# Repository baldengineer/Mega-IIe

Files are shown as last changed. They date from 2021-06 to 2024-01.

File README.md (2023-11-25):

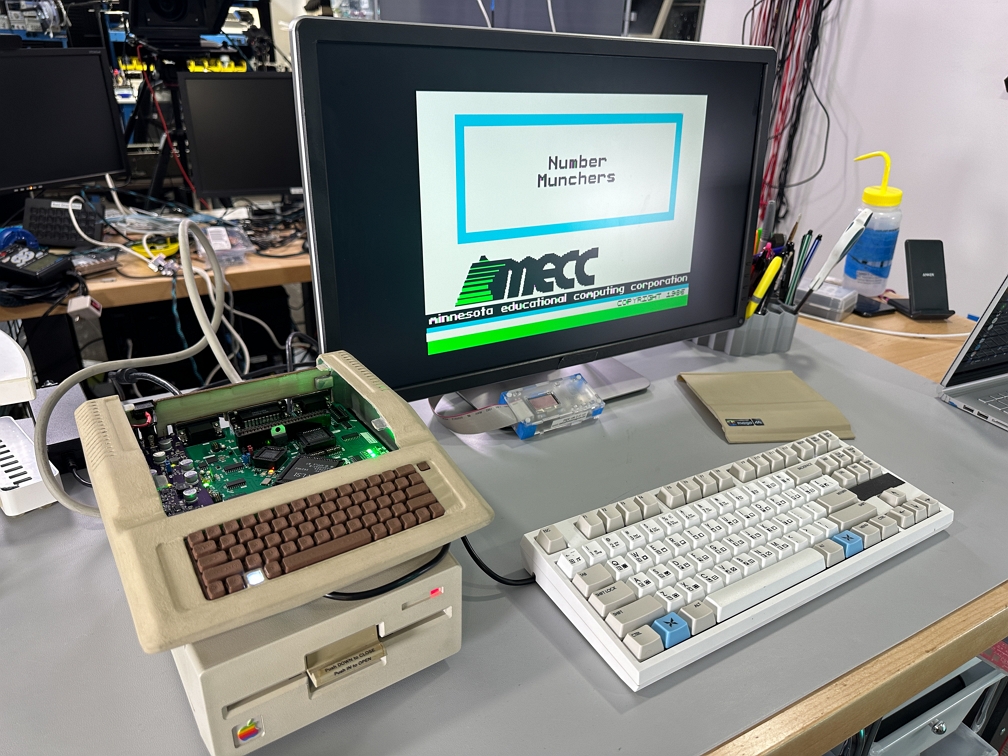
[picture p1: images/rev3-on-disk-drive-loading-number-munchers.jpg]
Mega IIe Rev 3 loading Number Munchers


# Golden Delicious
This project started as a portable Apple ][ by using the Mega-II chip from an IIGS. (This chip is precursor, and slightly different to the Gemini in the Mac LC compatibility card.) However, it evolved into making a miniture Apple IIe compatible computer.

This repo contains the KiCad design files, RP2040 firmware, and notes for the Mega IIe computer. 

## Rev 3 Video
This element14 Presents video documents the effort to get from an Applesoft Prompt to a fully functional computer, in a miniature case.

https://www.youtube.com/watch?v=gFCD4s_hsb4

You can find additional information on the [element14 Community](https://bald.ee/e14-megaiie) or in this [Hackster.io](https://www.hackster.io/news/bald-engineer-s-mega-iie-is-a-modern-miniature-apple-ii-based-on-mega-ii-chip-from-1986-019507d4d10c) article. 

## Bit Preserve
This project is why I started [Bit Preserve](https://github.com/baldengineer/bit-preserve), a project to archive vintage computer schematics.

# Notes
When live streaming the probject, I kept some notes here for future reference.

## (Off-)Stream Notes 2021-10-02
* Attempting to book the GD with a IIc ROM results in a lock-up.
  * graphics get initialized and the memory is dumped to the screen, but no beep and nothing past that.
  * Logic Analyzer suggests `BASICINIT` is doing a monitor version check in the F8 ROM, but failing. It calls a jump called `HANG`. Even though the 6502 should be jumping in a circle, it seems to keep doing other stuff. (Maybe it is just bus fetches that do nothing?)
* SLOTMAKER Bus Headers on the IO board are pinned out different from the SLOTMAKER Bus Header on the MEGA-65c02. For a ribbon cable, each pin-pair needs to be swapped, except for the last two. They are GND.

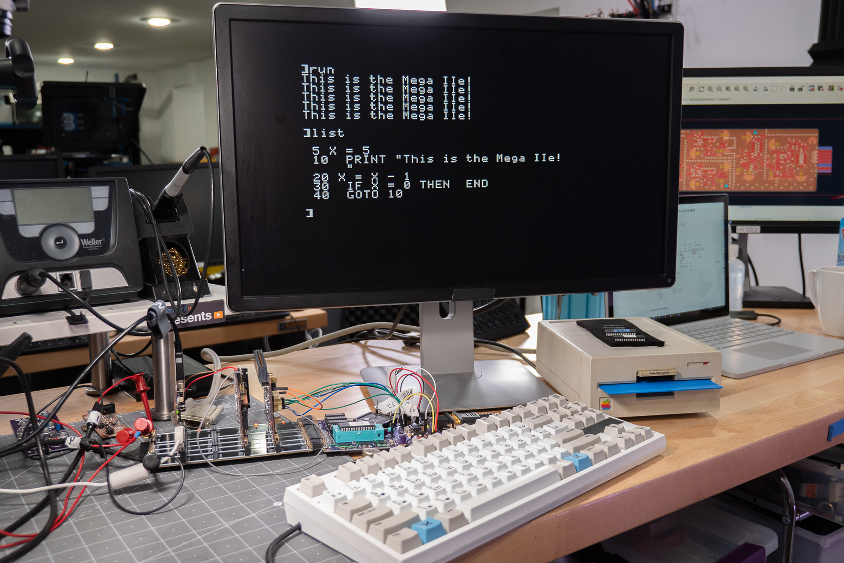
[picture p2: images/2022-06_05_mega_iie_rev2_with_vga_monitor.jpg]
demo of Mega IIe running AppleSoft


## Stream Notes 2021-10-01
Golden Delicious Rev 2 booted! Yay!

* \~DMA is wrong level
  * The two \`245 buffers have their enable pins connnected to \~DMA. I made the mistake of thinking that MEGA drove the \~DMA signal. That is not the case, nor does it make sense after thinking about it. For now, the \`245s have pin 19 lifted and tied to ground to always enable them. 
  * When connecting the IWM or a card to slotmaker, \~DMA situation needs to be resolved.

* [IIe / 6502 decoder](https://discord.com/channels/369243434080272385/843878836471201902/893914917676130314) for Waveforms / Digitial Discovery has been updated. 
* This [forum post](https://discord.com/channels/369243434080272385/843878836471201902/893915436620607488) has Digilent Waveforms beta builds that are downloadable without filling out the annoying registration form. (Or just use `asdf` for all of the fields.)

## Stream Notes 2021-06-02
* Wherefore no IIe ROM in the IIgs? Is it in the MEGA-II?
* [Warphammer: this seciton looks rommy](https://twitter.com/babbageboole/status/1001178057057566720/photo/1)
* rjhelms: that's the big question mark - there could be logic in the Mega II that never actually gets used because the CYA is doing it all in this implementation
* al: keep it all breakouts
* can we decode ROMEN1 and ROMEN2 ourselves?

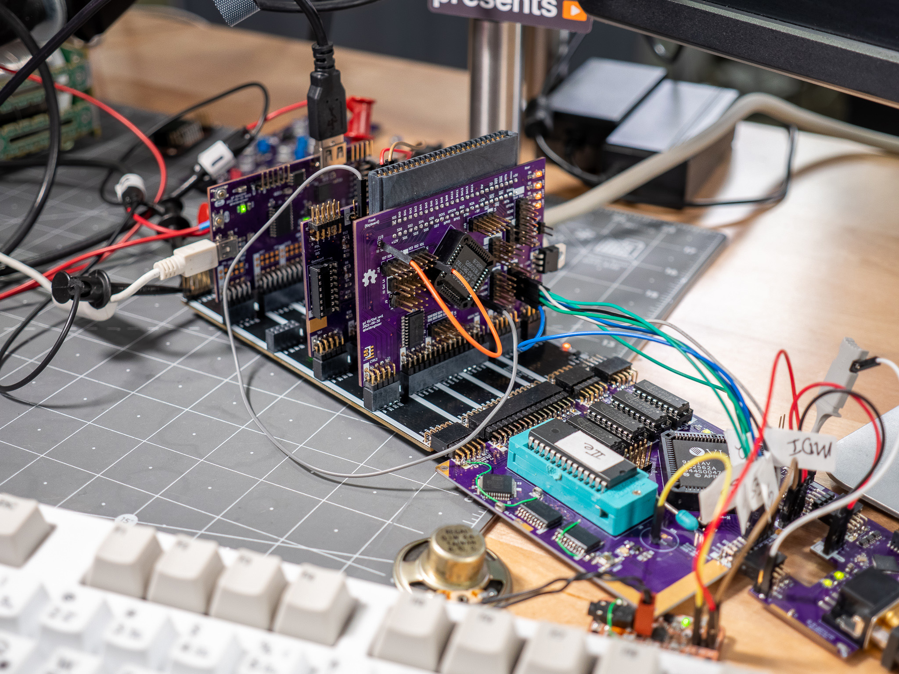
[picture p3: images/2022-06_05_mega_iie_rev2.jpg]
Mega IIe Rev2 Hardware


## Stream Notes 2021-05-19
Things to look at on the scope:
* Composite signal out of the Mega II
* What is Mono-Color from VGC doing to Chroma into MC1377
* Is VGC refreshing apple II DRAM (or is it the Mega)
* why is the 28 MHz oscillator enabled/disabled from the VGC's !SYNC pin?
* [PLCC Pinout Page](https://www.sbprojects.net/knowledge/footprints/plcc/index.php)

### Renesas / IDT OSC: XLH735028.636360I 
* XL H 7 3 5 0 28.636360 I 
  * XL = 1,000,000 af
  * H = LVCMOS En/Dis Pin 1
  * 7 = 7.0 x 5.0 mm
  * 3 = 3.3 VDC
  * 5 = 100ppm for -40C to 105C only on tuesdays when the moon is full and it hasn't rained for a few days. also if you ate green skittles recently *Note1*

### BoM for Protoboards
* [Possible MC1377 Source](https://www.ebay.com/itm/192523168043?hash=item2cd346692b:g:BgIAAOSwWfda4kj6)

## Stream Notes 2021-05-16
* [WDC Application note on using 65C02 in Apple II and other old systems](https://www.westerndesigncenter.com/wdc/AN-002_W65C02S_Replacements.php)
* [65C02 Datasheet](https://www.westerndesigncenter.com/wdc/documentation/w65c02s.pdf)

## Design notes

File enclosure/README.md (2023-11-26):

# Mega IIe STL Files
These are the STLs to re-print the Mega IIe enclosure.

This design is based on this [Apple IIe Model](https://grabcad.com/library/apple-iie-personal-computer-1) by Tommy Mueller on GrabCAD. That model only had faces, so it wasn't as simple as "download and print." And I had to make a few changes to accomodate putting real hardware inside.

## STLs
The final STL versions of each component. The names should be self-explanatory. 

Notes
* Glue (or tape) the Power LED to the back of the keyboard
* Glue the keyboard to the top case.
* Glue RESET key into place.
* Insert the floor panel (with PCB) before putting in the keyboard
* Insert a Speaker (I used one from a IIc) and then glue that piece to the back of the keyboard.

* There is a mix of 2, 3, and 3.5 mm heat inserts. 
* `Stand off for lid` offsets the case from the table for painting.

## Printing Notes
I printed on a Prusa MK3. I did all of the printing before PrusaSlicer supported organic supports.

* Main body needs tons of (traditional) supports. Takes >24 hours to print.
* Lid seemed to do best on its thin side. Otherwise, supports are a pain to clean off.
* Lid may also need to be scaled based on how much paint you add.

## Fusion 360
All of the CAD work was done in Autodesk's [Fusion 360 for personal](https://www.autodesk.com/products/fusion-360/personal).

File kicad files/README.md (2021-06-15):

## Golden Delicious KiCad Files

The Proto PCBs are boards to prototype an IIe from the IIgs ASICs. Eventually, these will be condensed to a single board.

### gd 6502 proto pcb
6502 board is designed for a WDC W65c02 with a QFP footprint. It has a single socket for an EPROM and is wired like the IIc's EEPROM. The `Address` and `Data` headers are meant to connect to the MEGA-II proto board. Other control signals are broken out to other headers.

Runs off of 5V.

### gd MegaII proto pcb
This board is the center piece. It contains the MEGA-II and has all of its signals broken out to multiple headers. 

It connects to both the VGC and 6502 boards. The VGC connects with a 40-pin cable, like an IDE cable. The 6502 connects with a couple of ribbon cables.

Runs off of 5V.

### gd VGC proto pcb
First board to be finished and the one with the least use for the final handheld. The VGC converts the RGB bitstream from the MEGA-II into an analog signal and then into NTSC.

The VGC also generates the 14 MHz clock from a 28 MHz oscilliator. (It is not clear yet which clocks the MEGA-II generates and which the VGC does.)

Runs off of +5V, -5V, and +12V. The 12V and -5V are used by the NTSC generation circuit.

### KiCad_Symbols
Late in the board creation process, I tried to consoliate the symbols into one location. These symbols and these boards are based off of the ROM3 IIgs schematic in [Bit Preserve](https://github.com/baldengineer/bit-preserve).

### MegaII Breakout
Very old breakout board. Created that and realized it wasn't very useful by itself.

## Live Stream
This entire project has been livestreamed on [Bald Engineer Live](https://twitch.tv/baldengineer).

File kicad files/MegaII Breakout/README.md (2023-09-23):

I quickly realized the MEGA-II by itself wasn't going to be a useful breakout. 

So, this board got replaced by the "gd MEGA-II" proto board.

(During KiCad 7 update, multiple symbols were lost. I tried to fix them, but the most recent schematic was not the one used for the pcb!)

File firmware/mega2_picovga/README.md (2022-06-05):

This is the partial project to build the VGA code for the RP2040 in Visual Studio Code.

You need the entire contents of [geekbozu's fork](https://github.com/geekbozu/PicoVGA) of [PicoVGA by Panda381](https://github.com/Panda381/PicoVGA).

The original repo contains many examples and other unnecessary files. However, I don't have time to cull the project and I am uncertain which elements are re-sharable and which are not. 

Sorry if this is confusing. Reach out to me if you need help. I'll do what I can.

## Notes
* Debugger doesn't work because it halts one of the cores. 
* Programming from within VSCode does not upload new code. Have to use J-Flash Lite to upload the `HEX` or `BIN` file.

A minor change is needed to the PicoVGA library to change how SYNC works. As-is, only some VGA monitors work correctly. Well, most. But to use with capture devices, a small patch for V-Sync is needed. [This thread](https://forums.raspberrypi.com/viewtopic.php?t=313634&start=25) discusses the change.

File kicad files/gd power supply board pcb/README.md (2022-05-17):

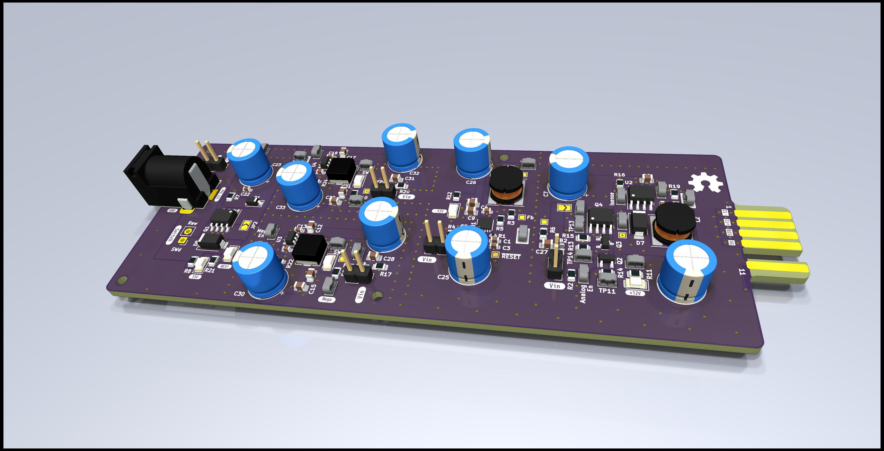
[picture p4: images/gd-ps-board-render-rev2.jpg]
3d render of rev2 power supply board


Four-rail SMPS for the Mega IIe. 

* Always-on 5V supply for the RP2040s and USB
* Switchable 5V for MEGA and other 5V Logic
* Switchable +12/-12V for disk drive and slot

Each 5V supply is designed for >1 Amp. The 12V supply was intended to provide at least 1 Amp. In rev1 testing it *could* provide 1 amp, but only for about 2 minutes. It's steady state max was around 750 mA. 

The -12V supply can only provide a few hundred milliamps. However, in my testing other the analog video circuit used it. At most, it would draw 50 mA but usually sat around 10 mA.

The rev1 design suffered from severe conducted ripple from the 5V switchers. So the rev2 re-design is a 4-layer board with significant ground shielding of input and output rails.

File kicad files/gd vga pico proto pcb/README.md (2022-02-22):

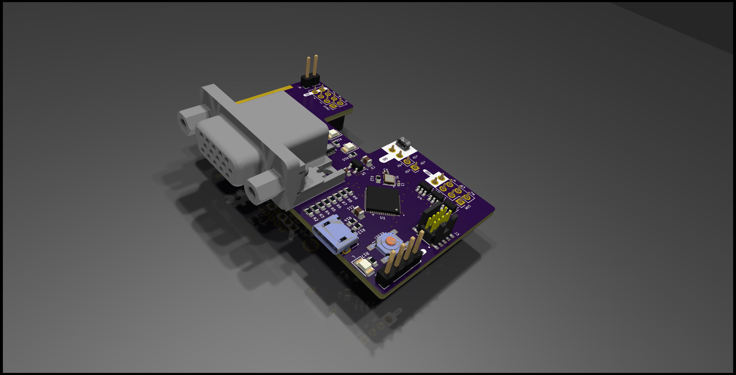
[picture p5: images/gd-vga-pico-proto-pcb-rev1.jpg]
3d render of vga prototype board


## VGA 2040 Proto PCB
The plan for this board is to take the RGBx signals from the Mega-II ASIC and attempt to turn them into a VGA output.

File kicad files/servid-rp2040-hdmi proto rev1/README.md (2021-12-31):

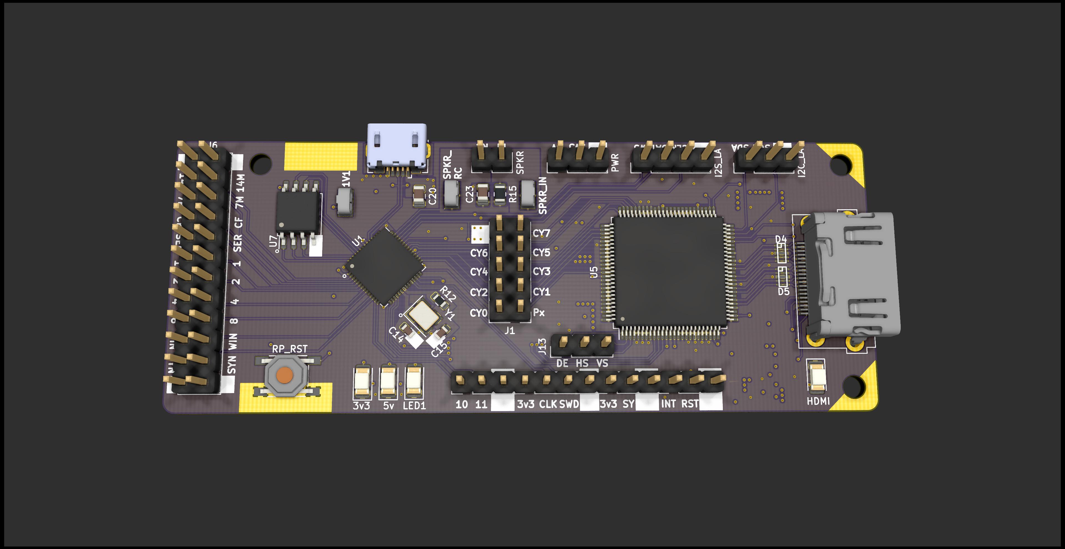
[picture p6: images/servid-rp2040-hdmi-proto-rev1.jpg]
render servid to hdmi adapter


# Apple II SERVID to HDMI Adapter Prototype
Board takes in the video signals from a MEGA-II and (hopefully) outputs HDMI.

Totally untested.

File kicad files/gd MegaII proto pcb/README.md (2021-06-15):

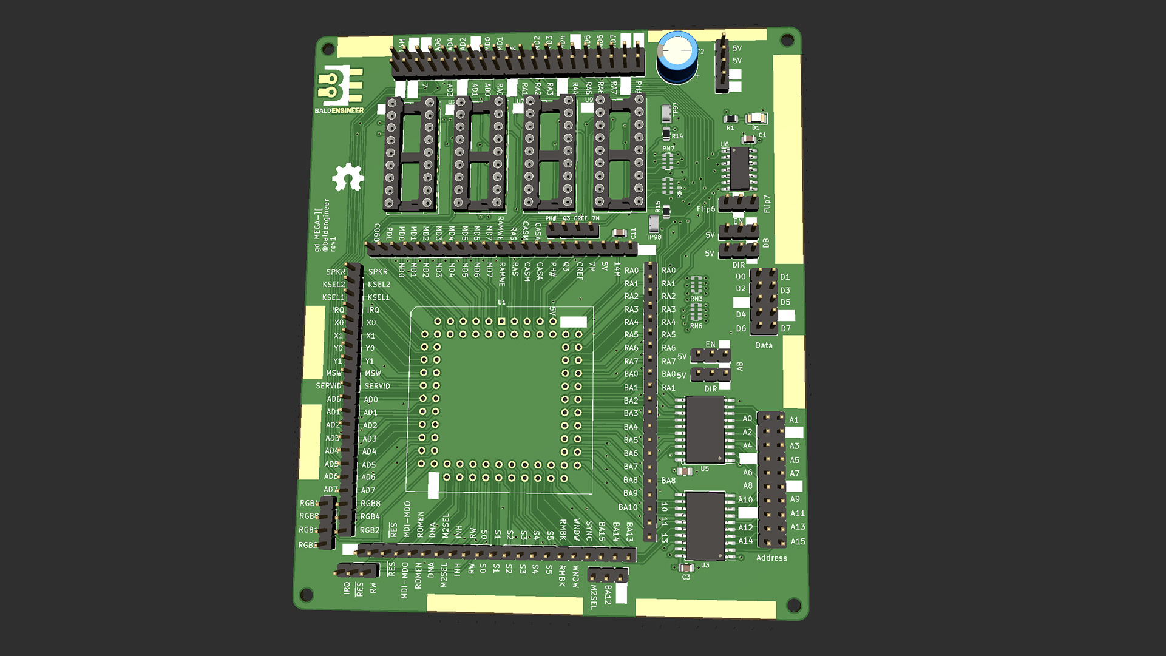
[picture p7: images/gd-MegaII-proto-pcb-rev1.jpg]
MegaII prototype board render


## gd MegaII proto pcb
This board is the center piece. It contains the MEGA-II and has all of its signals broken out to multiple headers. 

It connects to both the VGC and 6502 boards. The VGC connects with a 40-pin cable, like an IDE cable. The 6502 connects with a couple of ribbon cables.

Runs off of 5V.

## Rev1 Notes:
* Nothing... yet :)

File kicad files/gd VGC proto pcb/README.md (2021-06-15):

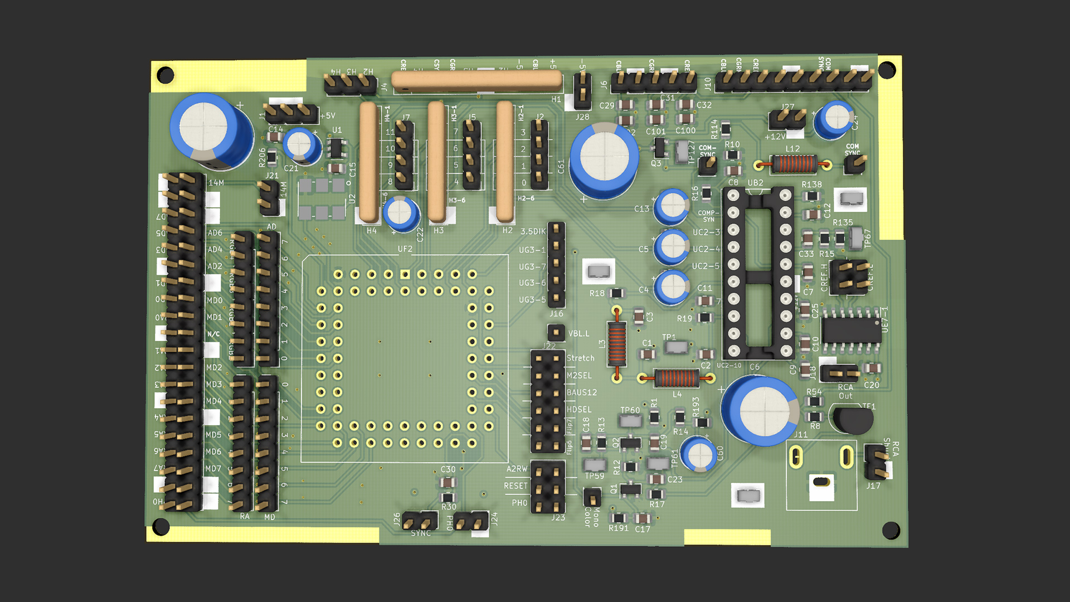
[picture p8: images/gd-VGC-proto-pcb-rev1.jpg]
VGC prototype board render

## gd VGC proto pcb
VGC = Video Graphics Controller

First board to be finished and the one with the least use for the final handheld. The VGC converts the RGB bitstream from the MEGA-II into an analog signal and then into NTSC.

The VGC also generates the 14 MHz clock from a 28 MHz oscilliator. (It is not clear yet which clocks the MEGA-II generates and which the VGC does.)

Runs off of +5V, -5V, and +12V. The 12V and -5V are used by the NTSC generation circuit.

## Rev1 Notes:
* Nothing... yet :)

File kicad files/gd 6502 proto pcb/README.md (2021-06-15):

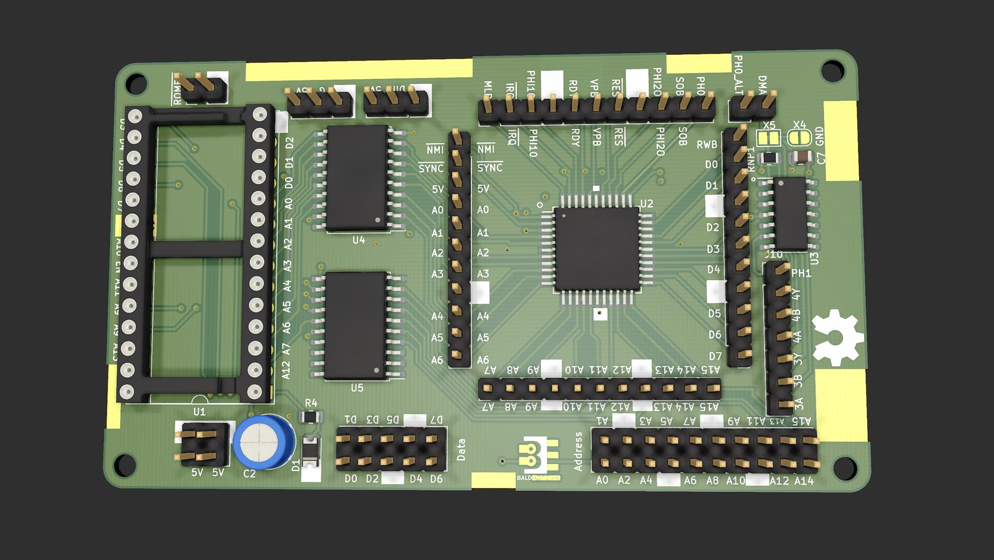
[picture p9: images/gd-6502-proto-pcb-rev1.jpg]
65c02 prototype board render

## gd 6502 proto pcb
6502 board is designed for a WDC W65c02 with a QFP footprint. It has a single socket for an EPROM and is wired like the IIc's EEPROM. The `Address` and `Data` headers are meant to connect to the MEGA-II proto board. Other control signals are broken out to other headers.

Runs off of 5V.

## Rev1 Notes:
* Nothing... yet :)

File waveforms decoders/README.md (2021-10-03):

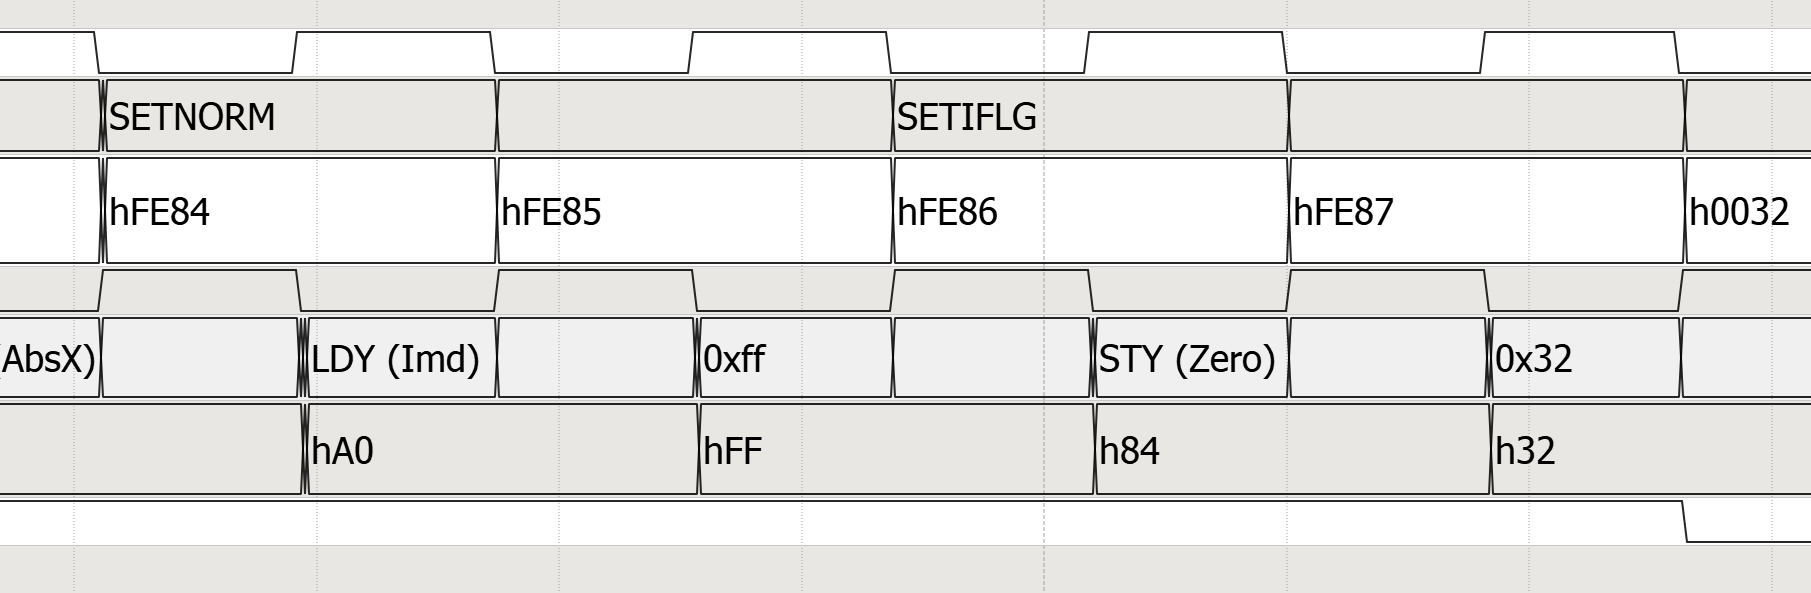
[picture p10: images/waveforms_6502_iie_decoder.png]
Digilent Waveforms decoding 6502 traffic on Apple IIe


# Waveforms Decoders

### Here is the good news: 
These code chunks can decode 6502 op codes and labels from the Apple IIe ROM.

### Here is the bad news: 
It is very poorly written and breaks easy.

## What you need:
* Digilent Digital Discovery 
	* Address and Data needs 24 channels, Analog Discovery 2 only has 15. But if you only wanted one or the other you could look at either Address or Data.
* Waveforms
	* Software that runs the Digital Discovery.
	* This code uses version 3.16.41.
* A way probe address and databus
 * For the [Golden Delicious Project](https://github.com/baldengineer/golden-delicious) we built a custom backplane that the Digital Discovery plugs into.
* For 6502 decode you need ROMEN signal
	* Currently, I use ROMEN because it is available on the MEGA chip. However, the decoder should use and rely on SYNC from the 6502. 
		* FYI, the 6502's SYNC is not related to the video SYNC signal found in the Apple II design
* For IIe ROM Decode, no extra signals are needed
	* Waveforms can use the clock to clean-up states, but I found that to be harder to follow.

## How to use these files:
If you have never written a Waveforms custom decoder, then be ready for some problems. It is finicky to get set up. So here is what I suggest you try.

### Setting up Waveforms Logic Analyzer Notes
First, configure the Logic Analyzer in Waveforms to have the Address and Data bus. I found setting the bus to display in HEX to be easiest to read. To make sure you have your bits setup correctly, trigger on a RESET signal. After 6 or 7 clocks you should see the 6502 attempt to read from 0xFFFC followed by 0xFFFD. The values on the data bus are the low byte and then the high byte of the RESET vector.

In the case of the Apple IIe ROM, the data bytes are 0x62 followed by 0xFA which means the next read should be to 0xFA62. (If you aren't decoding an Apple II ROM, then that vector will be different)

Once your address (and/or) data bus is setup, then add a CUSTOM (bus?). A dialog opens up with with two tabs.

### Setting up the CUSTOM Decoder
It may not be obvious, but the custom decoder essentially ignores all of your labels. The basic example iterates through every sample the logic analyzer took and analyzes the "word" that it sampled. For example, if you are setup to capture 32-bits, your words will be 32-bits. 

If your bits are cleanly going from LSB to MSB and bits 0 to 15 then the decoder is a bit easier to setup. In my case, the bits for both address and data were swizzled. These decoders "de-swizzle" the bits.

### Using the Javascript files
Each of the JavaScript files has two functions in them. One goes into the "Decoder" tab and the other goes into the Value To Text tab. The Value To Text code is a massic switch statement, so make sure you carefully copy the braces at the end.

In both files there is an array called `la_bit`. Give that array the sequential order of Address or Data bits. Depending on how you connect the logic analyzer, you might have to reverse that order to get the decode to work correctly.

In the Value to Text tab/code, there is a return statement commented out. Enabling this statement will cause the CUSTOM decoder to return the value it decoded in HEX. Those HEX values should match what the logic analyzer captured. If not, try reversing the order of your `la_bit` array.

#### Apple IIe ROM Decoder.js
This decoder operates on the 16 bit address bus for the 6502. The Value to Text tab/code has the ROM's symbol table. The decoder has no idea if any part of ROM gets bank switched out so you must use judgement on whether the decode is valid.

#### 6502 decoder.js
Currently this decoder uses the Apple IIe/IIc's/MEGA "ROMEN" signal to determine if a data value is during a code read. The correct method would be to use the 6502's SYNC signal. 

This decoder does have a variable for the ROMEN signal that you must set. Just give it the input number of the logic analyzer. 

## RESET Decode Example
Notice the 6052 RESET sequence: 
* 0xFFFC fetches 0x62 from ROM
* 0xFFFD fetches 0xFA from ROM
* Then a few cycles later, the 6502 jumps to 0xFA62

(Remember *this* specific ROM jumps to 0xFA62. Match the values the LA sees!)
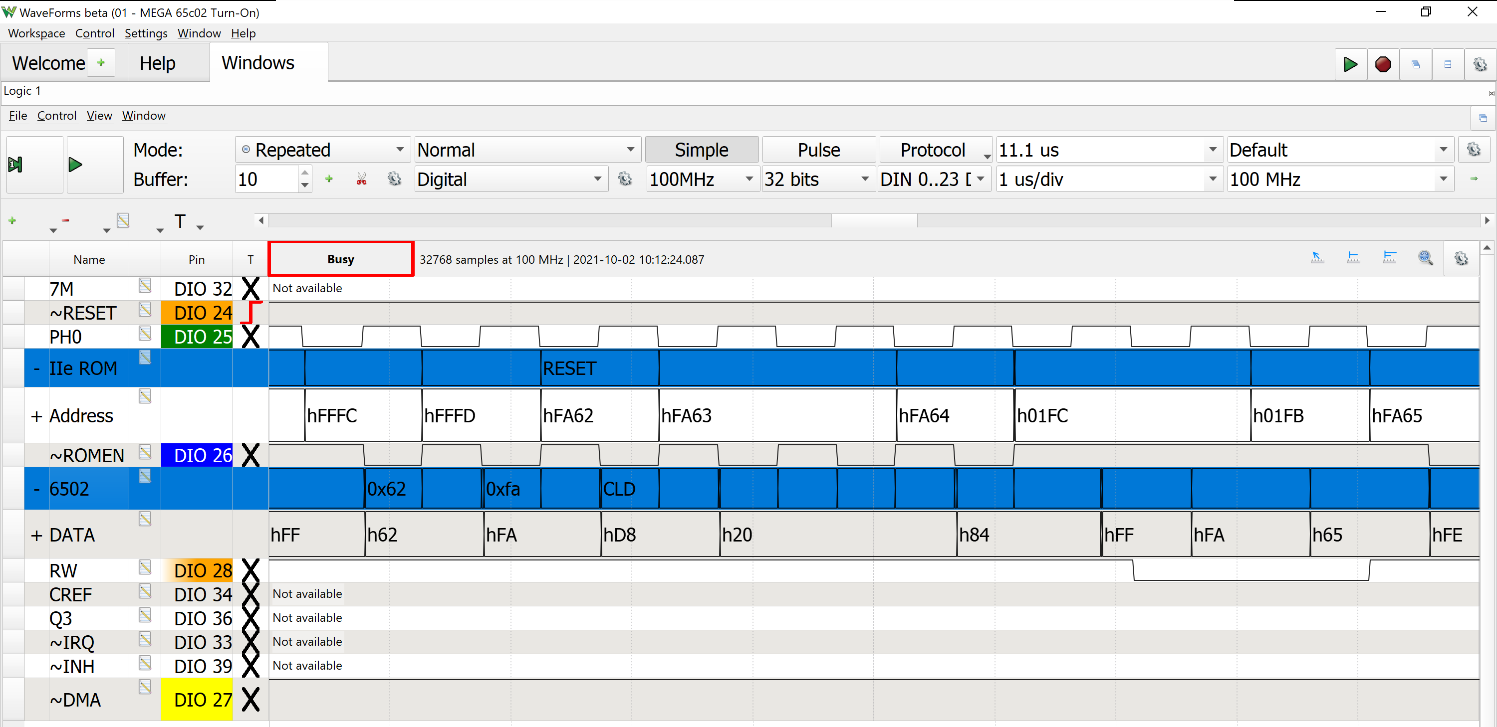
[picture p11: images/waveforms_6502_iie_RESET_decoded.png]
waveforms_6502_iie_RESET_decoded


## Random Apple IIe ROM Decode Example
Just a random part of the Apple IIe boot sequence. Here you can see it setting up a text page in LORES mode. (Probably getting ready to print "Apple ][" at the top of the screen!)

For fun, check out the [Apple IIe ROM Disassembly](https://6502disassembly.com/a2-rom/Unenh_IIe_F8ROM.html). Search for `fb2f:`. The label is `INIT`. The sequence should look familiar. 
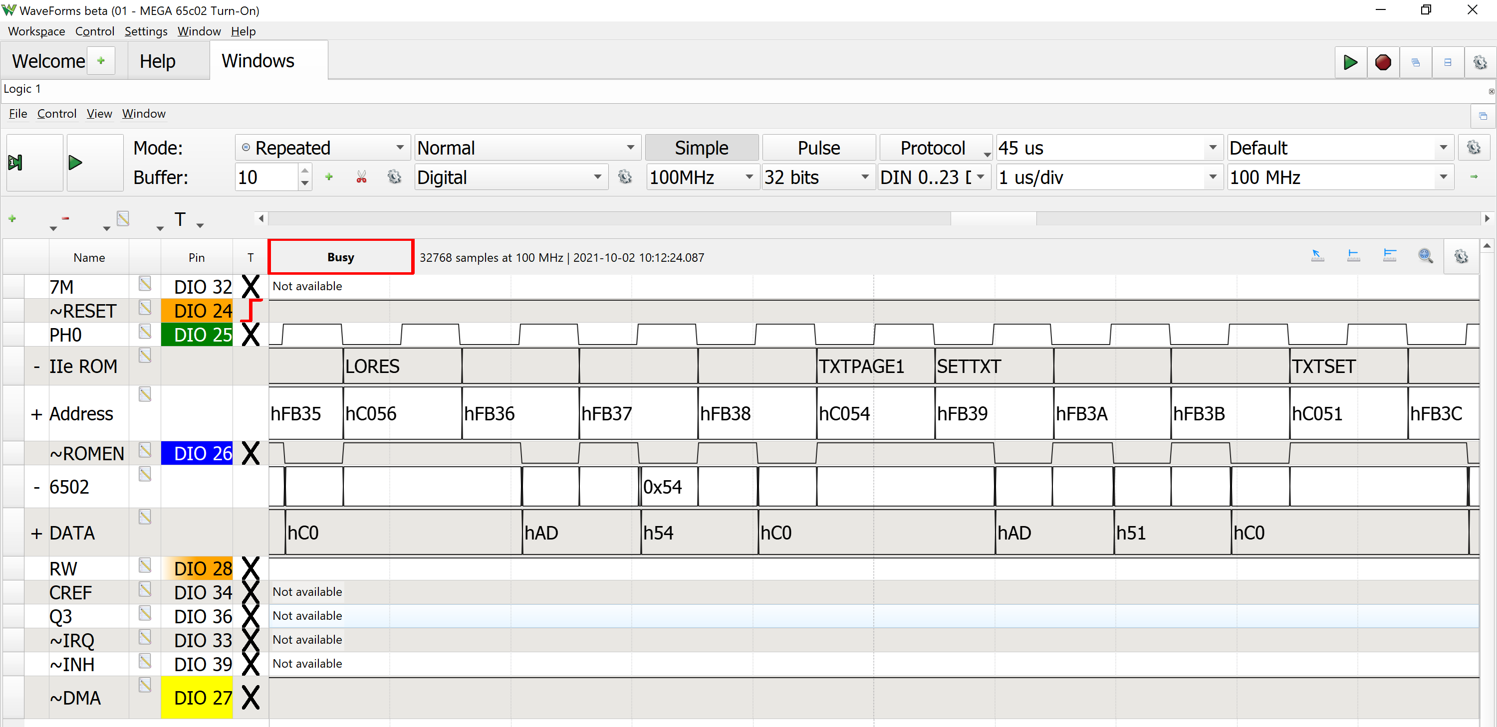
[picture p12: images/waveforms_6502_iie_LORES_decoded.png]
waveforms_6502_iie_LORES_decoded


## Bald Engineer Live Stream
This project is part of Bald Engineer's weekly live streams. 
Watch the stream and help out in chat here:
https://twitch.tv/baldengineer

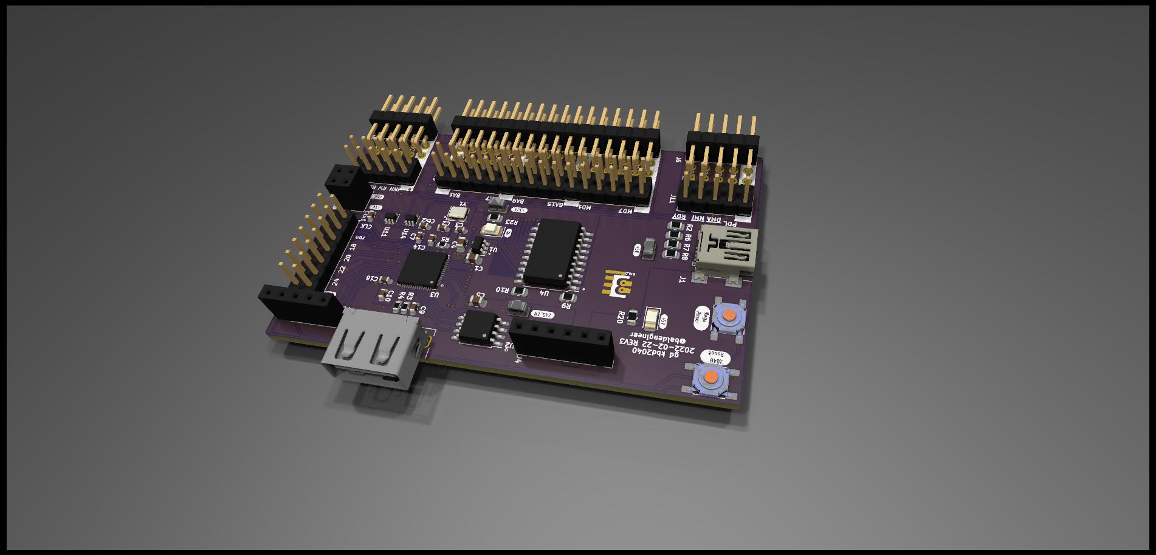
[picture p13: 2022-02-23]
images/gd-rp2040-proto-pcb-rev3-render.jpg

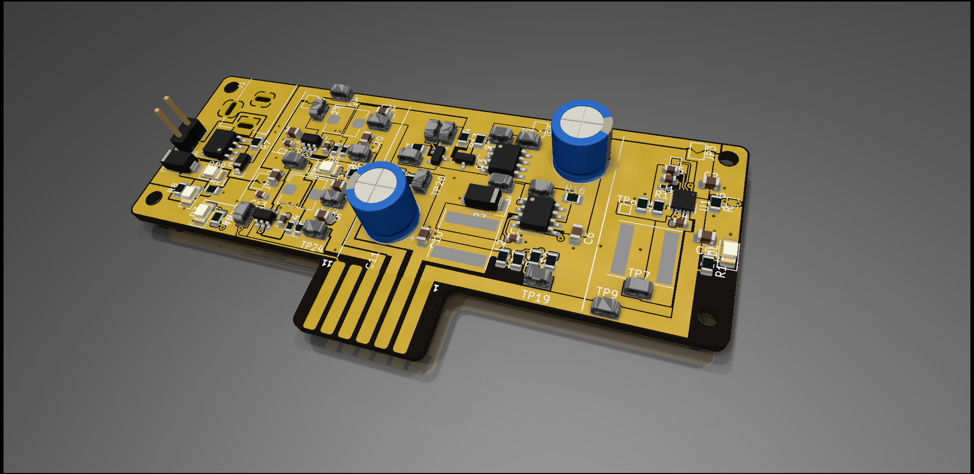
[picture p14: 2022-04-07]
images/gd power supply board pcb rev0 render silk tbd.png

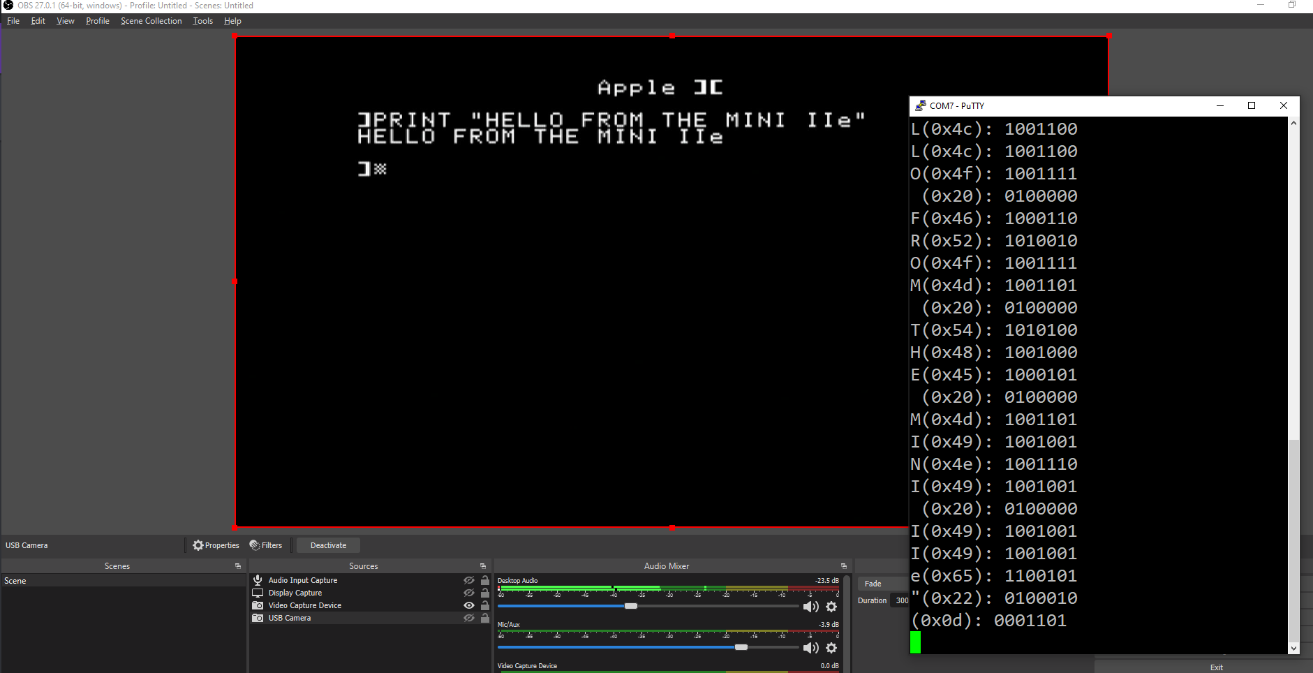
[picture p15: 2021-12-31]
images/hello_from_mini_IIe.png

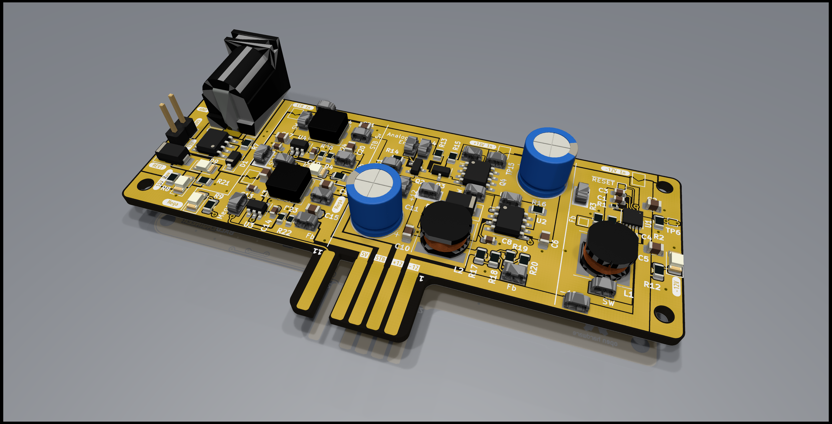
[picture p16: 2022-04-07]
images/gd power supply board pcb rev1.png

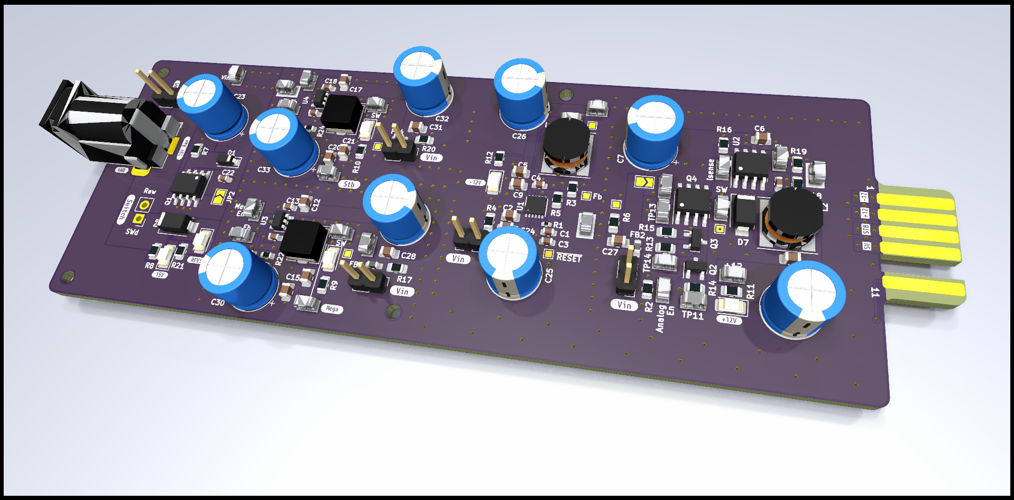
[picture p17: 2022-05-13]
images/gd power supply board pcb rev2 pre fab submit.png

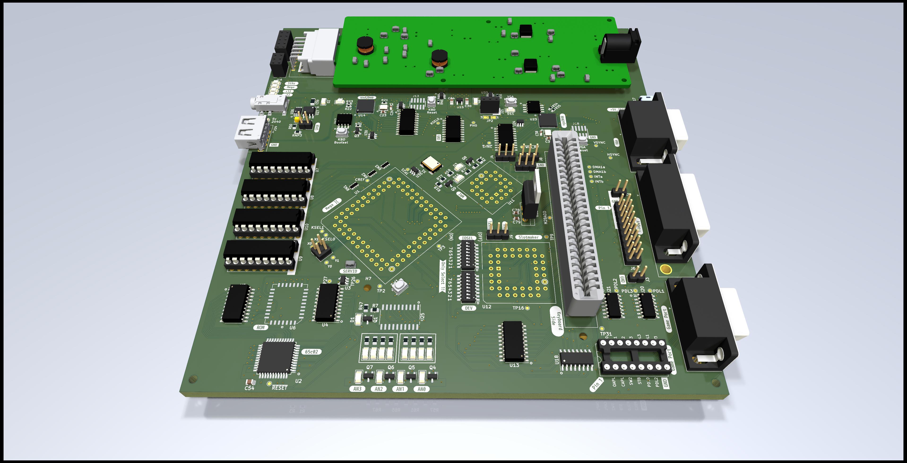
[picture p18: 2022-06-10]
images/2021-06-07_rev3_render.jpg

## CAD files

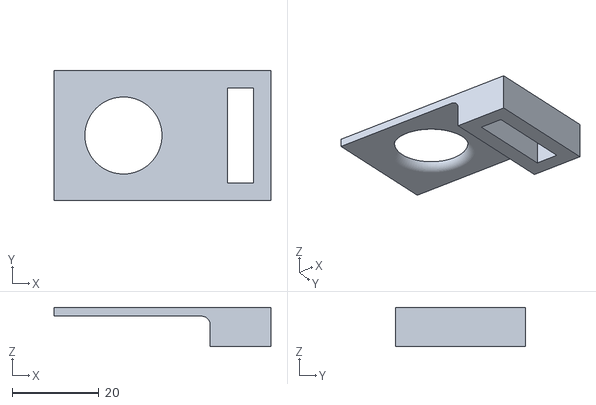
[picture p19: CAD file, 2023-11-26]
enclosure/STLs/speaker mount mk1 v4.stl
50.0 x 30.0 x 9.00

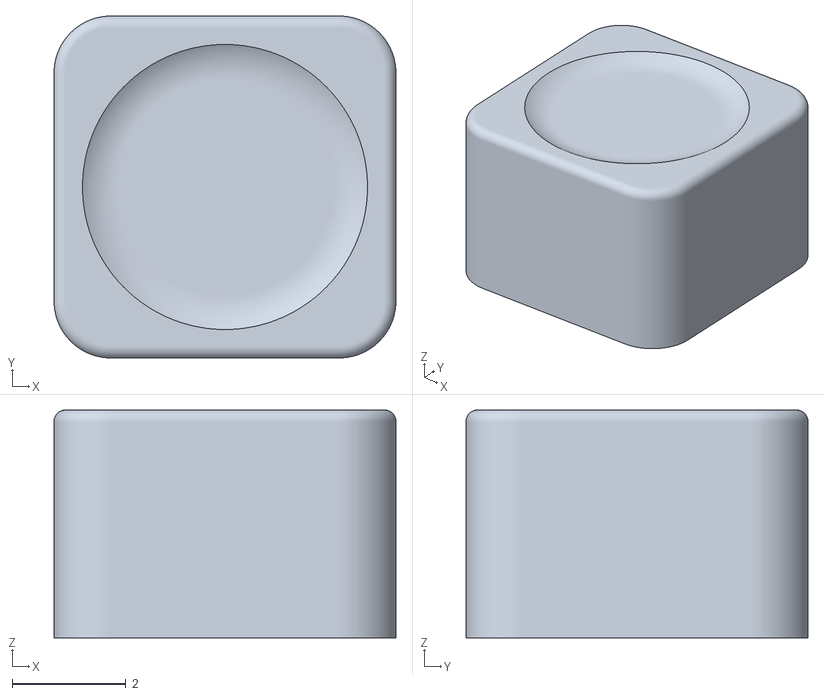
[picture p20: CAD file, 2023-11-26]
enclosure/STLs/Reset Key - Body1.stl
6.00 x 6.00 x 4.00

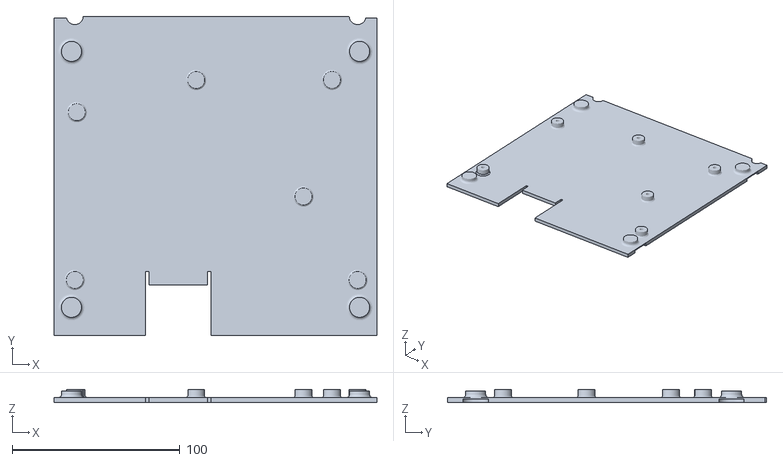
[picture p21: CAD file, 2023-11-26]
enclosure/STLs/Floor - Body66 v4.stl
192.3 x 190.2 x 8.00

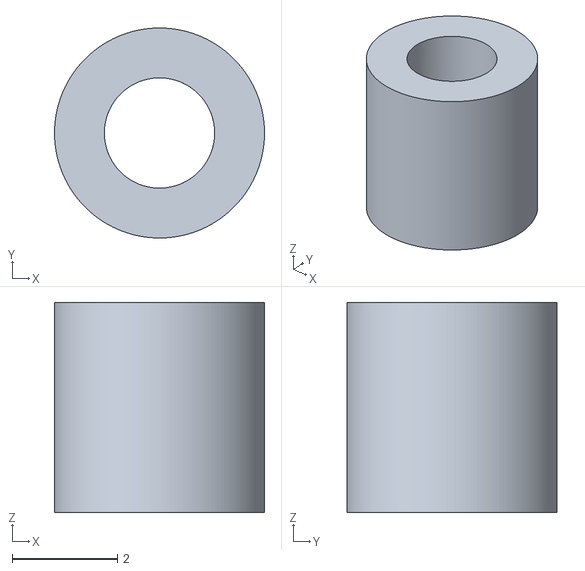
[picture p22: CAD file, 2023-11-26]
enclosure/STLs/PS Standoff v2.stl
4.00 x 4.00 x 4.00

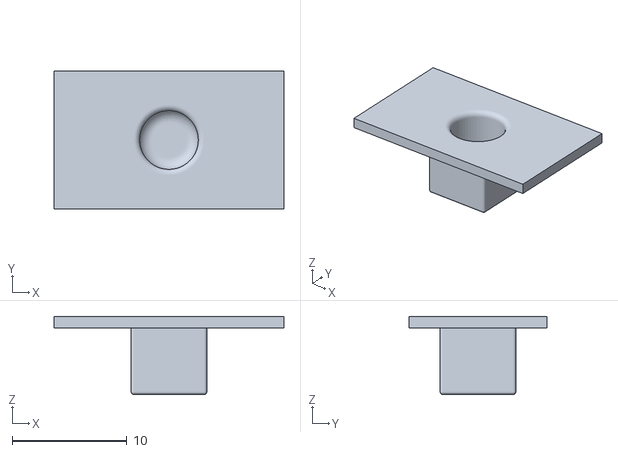
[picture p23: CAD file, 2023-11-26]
enclosure/STLs/Power LED Holder v3.stl
20.0 x 12.0 x 6.80

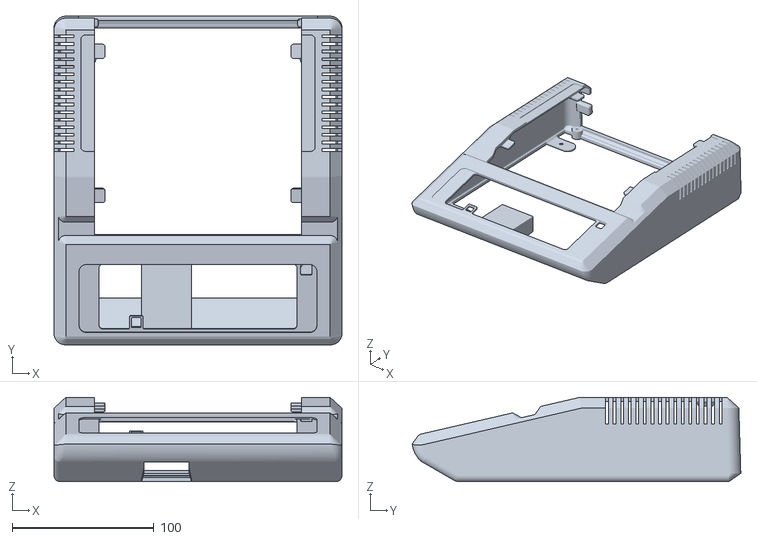
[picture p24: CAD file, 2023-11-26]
enclosure/STLs/Top - Body19v4.stl
202.8 x 231.5 x 59.3

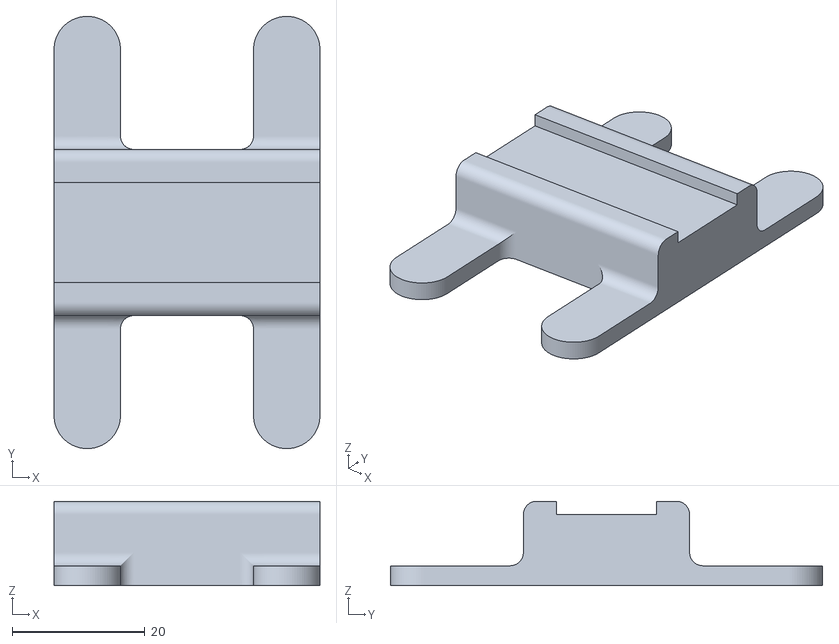
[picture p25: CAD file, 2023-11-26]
enclosure/STLs/Stand Off for lid v1.stl
40.0 x 65.0 x 12.7

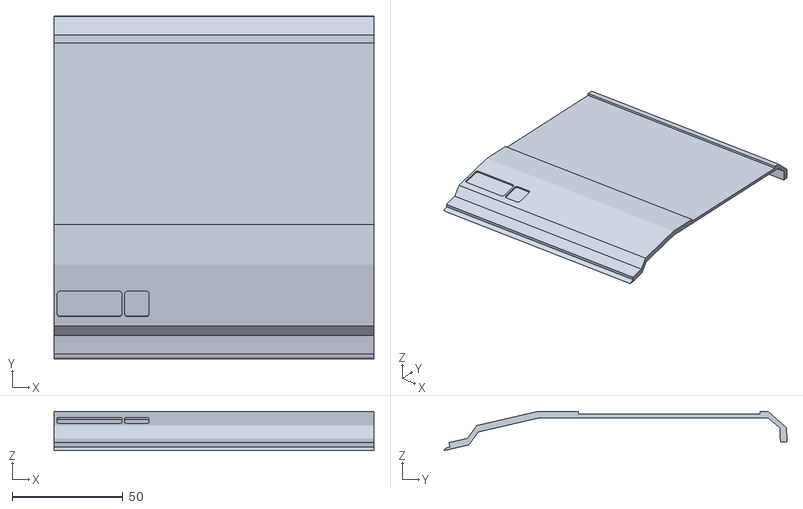
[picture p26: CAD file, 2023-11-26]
enclosure/STLs/Lid - Body34 rev3.stl
144.1 x 154.6 x 17.7

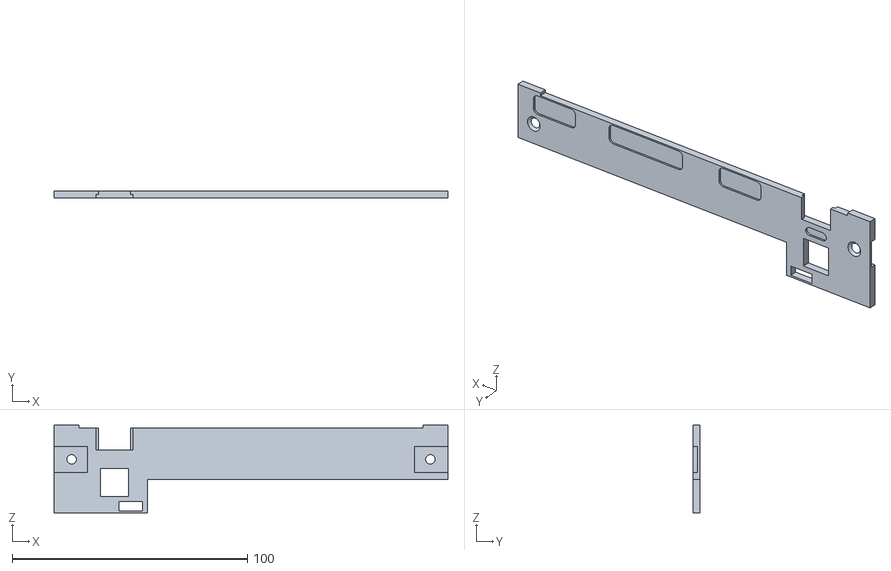
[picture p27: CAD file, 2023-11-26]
enclosure/STLs/Rear Panel - Body1 v5.stl
167.4 x 3.00 x 37.3

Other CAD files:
enclosure/Fusion 360/Back Panel for export mk2 v1.f3d
enclosure/Fusion 360/PS Standoff v3.f3d
enclosure/Fusion 360/Power LED Holder v8.f3d
enclosure/Fusion 360/reset keys v2.f3d
enclosure/Fusion 360/speaker mount mk1 v4.f3d
enclosure/Fusion 360/standoff for lid v3.f3d

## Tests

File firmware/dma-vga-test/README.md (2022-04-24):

Project to test capturing Mega II's RGBx signals to convert to VGA video.

For now, the goal is to use the PIO to capture an entire frame of video, DMA to memory buffer, and then export that for analysis. (i.e. not going for motion, but still frames.)

This work should lay the foundation for wiring into the PicoVGA library.

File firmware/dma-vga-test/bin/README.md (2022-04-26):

dma-vga-test.7z contains dma-vga-test.uf2 for Pi Pico.

vid30 ... is a Digilent Waveforms Workspace. It's intended for a Digital Discovery. It contains a pattern generator that creates a single line of simulated Apple II video. 

For now, the RGBx lines are just a counter for analysis on the PIO code.

example memory dumps from vga2040.7z are some dumps that work with the txt_to_png python script.

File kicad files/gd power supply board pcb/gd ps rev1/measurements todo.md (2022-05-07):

(remove +12 jumper)
(remvoe barrel jack jumper)

## Resistance
Check Vin jumpers resistance

## Mega_5V
Vin + FB

## +12 V 
### Analog Enable Circuit
Vin + 15V_SW 
TP13/TP14 + Vin

## Remember to verify
Power-On sequence (how long does it take ripple to drop)

Changes:
1. FB Network (divide/10)
2. Attempt to "gnd" output node

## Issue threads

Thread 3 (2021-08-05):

MEGA-II rev1: remove NOR circuit

baldengineer, 2021-08-05:
Flip 6/7 NOR circuit may need to be removed (pending video mode tests)

baldengineer, 2022-07-30:
Closing this because I never figured out what it did and the Mega IIe doesn't seem to need it. lol

Closed 2022-07-30.

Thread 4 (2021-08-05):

MEGA-II rev1: Signals to Pull

baldengineer, 2021-08-05:
- Pull-Up
    - MSW

- Pull-Down
     - Flip 6
     - Flip 7

- Verify
     - IRQ (connect to CPU?)
     - RES (connect to CPU?)
     - RW (connect to CPU?)
     - DMA
     - INH
     - M2SEL (RESET circuit?)

baldengineer, 2021-10-03:
* MSW
     * Test signal for the MEGA.
     * Pulled High in Rev2

* Flip 6 / 7
     * In Rev2, still have not determined what the purpose of these signals are

* IRQ, NMI, RDY
     * Pulled High in Rev2

* M2SEL
     * Currently pulled low in Rev2. (However, RESET is not working, so this may need to be changed.)

* DMA
     * Something (MEGA?) is holding DMA high.

* RW
     * Always being driven, doesn't need to be pulled.

Closed 2021-10-03.

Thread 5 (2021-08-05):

65c02 rev1: pulled signals

baldengineer, 2021-08-05:
- Pull-Up:
 - BE
 - RDY (done)
 - NMI (done)
 - IRQ (done)
 - RES? (through reset circuit?)
 -

baldengineer, 2021-10-03:
basically duplicate of #4.

RESET is held up by a 4k7 next to the reset button.

Closed 2021-10-03.

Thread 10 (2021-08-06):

Mega-II and VGC rev1: Shourded 40-pin connector covers silk screen

baldengineer, 2021-08-06:
Although the "IDE-style" connector makes connecting the ribbon cable easier, it obscures the silk screen of the pins.

baldengineer, 2021-10-03:
40-pin connector has been replaced by rev2's backplane design.

But should consider shroud in future board designs.

Closed 2021-10-03.

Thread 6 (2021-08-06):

VGC rev1: Bad footprint for TF1

baldengineer, 2021-08-06:
For the capacitive transformer / EMI filter we used a TO-3 footprint. The holes are too close together and two small to drop-in TF1 from a working IIgs.

baldengineer, 2021-08-06:
The VGC works fine without the filter. Tested on both the VGC board and a real IIgs.

Closed 2021-10-03.

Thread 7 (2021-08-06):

VGC rev1: Messed up M2SEL / 3.5DIK Headers

baldengineer, 2021-08-06:
One of the headers was accidentally flipped before sending the boards to OSHpark.

The board is still, somewhat, usable with the use of a dremel.

baldengineer, 2021-10-03:
The video board is temporary until we figure out an HDMI solution. Unfortunate mistake, but most of the board works fine.

Closed 2021-10-03.

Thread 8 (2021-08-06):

Mega-II rev1: DIR/EN silkscreen for the address and data busses are backward

baldengineer, 2021-08-06:
The header pins labeled EN are actually the DIRection and vice versa. This applies to the header pins for both the address and
 data bus.

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

baldengineer, 2021-10-03:
Future boards won't have these headers and properly use buffers.

Closed 2021-10-03.

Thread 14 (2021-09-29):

[rp2040] Buffer Full Assertion

baldengineer, 2021-09-29:
sending a bunch of LED on and off commands, eventually, get a buffer full message:
`
assertion "buf_ctrl & USB_BUF_CTRL_FULL" failed: file "C:\Users\balde\Documents\Pico\pico-sdk\lib\tinyusb\src\portable\raspberrypi\rp2040\rp2040_usb.c", line 225, function: sync_ep_buffer
`

baldengineer, 2022-02-14:
Newer version of the TinyUSB library seems to have fixed the assertion. (Or is it still commented out?)

baldengineer, 2022-04-04:
Unclear, but I don't think we've had this issue recently.

baldengineer, 2022-07-30:
Rev 3b is working very well, not sure if this is still an issue. Need to investigate later.

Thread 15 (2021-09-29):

[MEGA-65c02] Oscillator Footprint is wrong (it is for a crystal)

baldengineer, 2021-09-29:
The 7mm x 5mm crystal footprint is different from the one for oscillators. The pins are numbered differently. Need to fix the GD board and possibly make an adapter for the oscillators I do have now.

baldengineer, 2021-10-03:
Upon further discovery, it was pinned out as if looking from the top instead of bottom. (Or other way around.) Needs a different foot print to match the oscillator.

baldengineer, 2022-02-14:
Breakout board created for Mega-65c02 board. Fixed issue on the Rev3 schematic/footprint/pcb.

Closed 2022-02-14.

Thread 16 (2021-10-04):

[kbd_bbd] '245 only has 7 bits, should be 8

baldengineer, 2021-10-04:
Need to connect the entire main data bus because `C010` switch relies on `BIT7` to know if there was a new key.

baldengineer, 2022-02-14:
Fixed in the Rev2 of the KBD2040 board.

Closed 2022-02-14.

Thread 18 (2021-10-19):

[io board] Slotmaker signals are wired wrong (backward)

baldengineer, 2021-10-19:
In the schematic, the SBUSx signals are backward. For example, SBUS0 connects to SBUS5 on the chip/socket.

baldengineer, 2022-07-30:
Note, in Reb 3b, the signals were wired "correctly." Communication between slotmaker and mega-II is working well.

But may need to rev the slotmaker board to fix the DEVx problem.

Closed 2023-03-11.

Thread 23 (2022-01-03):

rev 2 RP2040: TXB0108 is active high

baldengineer, 2022-01-03:
The left shifter for control signals is active high on OE. There is a pull-up resistor on-board. (Can still be controlled by TXen pin/GPIO 25).

baldengineer, 2022-02-14:
Rev 2 of the KBD2040 board fixes this issue.

Closed 2022-02-14.

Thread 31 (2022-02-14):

[IWM Board] - Joystick circuit Missing capacitors for NE556 circuit

baldengineer, 2022-02-14:
PDLx signals need 22 nF capacitors connected from PDLx to ground.

baldengineer, 2022-02-14:
Bodged some 0805 capacitors on to existing protoboard, circuit works as expected with them. Leaving open until verified if fixed on Rev3--in case we re-use the circuit.

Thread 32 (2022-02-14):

[IWM Board] - Joystick circuit need to connect signals to simulate NE558

baldengineer, 2022-02-14:
Original IIe and IIgs used a NE558 chip, which is no longer available.

When using 556 replacements, it is necessary to connect the discharge and PDL pins together. On the existing schematic, this means shorting together DISx and PDLx. On the protoboard, we shorted these signals together on the header pins. (So Logic Analyzer could be connected.)

Leaving this issue open until implemented on Rev3 schematic (if we plan to use it.)

baldengineer, 2023-12-01:
I don't plan to make a new rev2 IWM board. If I do, I'll re-address this one.

Closed 2023-12-01.

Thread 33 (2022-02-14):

Number Munchers - Fails to boot

baldengineer, 2022-02-14:
After the title screen loads, a crash into the monitor is heard. It does not seem possible to get back to the monitor prompt.

Need to trace with LA and see what it is trying to call.

baldengineer, 2022-04-04:
Related to #43. Doing a quick fix allows Appleworks to work correctly.

Closed 2022-04-04.

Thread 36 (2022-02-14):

Bitsy Bye: Crashes when accessing S3, D1

baldengineer, 2022-02-14:
Using tab to change drive device causes a crash into the `0x2000` area when the software tries to access Slot 3, Disk 1.

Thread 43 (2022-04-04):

Mega-II asserts KSELx siganls when decoding any Cxxx address under certain conditions!

baldengineer, 2022-04-04:
Based on the scope captures, it appears to be a decode glitch that occurs during the video phase of PH0.

The accesses appear to only happen when Disk ][ code runs, but I haven't figured out the exact conditions.

baldengineer, 2022-04-04:
The solution under test is to modify the KBD2040 board to gate KSEL based on PH0.

We considered doing it in the RP2040's PIO, but decided it was probably better to do so in hardware.

baldengineer, 2022-07-30:
Third revision of the KBD2040 fixed the issue! AND without any changes to the PIO code! Hype!

Closed 2022-07-30.

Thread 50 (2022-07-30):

EEPROM Wired Wrong

baldengineer, 2022-07-30:
- The AT28C256 is wired with `/OE` tied `HIGH`, it should be connected to `/ROMEN`
- The AT28C256 `/CE` is connected to `/ROMEN`, which is fine, but should be connected to `GND`.

Also, I hate PLCC32. That is all.

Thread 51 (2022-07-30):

IWM Disk Activity LEDs are inverted

baldengineer, 2022-07-30:
The disk activity LEDs are ON when the drive is not active and OFF when the drive is active.

Low priority but strange to see.

baldengineer, 2023-10-19:
Schematic updated

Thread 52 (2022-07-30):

OAPL and CAPL keys conlfict with SW1 and SW0 on paddles

baldengineer, 2022-07-30:
The OPAL and CAPL buffer is a 74LVC04 (back-to-back). It should be a 74LVC06 with open-drain outputs and then tied high.

The reason this matters is that the Gameport uses those two signals as buttons and they pull the signal to ground. So it creates a short situation. Open drain fixes it.

baldengineer, 2022-08-01:
Updated title. Originally though an open-drain driver was needed on the CAPL and OAPL signals from the RP2040. This assumption was incorrect.

First, the Paddles have a 590-ohm pulldown resistor and connect the SWx signal to 5V.

The proposed solution is to go back to 74LVC04 drivers and add a series resistor to the SWx_xPL signals.

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

This simulation seems to agree this is workable

baldengineer, 2022-08-06:
Instead of 470-ohm resistor, we tested with a diode. Works fine. Also need to add pulldown AFTER the diode!

baldengineer, 2023-10-19:
add schottky and pull-down to 3b

Closed 2023-12-01.

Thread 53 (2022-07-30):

If doing a Rev 3c, add on-board LED for KBD2040

baldengineer, 2022-07-30:
The "LED Pin" of KBD2040 goes to a headed intended for an LED on the case.

Lack of on-board LED makes debug work difficult without attaching something.

baldengineer, 2023-10-19:
added led with 4k7

Closed 2023-12-01.

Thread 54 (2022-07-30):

Increase pad lengths

baldengineer, 2022-07-30:
On 65C02, PLCC32 socket, dip switches, and QFN consider larger pads.

Just hard to hand solder as is.

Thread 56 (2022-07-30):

RP2040s don't boot if Mega's 5V rail comes up first

baldengineer, 2022-07-30:
I think there is a back powering issue that is causing the RP2040s BOD to disable them?

In practice, this is not an issue since the Mega supply is controlled by the RP2040s.

I also suspect it is one of the buffers that are pulled-up to the Mega 5V rail while connected to the RP2040 5V rail. (maybe?)

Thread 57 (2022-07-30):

[io board] DEVx is hard wired to slot 1

baldengineer, 2022-07-30:
While IOSEL has a header, DEV is hardwired to DEV 1 from Slotmaker. (Or the other way around.)

If doing a second version, make it possible to change the selections.

Closed 2023-03-11.

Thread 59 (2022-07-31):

Consider 5V selector for Floppy

baldengineer, 2022-07-31:
It'd be nice to have the Floppy drive powered from RP2040's 5V rail when using the Floppy EMU. Maybe a header?

baldengineer, 2023-10-07:
Current James would like to vote +1 on this idea. (I almost made another issue for this idea.)

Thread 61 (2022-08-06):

I2C Digipot should be powered by 5V_2040

baldengineer, 2022-08-06:
In Rev 3b, the pot is powered by the Mega 5V Rail, which means the RP2040 cannot configure it until after power has been applied.

baldengineer, 2023-10-19:
Schematic Updated

Closed 2023-12-01.

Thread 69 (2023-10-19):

decoder and ANx LEDs are way too bright

baldengineer, 2023-10-19:
Using green LEDs with 470 ohms should be illegal.

baldengineer, 2023-10-19:
change limiting resistors to 4k7. If 3v3 becomes available down in that area, then reduce these to 1k.

baldengineer, 2023-10-19:
address decoder changed to 1K resistors and '573 driving them dropping to 3v3 (if routable)

Closed 2023-12-01.

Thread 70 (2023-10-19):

Decoder LEDs are driven by LVC573, driven by 5V

baldengineer, 2023-10-19:
Looks like [SN74LVC ](https://www.ti.com/lit/ds/scas300s/scas300s.pdf)cannot operate with 5V! Whoops.

baldengineer, 2023-10-19:
this will also help address the brightness

baldengineer, 2023-10-19:
Actually, gave this some thought. I remember doing this on purpose now. I think routing 3v3 down to where the decoder was located was difficult. So I decided to drive the LVC373 with 5V since it's absolute max is >5.5V.

Closed 2023-12-01.

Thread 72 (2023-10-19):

LEDs are using Diode symbol

baldengineer, 2023-10-19:
minor issue, but I used a diode symbol. Should replace them with LED symbol for consistency.

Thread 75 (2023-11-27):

Add jumper and resistor for dual-mode floppy emu (20-pin)

baldengineer, 2023-11-27:
Floppy Emu supports dual-drives on 20-pin header with a 470 ohm hack.

https://shop.bigmessowires.com/products/dual-525-adapter-for-disk-ii-interface-card

Add resistor and header to enable this support on the 20pin.

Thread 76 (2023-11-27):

pin 16 of the db19 should have a jumper to 5 volts, not ground

baldengineer, 2023-11-27:
pin 16 goes to 5V (when used). the current jumper allows for easy connection to gnd, which is probably bad.

if room allows, make it a selectable 5V or GND.

baldengineer, 2023-12-01:
Fixed with #77

Closed 2023-12-01.

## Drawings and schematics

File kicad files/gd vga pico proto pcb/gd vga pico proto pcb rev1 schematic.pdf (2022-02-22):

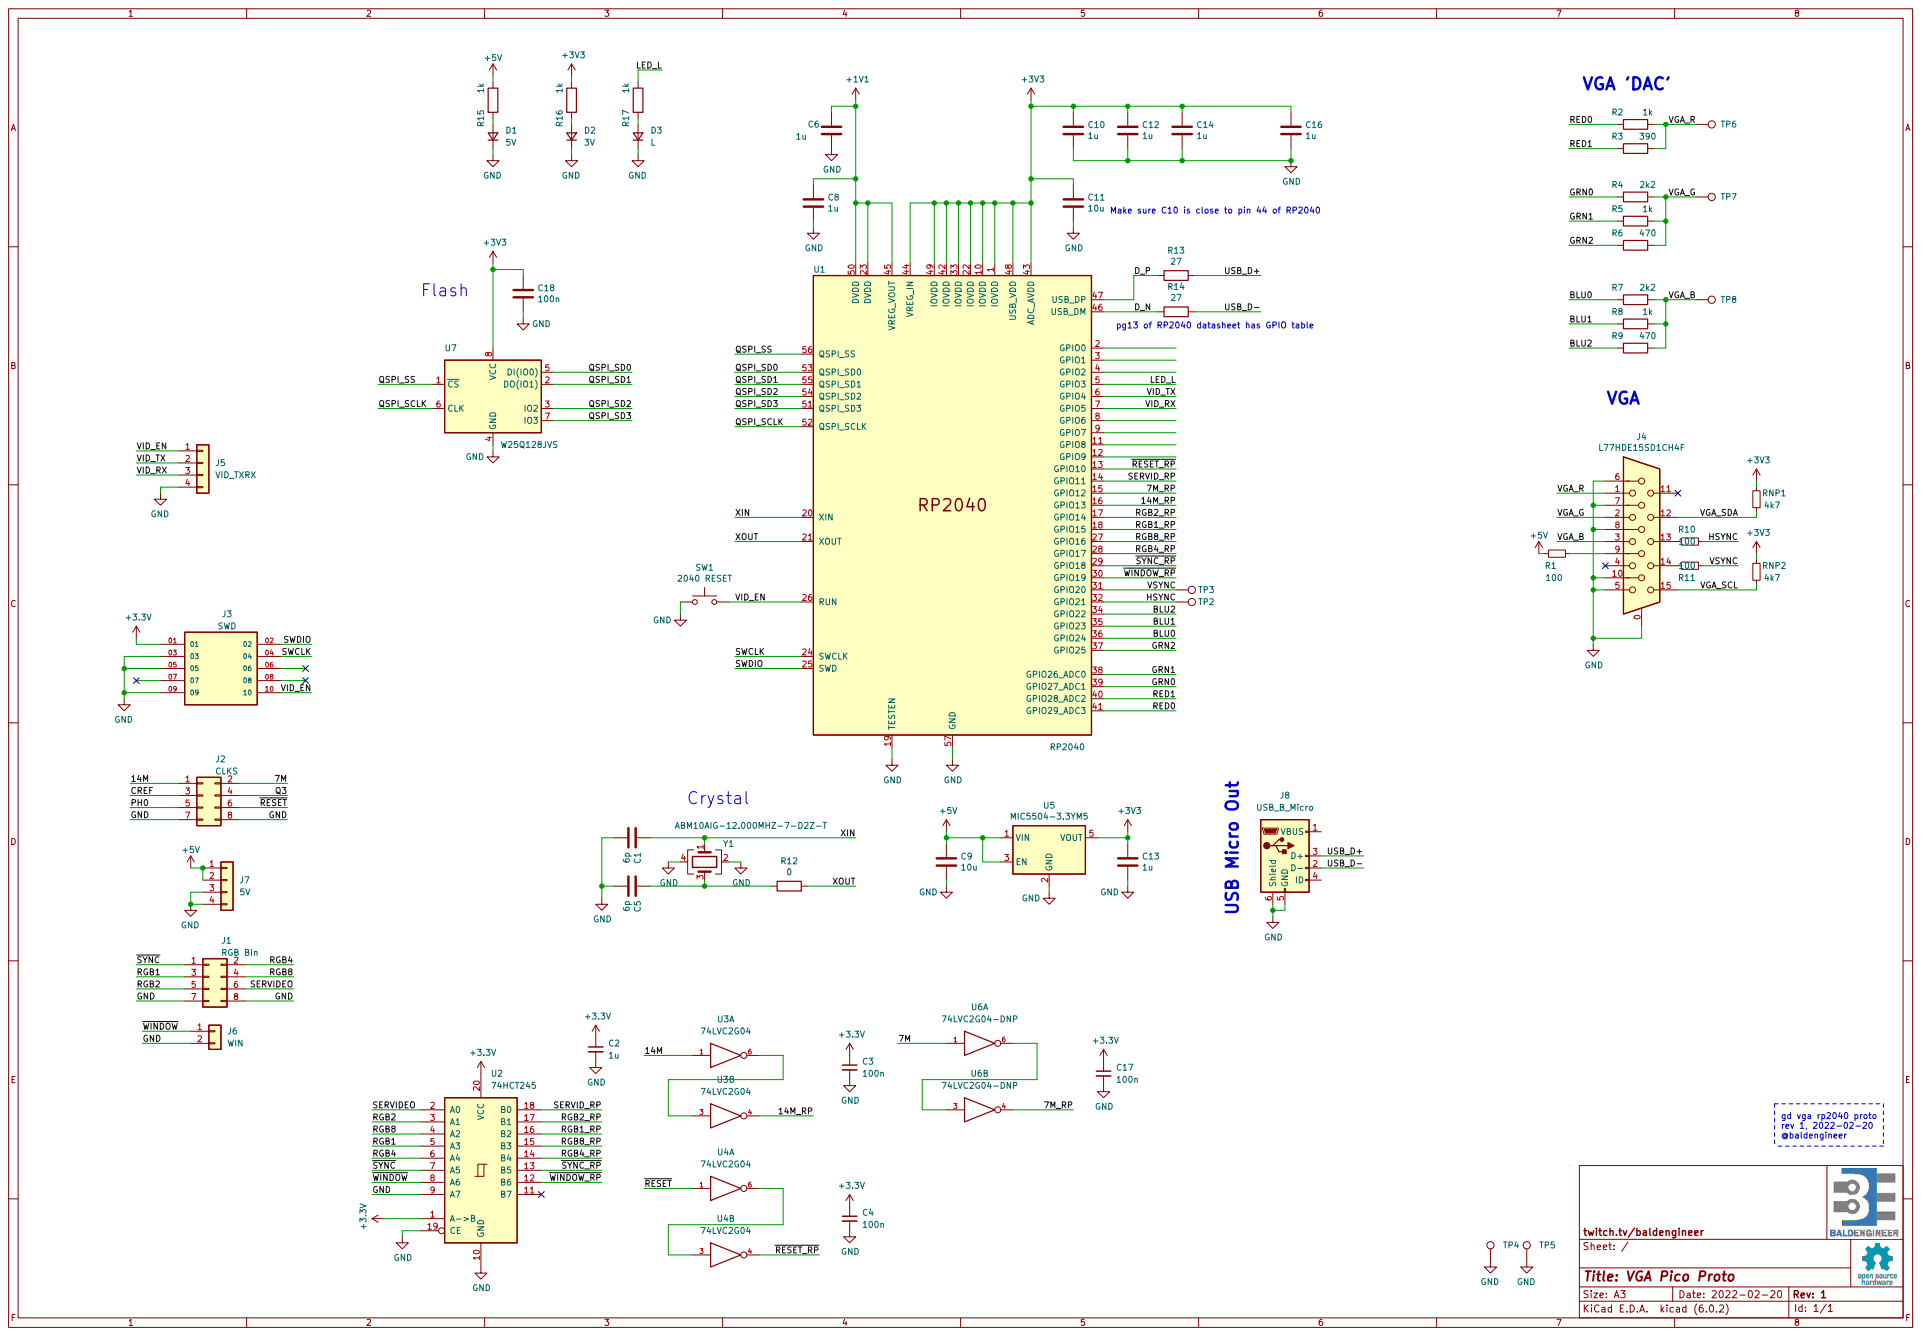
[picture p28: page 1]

Make sure C10 is close to pin 44 of RP2040

1 IOVDD 10 GPIO8 11 GPIO9 12 GPIO10 13 GPIO11 14 GPIO12 15 GPIO13 16 GPIO14 17 GPIO15 18 TESTEN 19 GPIO0 2 XIN 20 XOUT 21 IOVDD 22 DVDD 23 SWCLK 24 SWD 25 RUN 26 GPIO16 27 GPIO17 28 GPIO18 29 GPIO1 3 GPIO19 30 GPIO20 31 GPIO21 32 IOVDD 33 GPIO22 34 GPIO23 35 GPIO24 36 GPIO25 37 GPIO26_ADC0 38 GPIO27_ADC1 39 GPIO2 4 GPIO28_ADC2 40 GPIO29_ADC3 41 IOVDD 42 ADC_AVDD 43 VREG_IN 44 VREG_VOUT 45 USB_DM 46 USB_DP 47 USB_VDD 48 IOVDD 49 GPIO3 5 DVDD 50 QSPI_SD3 51 QSPI_SCLK 52 QSPI_SD0 53 QSPI_SD2 54 QSPI_SD1 55 QSPI_SS 56 GND 57 GPIO4 6 GPIO5 7 GPIO6 8 GPIO7 9 U1 RP2040

pg13 of RP2040 datasheet has GPIO table

rev 1, 2022-02-20 @baldengineer USB Micro Out

Sheet: / twitch.tv/baldengineer

Id: 1/1 Title: VGA Pico Proto

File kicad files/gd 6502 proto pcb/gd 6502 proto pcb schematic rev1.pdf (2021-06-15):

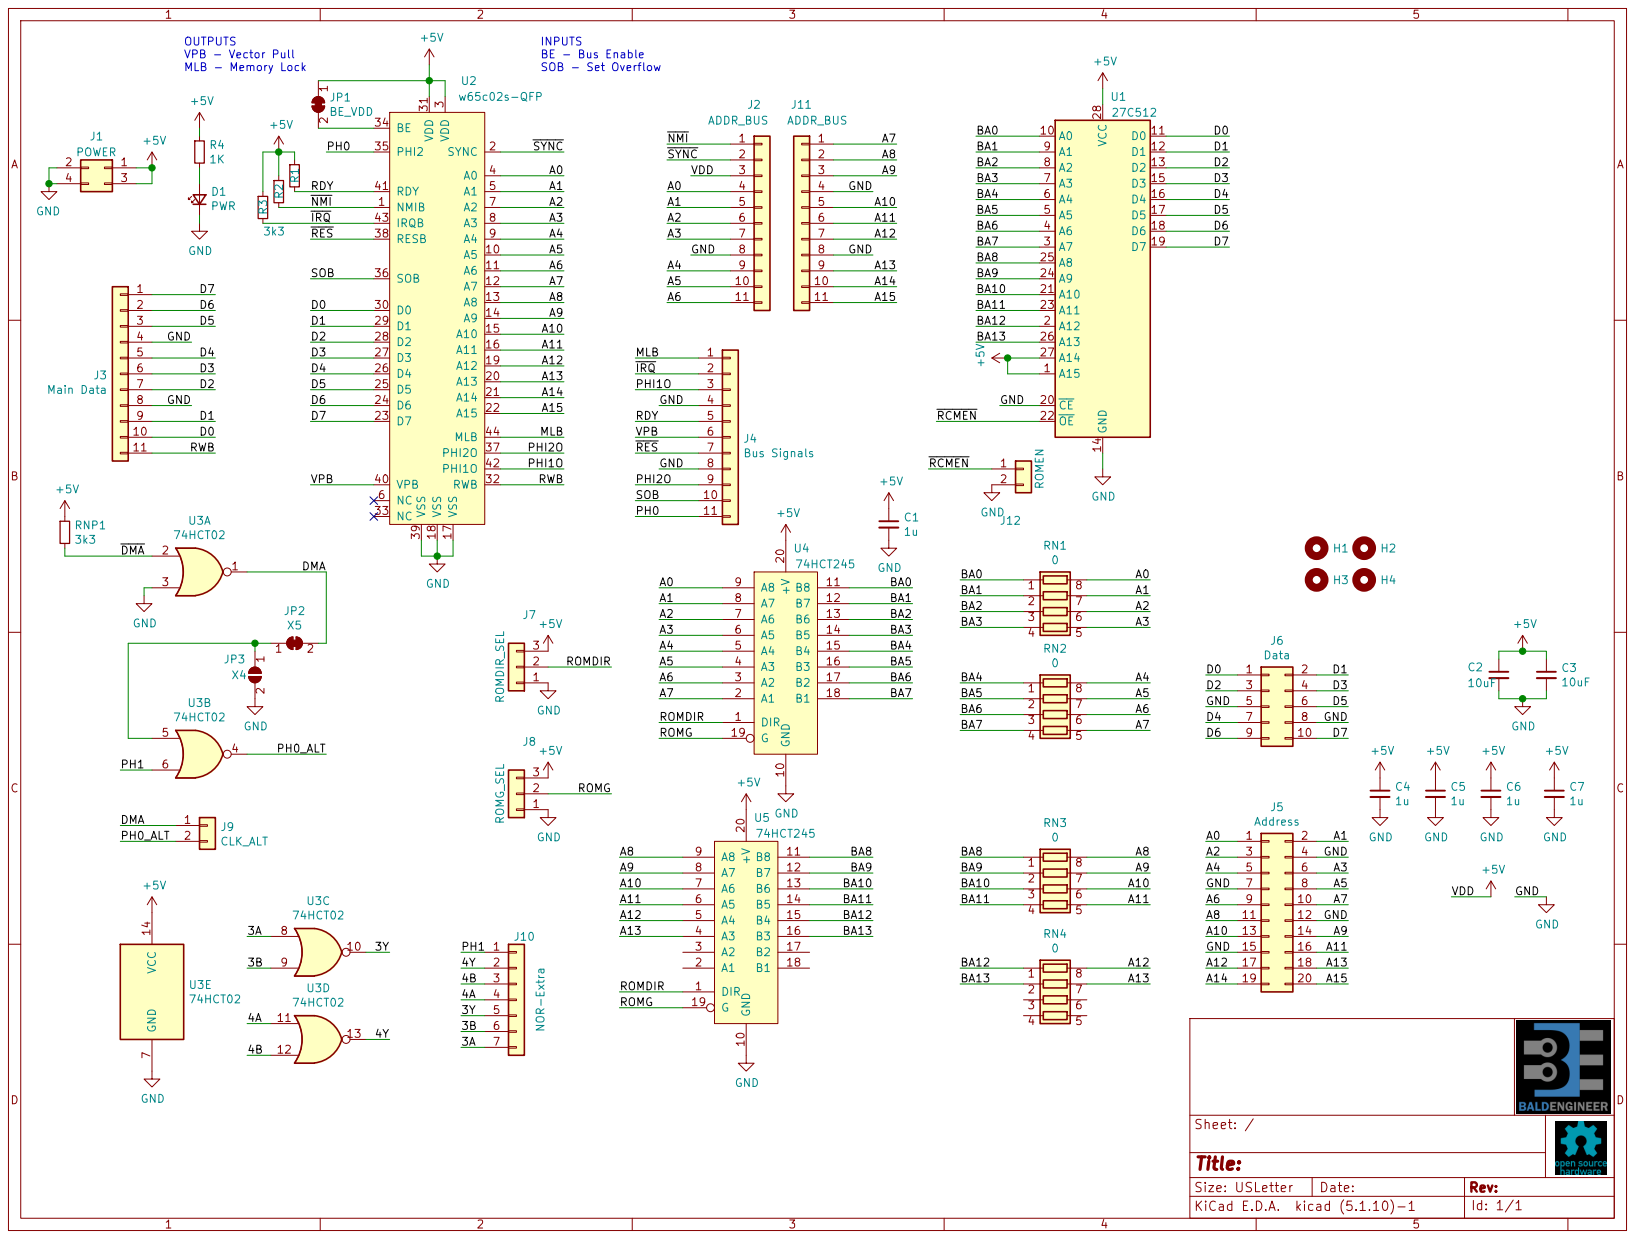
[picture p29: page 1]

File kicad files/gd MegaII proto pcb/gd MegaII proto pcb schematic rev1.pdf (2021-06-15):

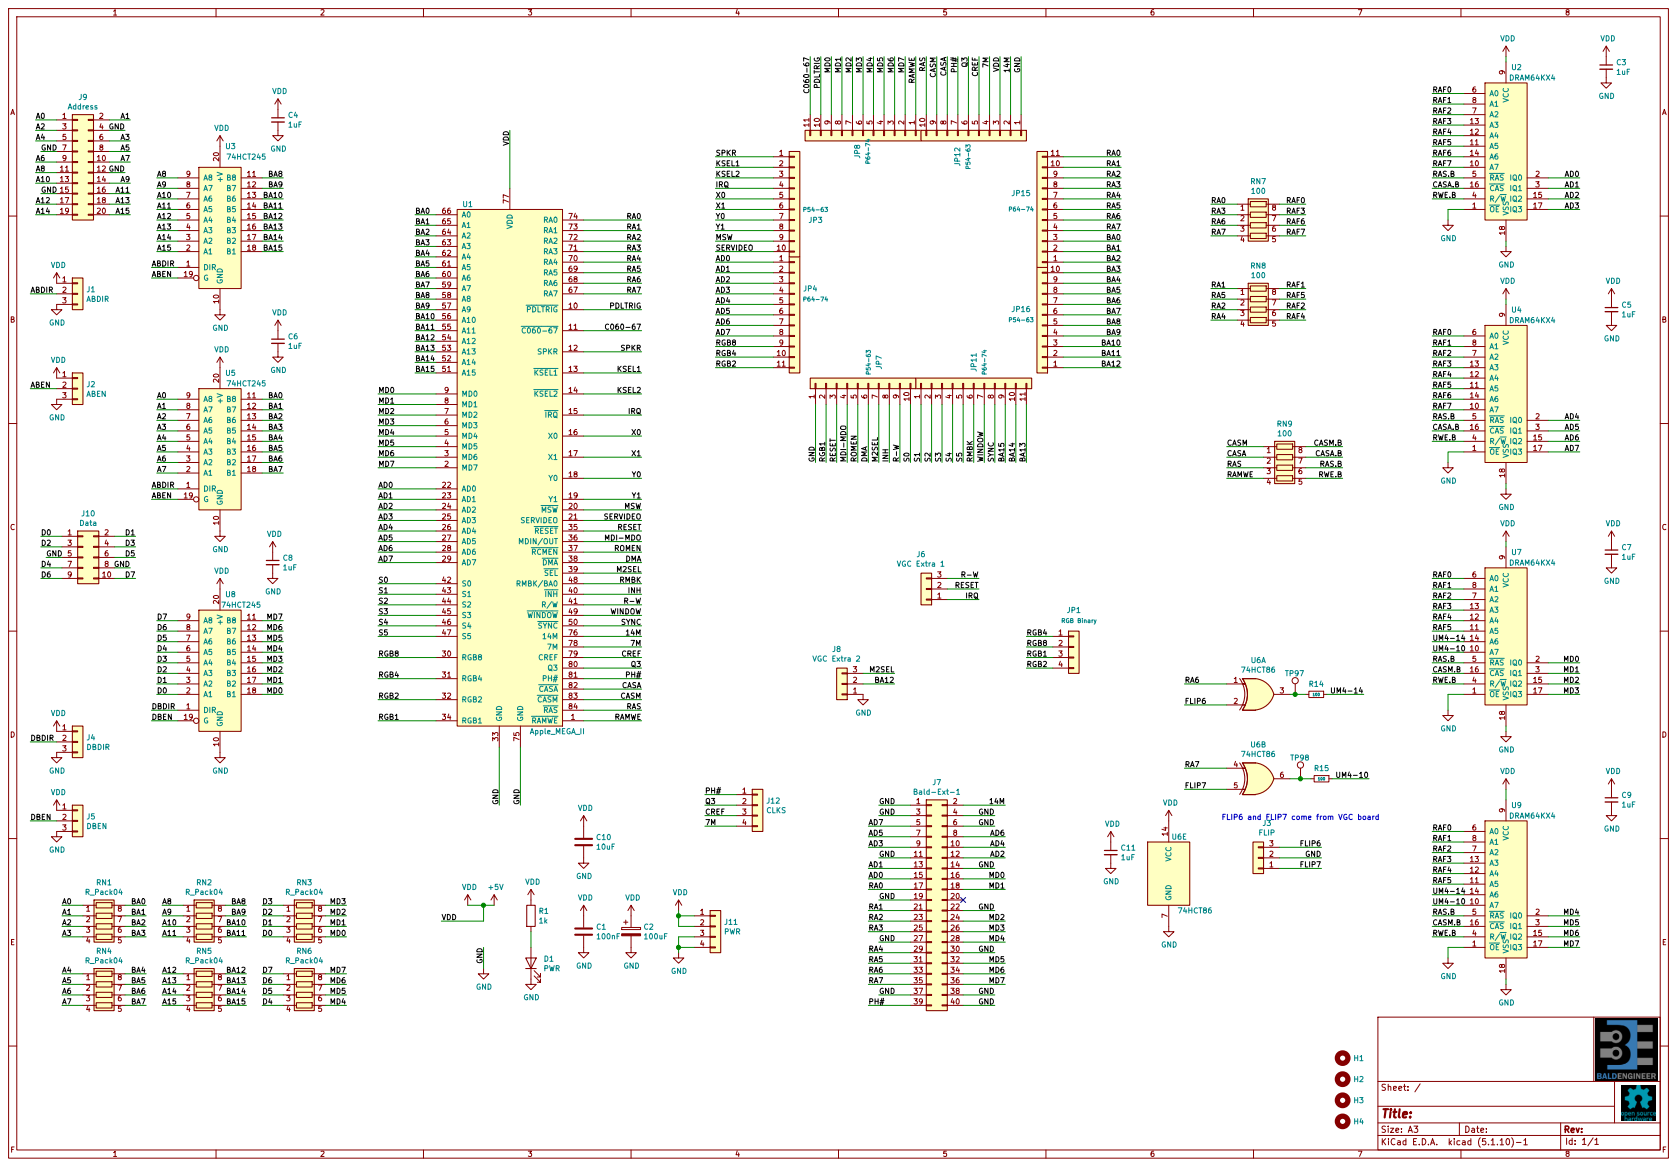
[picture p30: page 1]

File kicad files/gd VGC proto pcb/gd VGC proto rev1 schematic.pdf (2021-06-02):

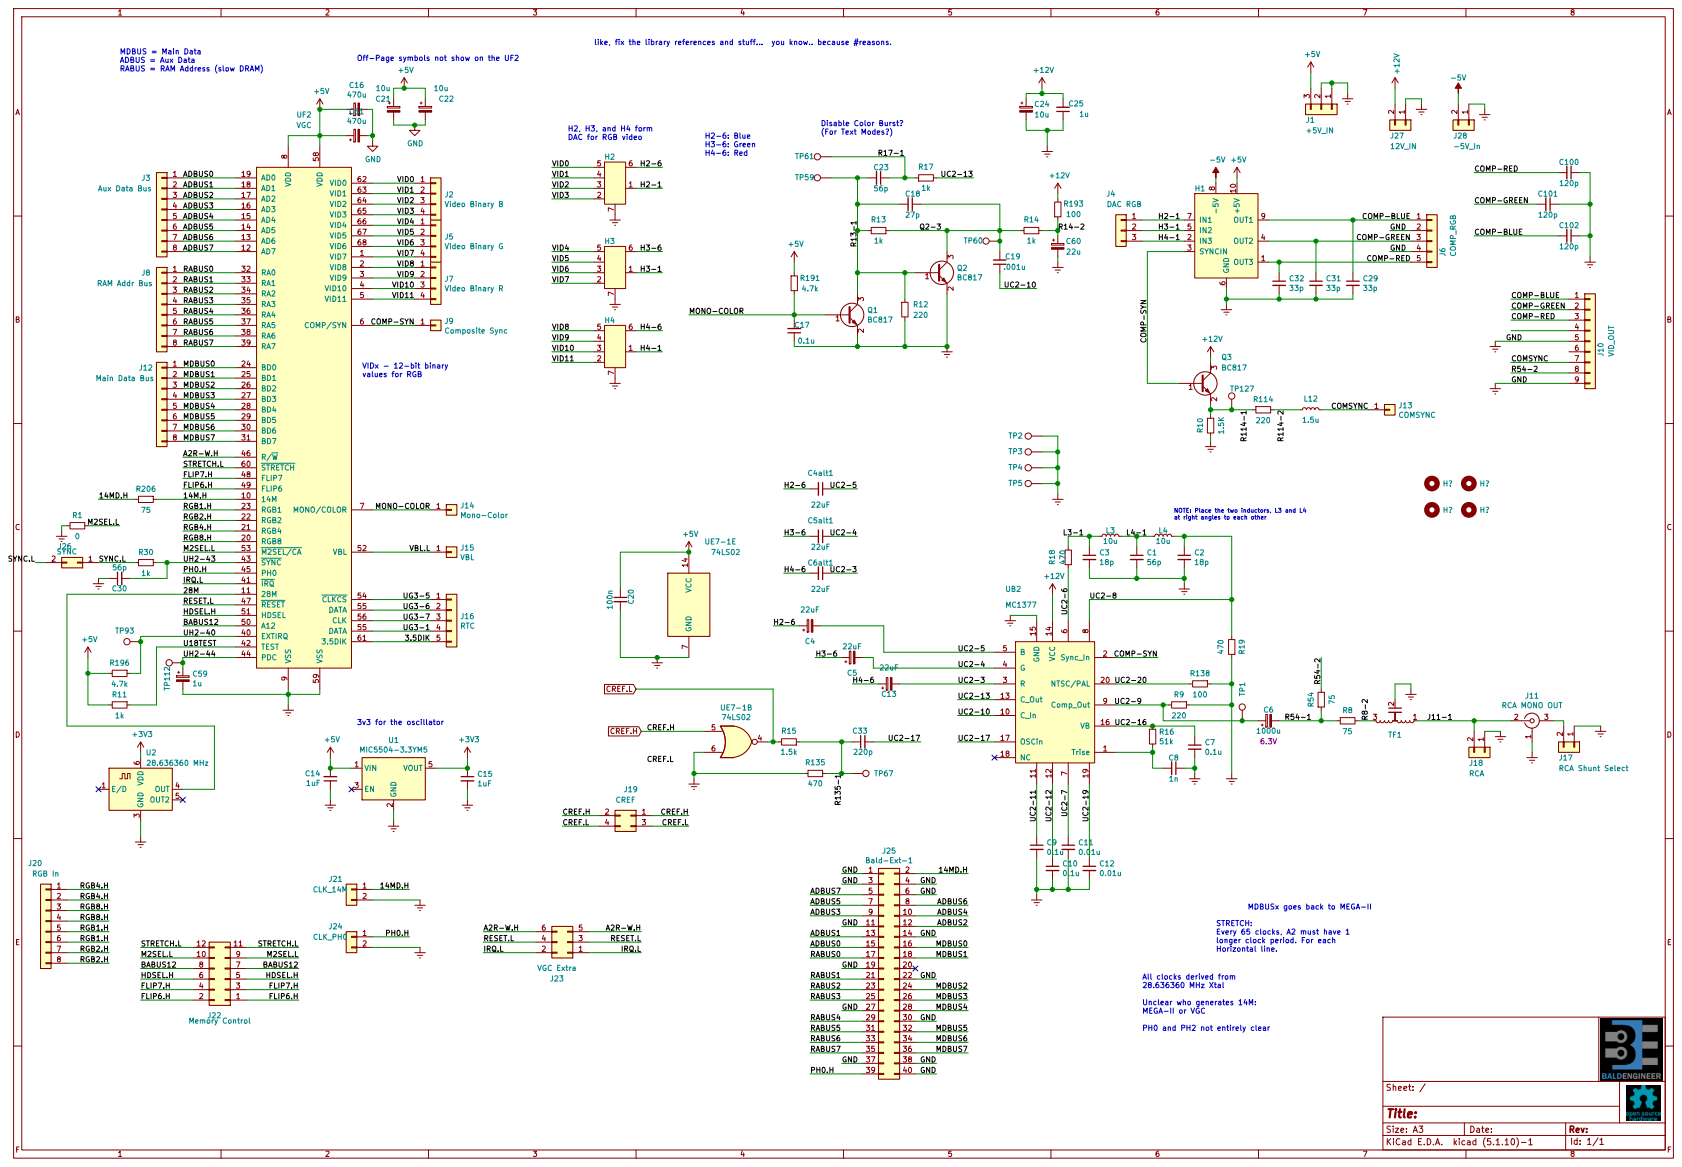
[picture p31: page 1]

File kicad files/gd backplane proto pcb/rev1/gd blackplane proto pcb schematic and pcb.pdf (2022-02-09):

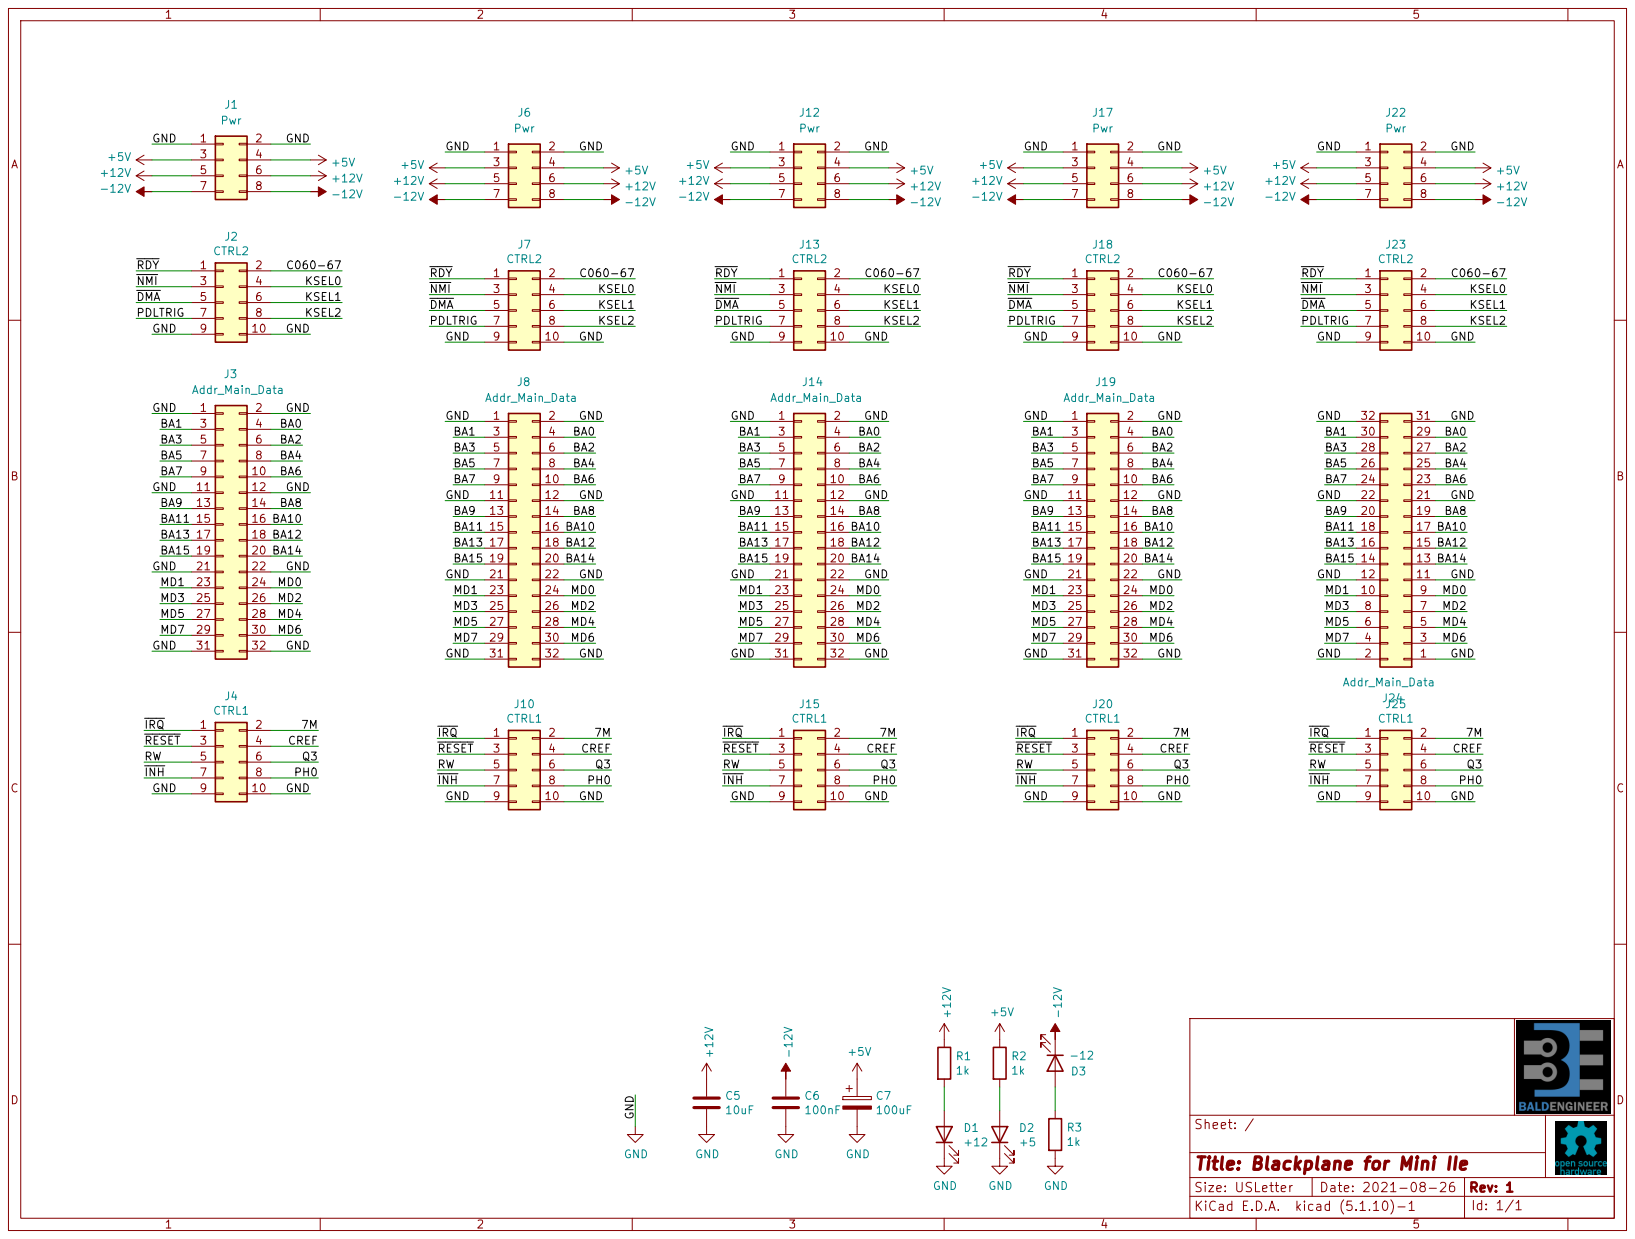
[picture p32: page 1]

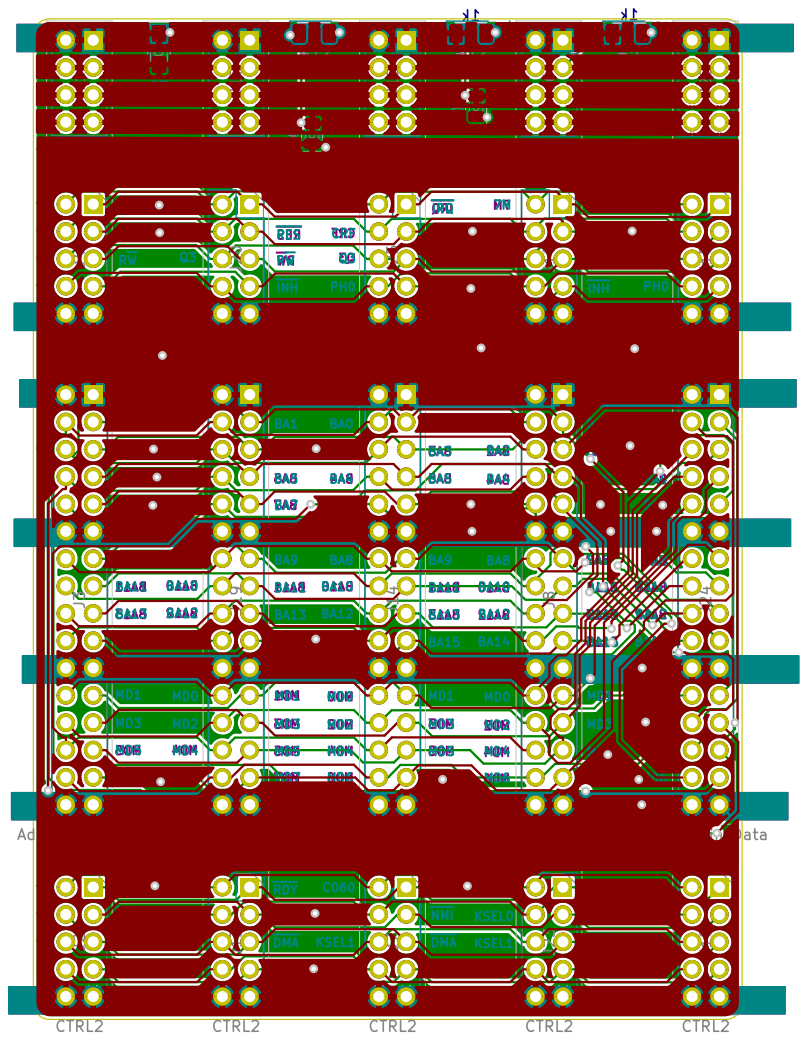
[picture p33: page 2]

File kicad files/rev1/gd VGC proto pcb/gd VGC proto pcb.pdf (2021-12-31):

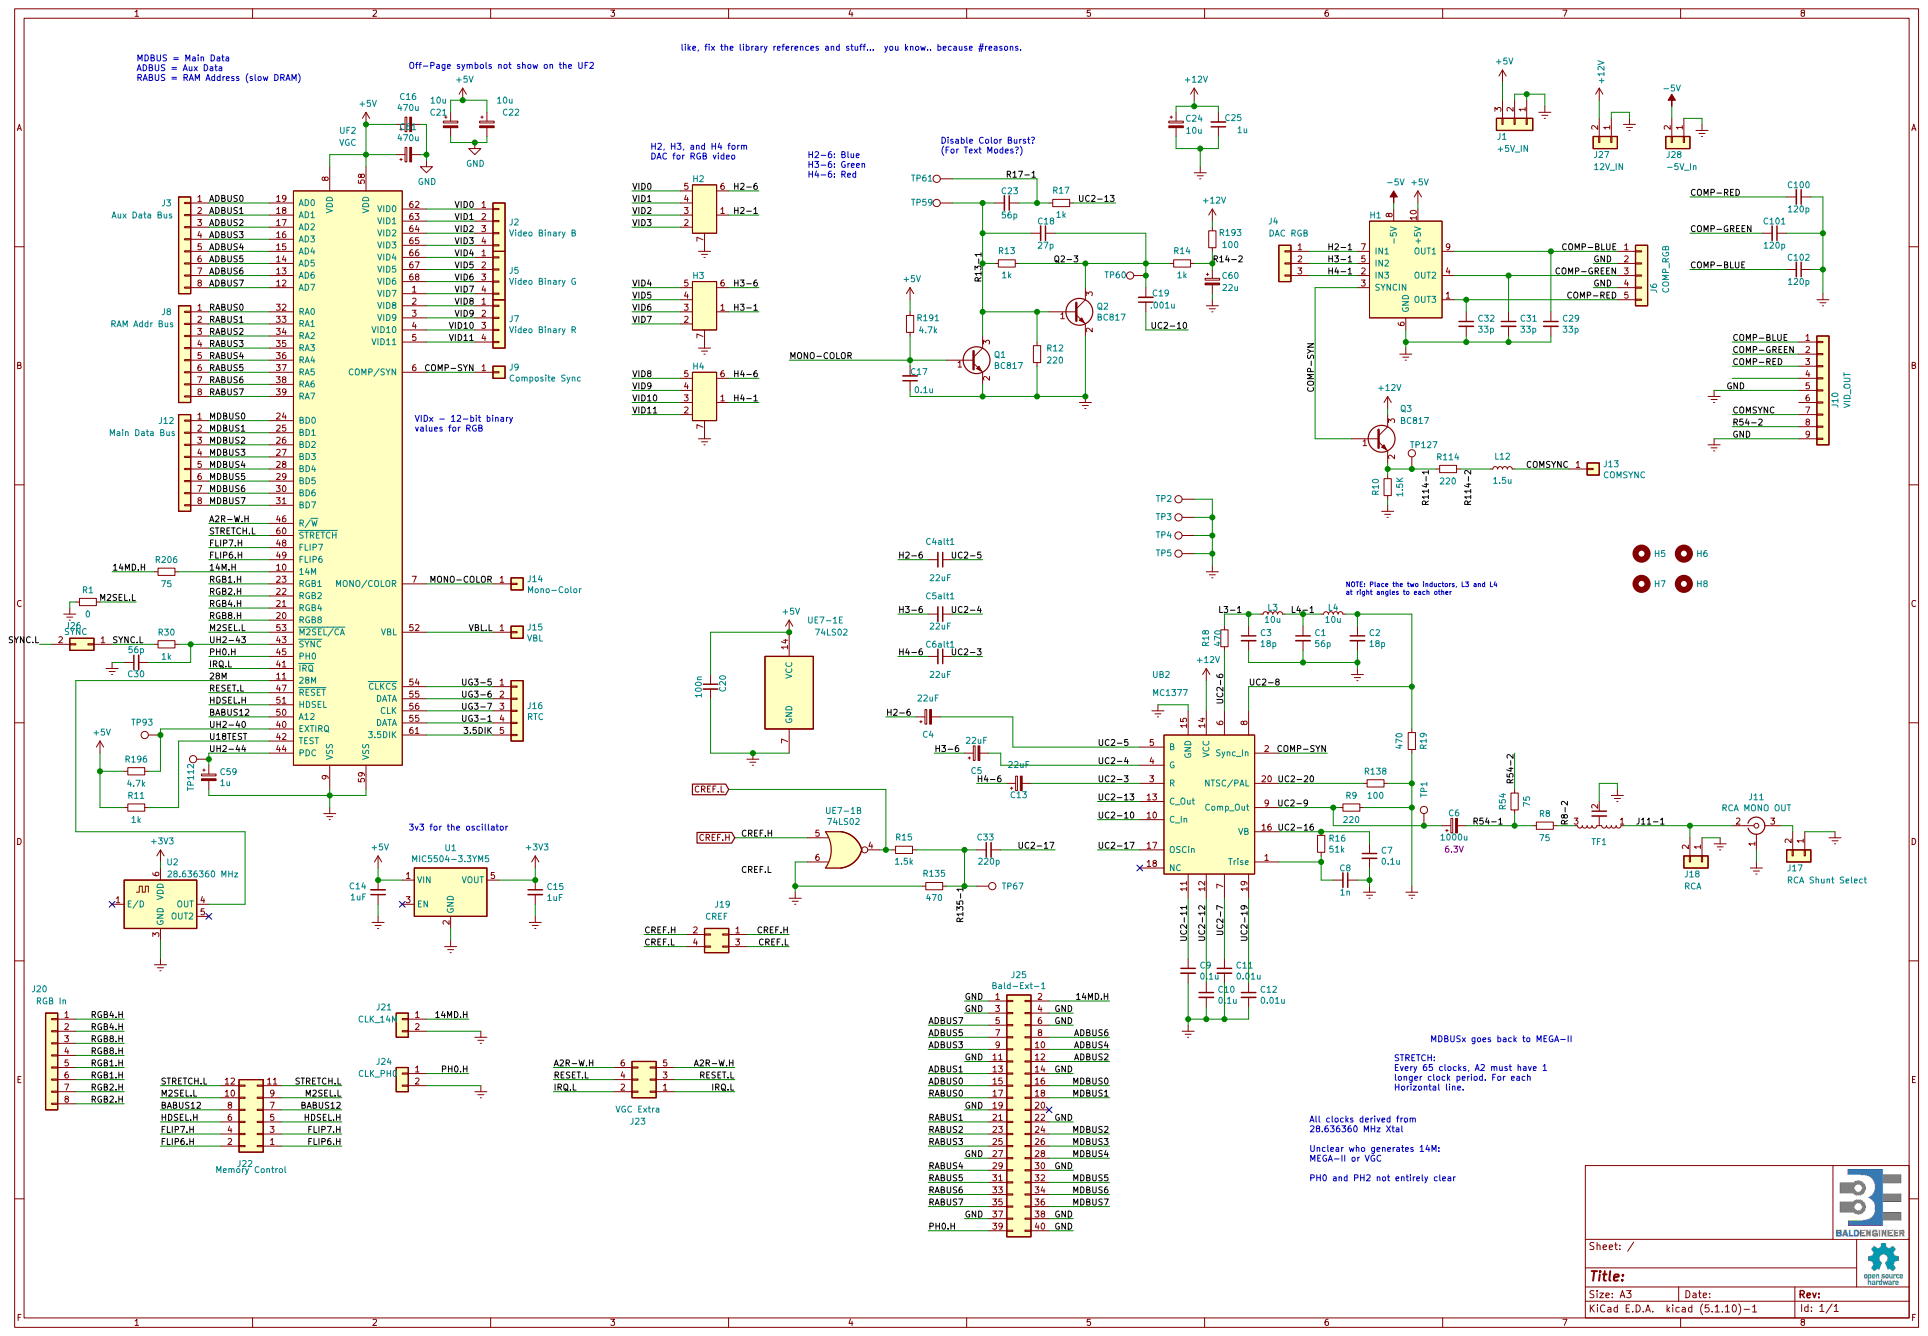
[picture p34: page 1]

like, fix the library references and stuff... you know.. because #reasons.

MDBUS = Main Data ADBUS = Aux Data RABUS = RAM Address (slow DRAM)

DAC for RGB video Off-Page symbols not show on the UF2

(For Text Modes?) H2, H3, and H4 form

COMP-RED COMP-SYN

2 3 Q3BC817 Trise 1 C_In 10 1112 C_Out 13 VCC 14 GND 15 VB 16 OSCin 17 NC 18 19

NOTE: Place the two inductors, L3 and L4
at right angles to each other

PH0 and PH2 not entirely clear STRETCH: Every 65 clocks, A2 must have 1

longer clock period. For each Horizontal line.

All clocks derived from
28.636360 MHz Xtal Unclear who generates 14M: MEGA-II or VGC

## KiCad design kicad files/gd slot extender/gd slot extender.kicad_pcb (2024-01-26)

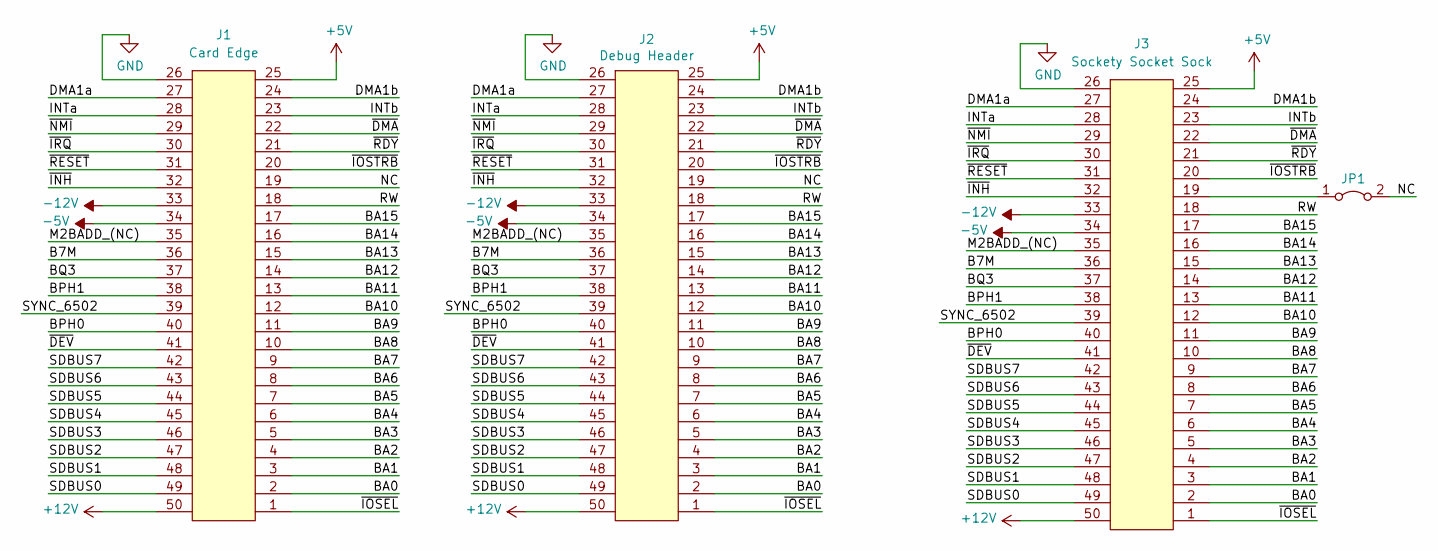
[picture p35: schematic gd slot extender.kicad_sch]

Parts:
J1: Card Edge; AppleIIBus
J2: Debug Header; PinHeader_2x25_P2.54mm_Vertical
J3: Sockety Socket Sock; Amp_2358256-4_50pos_right_angle_card
JP1: Jumper_2_Bridged; SolderJumper-2_P1.3mm_Bridged_RoundedPad1.0x1.5mm

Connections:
+5V: J1.25, J2.25, J3.25
+12V: J1.50, J2.50, J3.50
-5V: J1.34, J2.34, J3.34
-12V: J1.33, J2.33, J3.33
/B7M: J1.36, J2.36, J3.36
/BA0: J1.2, J2.2, J3.2
/BA1: J1.3, J2.3, J3.3
/BA2: J1.4, J2.4, J3.4
/BA3: J1.5, J2.5, J3.5
/BA4: J1.6, J2.6, J3.6
/BA5: J1.7, J2.7, J3.7
/BA6: J1.8, J2.8, J3.8
/BA7: J1.9, J2.9, J3.9
/BA8: J1.10, J2.10, J3.10
/BA9: J1.11, J2.11, J3.11
/BA10: J1.12, J2.12, J3.12
/BA11: J1.13, J2.13, J3.13
/BA12: J1.14, J2.14, J3.14
/BA13: J1.15, J2.15, J3.15
/BA14: J1.16, J2.16, J3.16
/BA15: J1.17, J2.17, J3.17
/BPH0: J1.40, J2.40, J3.40
/BPH1: J1.38, J2.38, J3.38
/BQ3: J1.37, J2.37, J3.37
/DMA1a: J1.27, J2.27, J3.27
/DMA1b: J1.24, J2.24, J3.24
/INTa: J1.28, J2.28, J3.28
/INTb: J1.23, J2.23, J3.23
/M2BADD_(NC): J1.35, J2.35, J3.35
/NC: J1.19, J2.19, JP1.2 (B)
/RW: J1.18, J2.18, J3.18
/SDBUS0: J1.49, J2.49, J3.49
/SDBUS1: J1.48, J2.48, J3.48
/SDBUS2: J1.47, J2.47, J3.47
/SDBUS3: J1.46, J2.46, J3.46
/SDBUS4: J1.45, J2.45, J3.45
/SDBUS5: J1.44, J2.44, J3.44
/SDBUS6: J1.43, J2.43, J3.43
/SDBUS7: J1.42, J2.42, J3.42
/SYNC_6502: J1.39, J2.39, J3.39
/~DEV: J1.41, J2.41, J3.41
/~DMA: J1.22, J2.22, J3.22
/~INH: J1.32, J2.32, J3.32
/~IOSEL: J1.1, J2.1, J3.1
/~IOSTRB: J1.20, J2.20, J3.20
/~IRQ: J1.30, J2.30, J3.30
/~NMI: J1.29, J2.29, J3.29
/~RDY: J1.21, J2.21, J3.21
/~RESET: J1.31, J2.31, J3.31
GND: J1.26, J2.26, J3.26
unnamed: J3.19, JP1.1 (A)

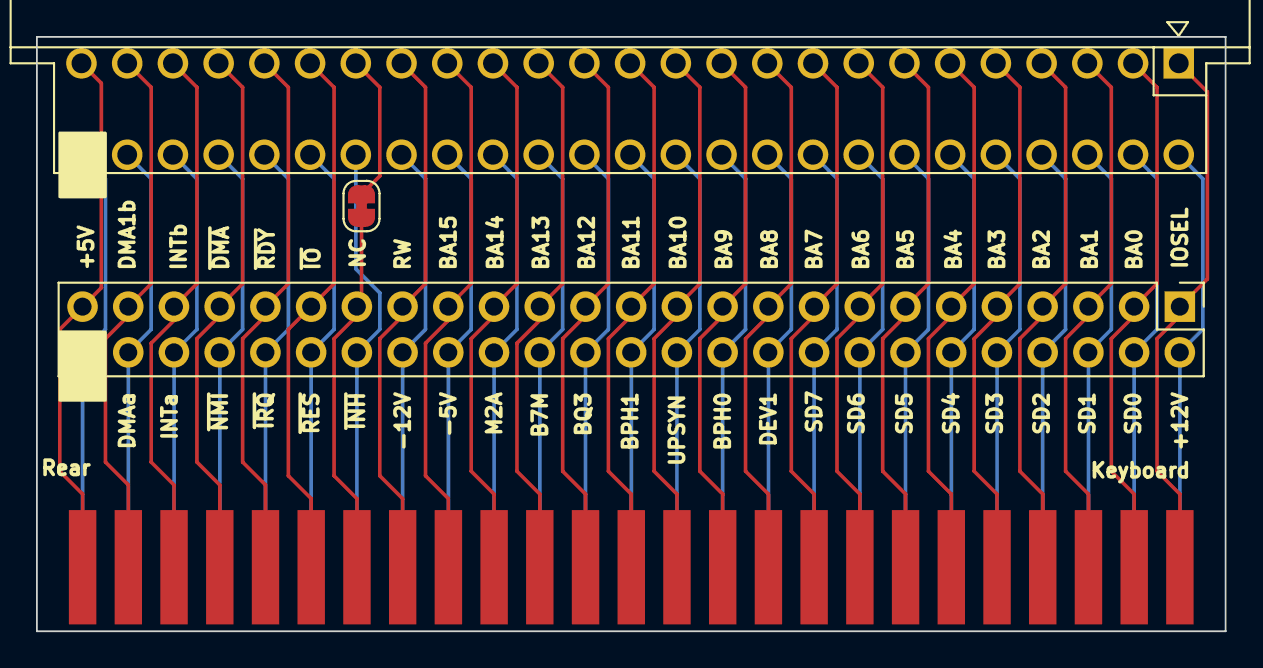
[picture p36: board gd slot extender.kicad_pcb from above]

Board: 2 copper layers, 66.0 x 33.0 mm, 4 parts (0 on the bottom side), 51 nets.

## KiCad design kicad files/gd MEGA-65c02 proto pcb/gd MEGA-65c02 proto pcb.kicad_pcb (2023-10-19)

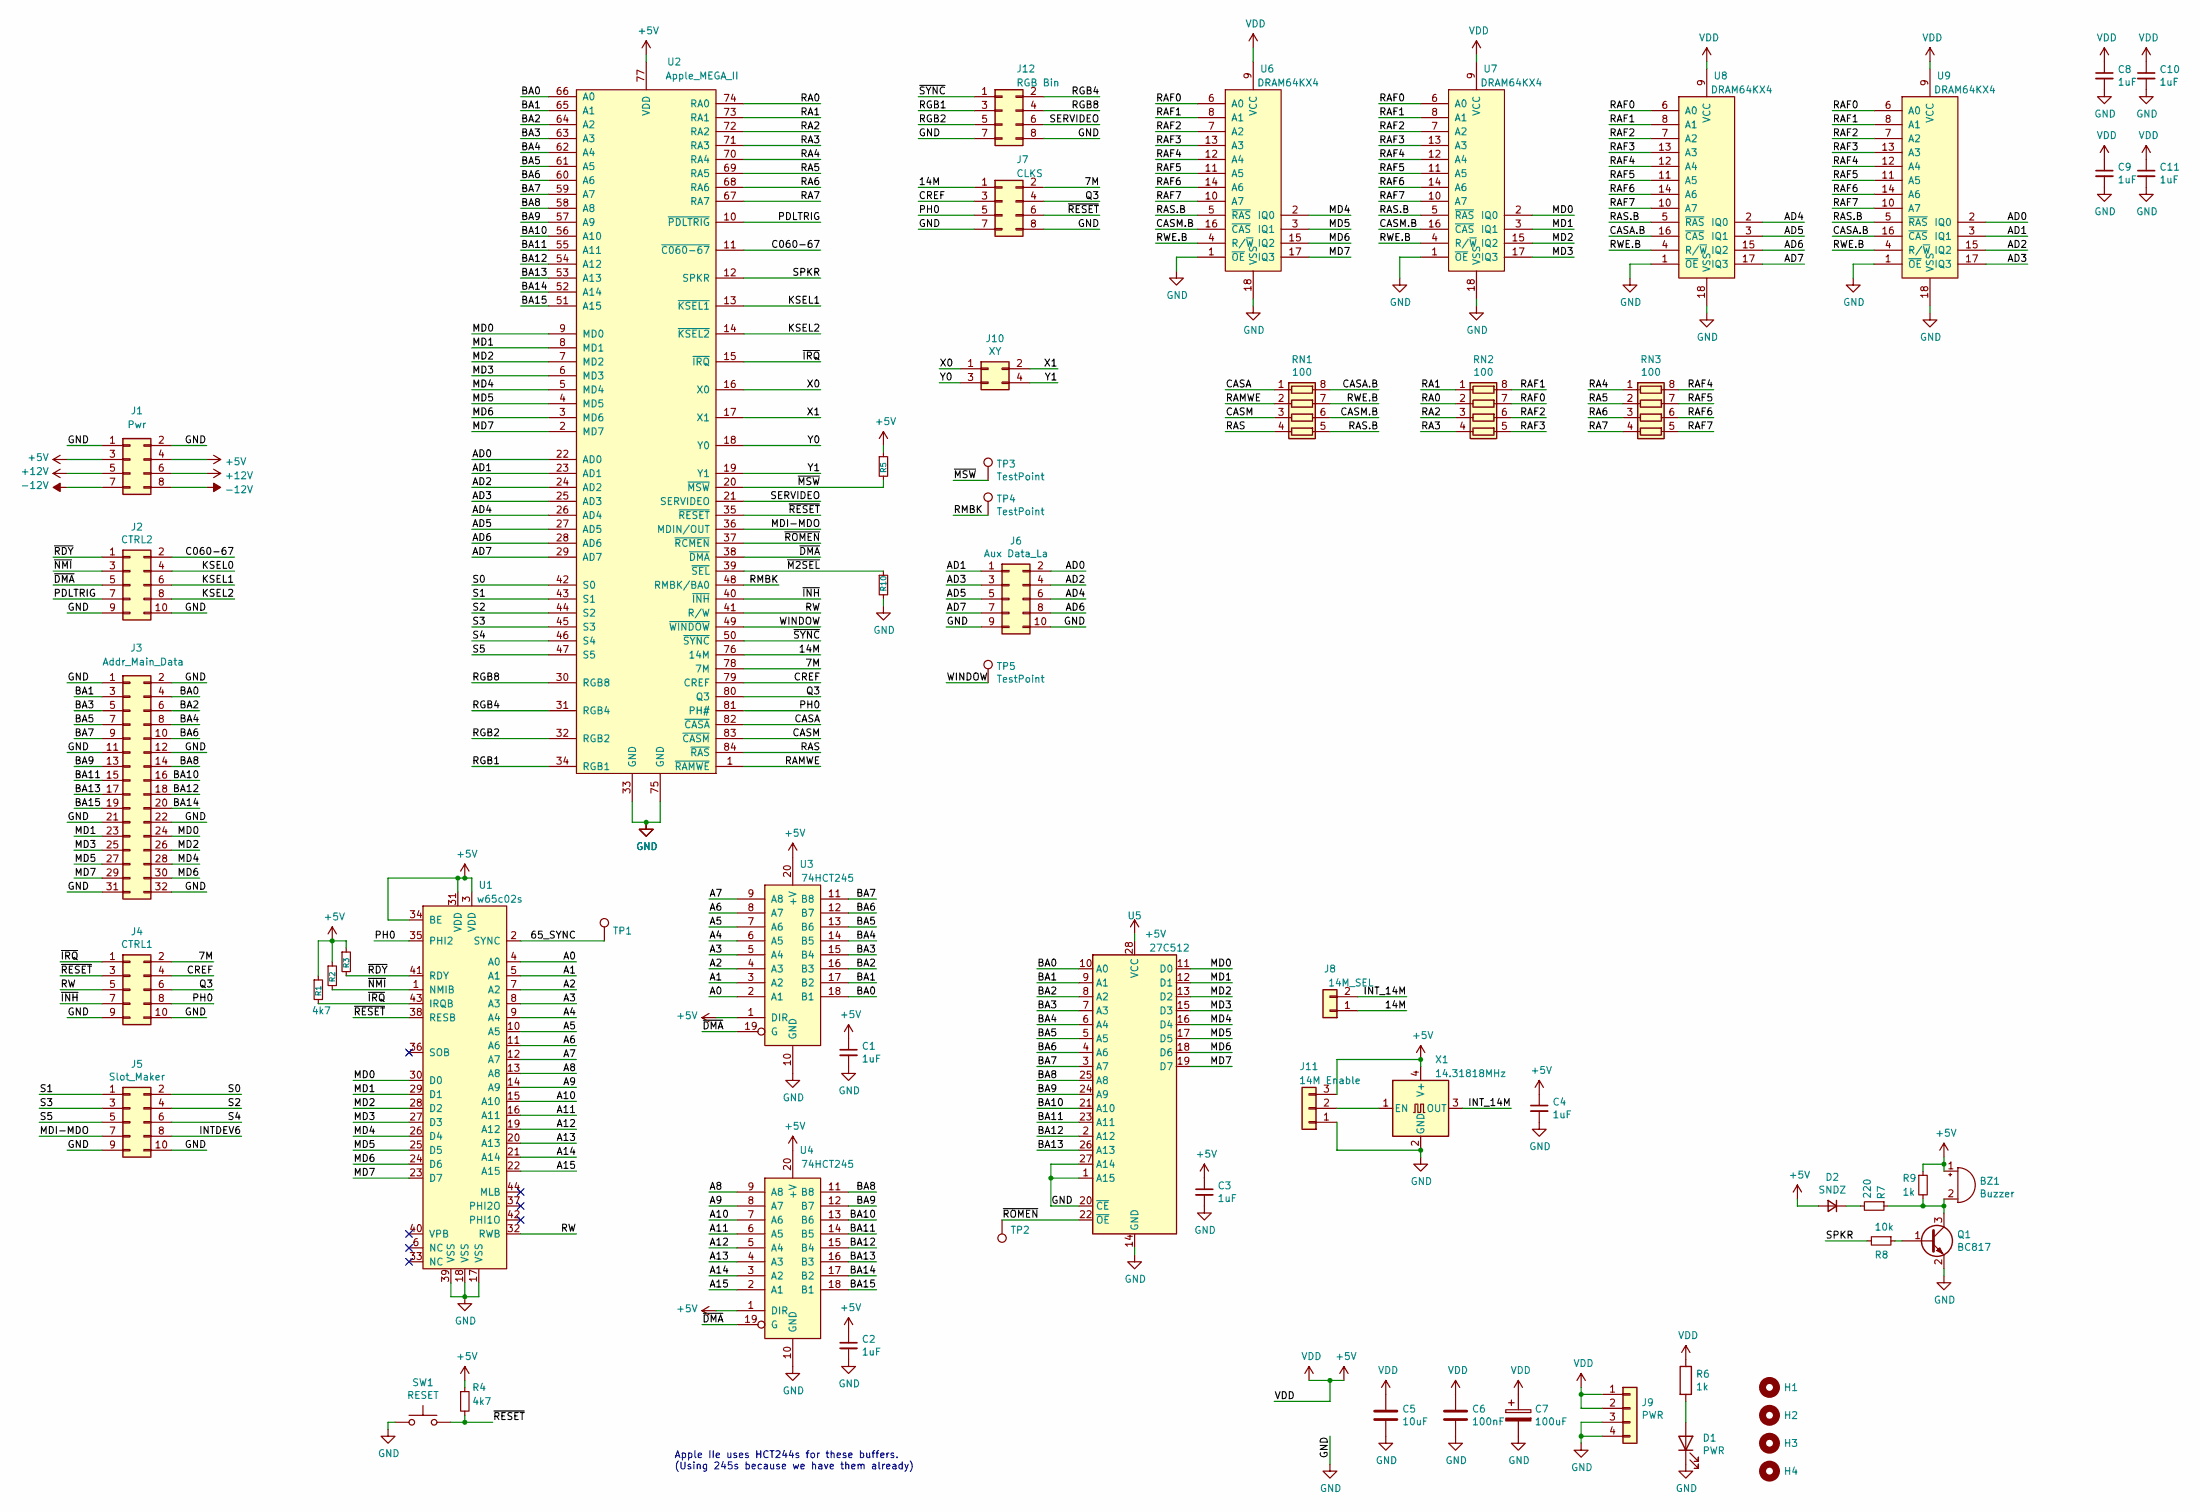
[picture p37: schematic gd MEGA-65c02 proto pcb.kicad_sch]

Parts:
BZ1: Buzzer; 12mm_Piezo_Buzzer
C1, C2, C3, C4, C8, C9, C10, C11: 1uF; C_0805_2012Metric
C5: 10uF; C_0805_2012Metric
C6: 100nF; C_0805_2012Metric
C7: 100uF; CP_EIA-3216-18_Kemet-A_Pad1.58x1.35mm_HandSolder
D1: PWR; LED_1206_3216Metric
D2: SNDZ; LED_1206_3216Metric
H1, H2, H3, H4: MountingHole; MountingHole_2.5mm
J1: Pwr; PinHeader_2x04_P2.54mm_Vertical-NOSILK
J2: CTRL2; PinHeader_2x05_P2.54mm_Vertical
J3: Addr_Main_Data; PinHeader_2x16_P2.54mm_Vertical
J4: CTRL1; PinHeader_2x05_P2.54mm_Vertical
J5: Slot_Maker; PinHeader_2x05_P2.54mm_Vertical
J6: Aux Data_La; PinHeader_2x05_P2.54mm_Vertical
J7: CLKS; PinHeader_2x04_P2.54mm_Vertical
J8: 14M_SEL; PinHeader_1x02_P2.54mm_Vertical
J9: PWR; PinHeader_1x04_P2.54mm_Vertical
J10: XY; PinHeader_2x02_P2.54mm_Vertical
J11: 14M Enable; PinHeader_1x03_P2.54mm_Vertical
J12: RGB Bin; PinHeader_2x04_P2.54mm_Vertical
Q1: BC817; SOT-23
R1, R4, R5, R10: 4k7; R_0805_2012Metric
R2, R3: 3k3; R_0805_2012Metric
R6, R9: 1k; R_0805_2012Metric
R7: 220; R_0805_2012Metric
R8: 10k; R_0805_2012Metric
RN1, RN2, RN3: 100; R_Array_Convex_4x0612
SW1: RESET; SW_Push_1P1T_NO_CK_KSC6xxJ
TP1, TP2: TestPoint_Harwin; Harwin-S1751-46-Test-Point
TP3, TP4, TP5: TestPoint; Harwin-S1751-46-Test-Point
U1: w65c02s; TQFP-44_10x10mm_P0.8mm
U2: Apple_MEGA_II; PLCC-84_THT-Socket
U3, U4: 74HCT245; SOIC-20W_7.5x12.8mm_P1.27mm
U5: 27C512; DIP_Socket-28_W11.9_W12.7_W15.24_W17.78_W18.5_3M_228-1277-0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
U6, U7, U8, U9: DRAM64KX4; DIP-18_W7.62mm_Socket_LongPads
X1: 14.31818MHz; Oscillator_SMD_SeikoEpson_SG8002CA-4Pin_7.0x5.0mm_HandSolde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; MPN MCSJK-6NC1-14.31818-25-B

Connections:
+5V: BZ1.1 (-), C1.1, C2.1, C3.1, C4.1, C5.1, C6.1, C7.1, C8.1, C9.1, C10.1, C11.1, D2.2 (A), J1.3, J1.4, J9.1, J9.2, J11.3, R1.1, R2.1, R3.1, R4.1, R5.1, R6.1, R9.1, U1.3 (VDD), U1.31 (VDD), U1.34 (BE), U2.77 (VDD), U3.1 (DIR), U3.20 (+V), U4.1 (DIR), U4.20 (+V), U5.28 (VCC), U6.9 (VCC), U7.9 (VCC), U8.9 (VCC), U9.9 (VCC), X1.4 (V+)
+12V: J1.5, J1.6
-12V: J1.7, J1.8
/7M: J4.2, J7.2, U2.78 (7M)
/14M: J7.1, J8.1, U2.76 (14M)
/65_SYNC: TP1.1, U1.2 (SYNC)
/A0: U1.4 (A0), U3.2 (A1)
/A1: U1.5 (A1), U3.3 (A2)
/A2: U1.7 (A2), U3.4 (A3)
/A3: U1.8 (A3), U3.5 (A4)
/A4: U1.9 (A4), U3.6 (A5)
/A5: U1.10 (A5), U3.7 (A6)
/A6: U1.11 (A6), U3.8 (A7)
/A7: U1.12 (A7), U3.9 (A8)
/A8: U1.13 (A8), U4.9 (A8)
/A9: U1.14 (A9), U4.8 (A7)
/A10: U1.15 (A10), U4.7 (A6)
/A11: U1.16 (A11), U4.6 (A5)
/A12: U1.19 (A12), U4.5 (A4)
/A13: U1.20 (A13), U4.4 (A3)
/A14: U1.21 (A14), U4.3 (A2)
/A15: U1.22 (A15), U4.2 (A1)
/AD0: J6.2, U2.22 (AD0), U9.2 (IQ0)
/AD1: J6.1, U2.23 (AD1), U9.3 (IQ1)
/AD2: J6.4, U2.24 (AD2), U9.15 (IQ2)
/AD3: J6.3, U2.25 (AD3), U9.17 (IQ3)
/AD4: J6.6, U2.26 (AD4), U8.2 (IQ0)
/AD5: J6.5, U2.27 (AD5), U8.3 (IQ1)
/AD6: J6.8, U2.28 (AD6), U8.15 (IQ2)
/AD7: J6.7, U2.29 (AD7), U8.17 (IQ3)
/BA0: J3.4, U2.66 (A0), U3.18 (B1), U5.10 (A0)
/BA1: J3.3, U2.65 (A1), U3.17 (B2), U5.9 (A1)
/BA2: J3.6, U2.64 (A2), U3.16 (B3), U5.8 (A2)
/BA3: J3.5, U2.63 (A3), U3.15 (B4), U5.7 (A3)
/BA4: J3.8, U2.62 (A4), U3.14 (B5), U5.6 (A4)
/BA5: J3.7, U2.61 (A5), U3.13 (B6), U5.5 (A5)
/BA6: J3.10, U2.60 (A6), U3.12 (B7), U5.4 (A6)
/BA7: J3.9, U2.59 (A7), U3.11 (B8), U5.3 (A7)
/BA8: J3.14, U2.58 (A8), U4.11 (B8), U5.25 (A8)
/BA9: J3.13, U2.57 (A9), U4.12 (B7), U5.24 (A9)
/BA10: J3.16, U2.56 (A10), U4.13 (B6), U5.21 (A10)
/BA11: J3.15, U2.55 (A11), U4.14 (B5), U5.23 (A11)
/BA12: J3.18, U2.54 (A12), U4.15 (B4), U5.2 (A12)
/BA13: J3.17, U2.53 (A13), U4.16 (B3), U5.26 (A13)
/BA14: J3.20, U2.52 (A14), U4.17 (B2)
/BA15: J3.19, U2.51 (A15), U4.18 (B1)
/C060-67: J2.2, U2.11 (~C060-67)
/CASA: RN1.1 (R1.1), U2.82 (~CASA)
/CASA.B: RN1.8 (R1.2), U8.16 (~CAS), U9.16 (~CAS)
/CASM: RN1.3 (R3.1), U2.83 (~CASM)
/CASM.B: RN1.6 (R3.2), U6.16 (~CAS), U7.16 (~CAS)
/CREF: J4.4, J7.3, U2.79 (CREF)
/INTDEV6: J5.8
/INT_14M: J8.2, X1.3 (OUT)
/KSEL0: J2.4
/KSEL1: J2.6, U2.13 (~KSEL1)
/KSEL2: J2.8, U2.14 (~KSEL2)
/MD0: J3.24, U1.30 (D0), U2.9 (MD0), U5.11 (D0), U7.2 (IQ0)
/MD1: J3.23, U1.29 (D1), U2.8 (MD1), U5.12 (D1), U7.3 (IQ1)
/MD2: J3.26, U1.28 (D2), U2.7 (MD2), U5.13 (D2), U7.15 (IQ2)
/MD3: J3.25, U1.27 (D3), U2.6 (MD3), U5.15 (D3), U7.17 (IQ3)
/MD4: J3.28, U1.26 (D4), U2.5 (MD4), U5.16 (D4), U6.2 (IQ0)
/MD5: J3.27, U1.25 (D5), U2.4 (MD5), U5.17 (D5), U6.3 (IQ1)
/MD6: J3.30, U1.24 (D6), U2.3 (MD6), U5.18 (D6), U6.15 (IQ2)
/MD7: J3.29, U1.23 (D7), U2.2 (MD7), U5.19 (D7), U6.17 (IQ3)
/MDI-MDO: J5.7, U2.36 (MDIN/OUT)
/PDLTRIG: J2.7, U2.10 (~PDLTRIG)
/PH0: J4.8, J7.5, U1.35 (PHI2), U2.81 (PH#)
/Q3: J4.6, J7.4, U2.80 (Q3)
/RA0: RN2.2 (R2.1), U2.74 (RA0)
/RA1: RN2.1 (R1.1), U2.73 (RA1)
/RA2: RN2.3 (R3.1), U2.72 (RA2)
/RA3: RN2.4 (R4.1), U2.71 (RA3)
/RA4: RN3.1 (R1.1), U2.70 (RA4)
/RA5: RN3.2 (R2.1), U2.69 (RA5)
/RA6: RN3.3 (R3.1), U2.68 (RA6)
/RA7: RN3.4 (R4.1), U2.67 (RA7)
/RAF0: RN2.7 (R2.2), U6.6 (A0), U7.6 (A0), U8.6 (A0), U9.6 (A0)
/RAF1: RN2.8 (R1.2), U6.8 (A1), U7.8 (A1), U8.8 (A1), U9.8 (A1)
/RAF2: RN2.6 (R3.2), U6.7 (A2), U7.7 (A2), U8.7 (A2), U9.7 (A2)
/RAF3: RN2.5 (R4.2), U6.13 (A3), U7.13 (A3), U8.13 (A3), U9.13 (A3)
/RAF4: RN3.8 (R1.2), U6.12 (A4), U7.12 (A4), U8.12 (A4), U9.12 (A4)
/RAF5: RN3.7 (R2.2), U6.11 (A5), U7.11 (A5), U8.11 (A5), U9.11 (A5)
/RAF6: RN3.6 (R3.2), U6.14 (A6), U7.14 (A6), U8.14 (A6), U9.14 (A6)
/RAF7: RN3.5 (R4.2), U6.10 (A7), U7.10 (A7), U8.10 (A7), U9.10 (A7)
/RAMWE: RN1.2 (R2.1), U2.1 (~RAMWE)
/RAS: RN1.4 (R4.1), U2.84 (~RAS)
/RAS.B: RN1.5 (R4.2), U6.5 (~RAS), U7.5 (~RAS), U8.5 (~RAS), U9.5 (~RAS)
/RGB1: J12.3, U2.34 (RGB1)
/RGB2: J12.5, U2.32 (RGB2)
/RGB4: J12.2, U2.31 (RGB4)
/RGB8: J12.4, U2.30 (RGB8)
/RMBK: TP4.1, U2.48 (RMBK/BA0)
/RW: J4.5, U1.32 (RWB), U2.41 (R/W)
/RWE.B: RN1.7 (R2.2), U6.4 (R/~W), U7.4 (R/~W), U8.4 (R/~W), U9.4 (R/~W)
/S0: J5.2, U2.42 (S0)
/S1: J5.1, U2.43 (S1)
/S2: J5.4, U2.44 (S2)
/S3: J5.3, U2.45 (S3)
/S4: J5.6, U2.46 (S4)
/S5: J5.5, U2.47 (S5)
/SERVIDEO: J12.6, U2.21 (SERVIDEO)
/SPKR: R8.2, U2.12 (SPKR)
/WINDOW: TP5.1, U2.49 (~WINDOW)
/X0: J10.1, U2.16 (X0)
/X1: J10.2, U2.17 (X1)
/Y0: J10.3, U2.18 (Y0)
/Y1: J10.4, U2.19 (Y1)
/~DMA: J2.5, U2.38 (~DMA), U3.19 (G), U4.19 (G)
/~INH: J4.7, U2.40 (~INH)
/~IRQ: J4.1, R1.2, U1.43 (IRQB), U2.15 (~IRQ)
/~M2SEL: R10.1, U2.39 (~SEL)
/~MSW: R5.2, TP3.1, U2.20 (~MSW)
/~NMI: J2.3, R2.2, U1.1 (NMIB)
/~RDY: J2.1, R3.2, U1.41 (RDY)
/~RESET: J4.3, J7.6, R4.2, SW1.2, U1.38 (RESB), U2.35 (~RESET)
/~ROMEN: TP2.1, U2.37 (~RCMEN), U5.22 (~OE)
/~SYNC: J12.1, U2.50 (~SYNC)
GND: C1.2, C2.2, C3.2, C4.2, C5.2, C6.2, C7.2, C8.2, C9.2, C10.2, C11.2, D1.1 (K), J1.1, J1.2, J2.9, J2.10, J3.1, J3.2, J3.11, J3.12, J3.21, J3.22, J3.31, J3.32, J4.9, J4.10, J5.9, J5.10, J6.9, J6.10, J7.7, J7.8, J9.3, J9.4, J11.1, J12.7, J12.8, Q1.2 (E), R10.2, SW1.1, U1.17 (VSS), U1.18 (VSS), U1.39 (VSS), U2.33 (GND), U2.75 (GND), U3.10 (GND), U4.10 (GND), U5.1 (A15), U5.14 (GND), U5.20 (~CE), U5.27 (A14), U6.1 (~OE), U6.18 (VSS), U7.1 (~OE), U7.18 (VSS), U8.1 (~OE), U8.18 (VSS), U9.1 (~OE), U9.18 (VSS), X1.2 (GND)
unnamed: BZ1.2 (+), Q1.3 (C), R7.1, R9.2
unnamed: D1.2 (A), R6.2
unnamed: D2.1 (K), R7.2
unnamed: J11.2, X1.1 (EN)
unnamed: Q1.1 (B), R8.1

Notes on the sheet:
Apple IIe uses HCT244s for these buffers. (Using 245s because we have them already)

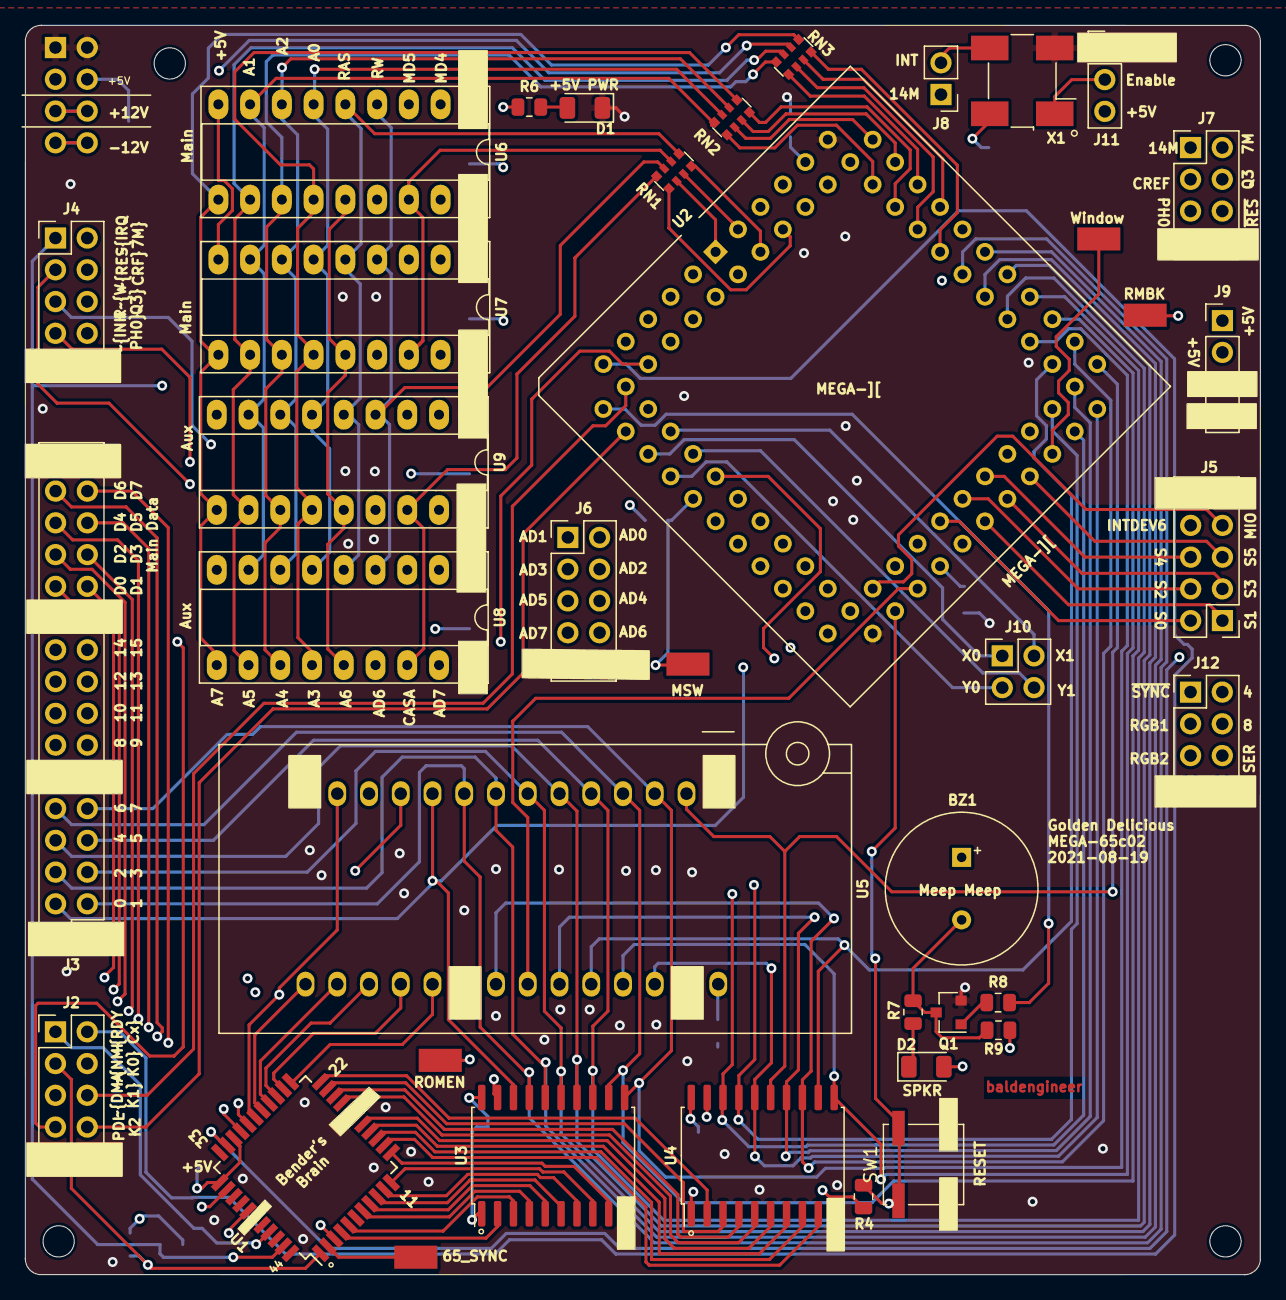
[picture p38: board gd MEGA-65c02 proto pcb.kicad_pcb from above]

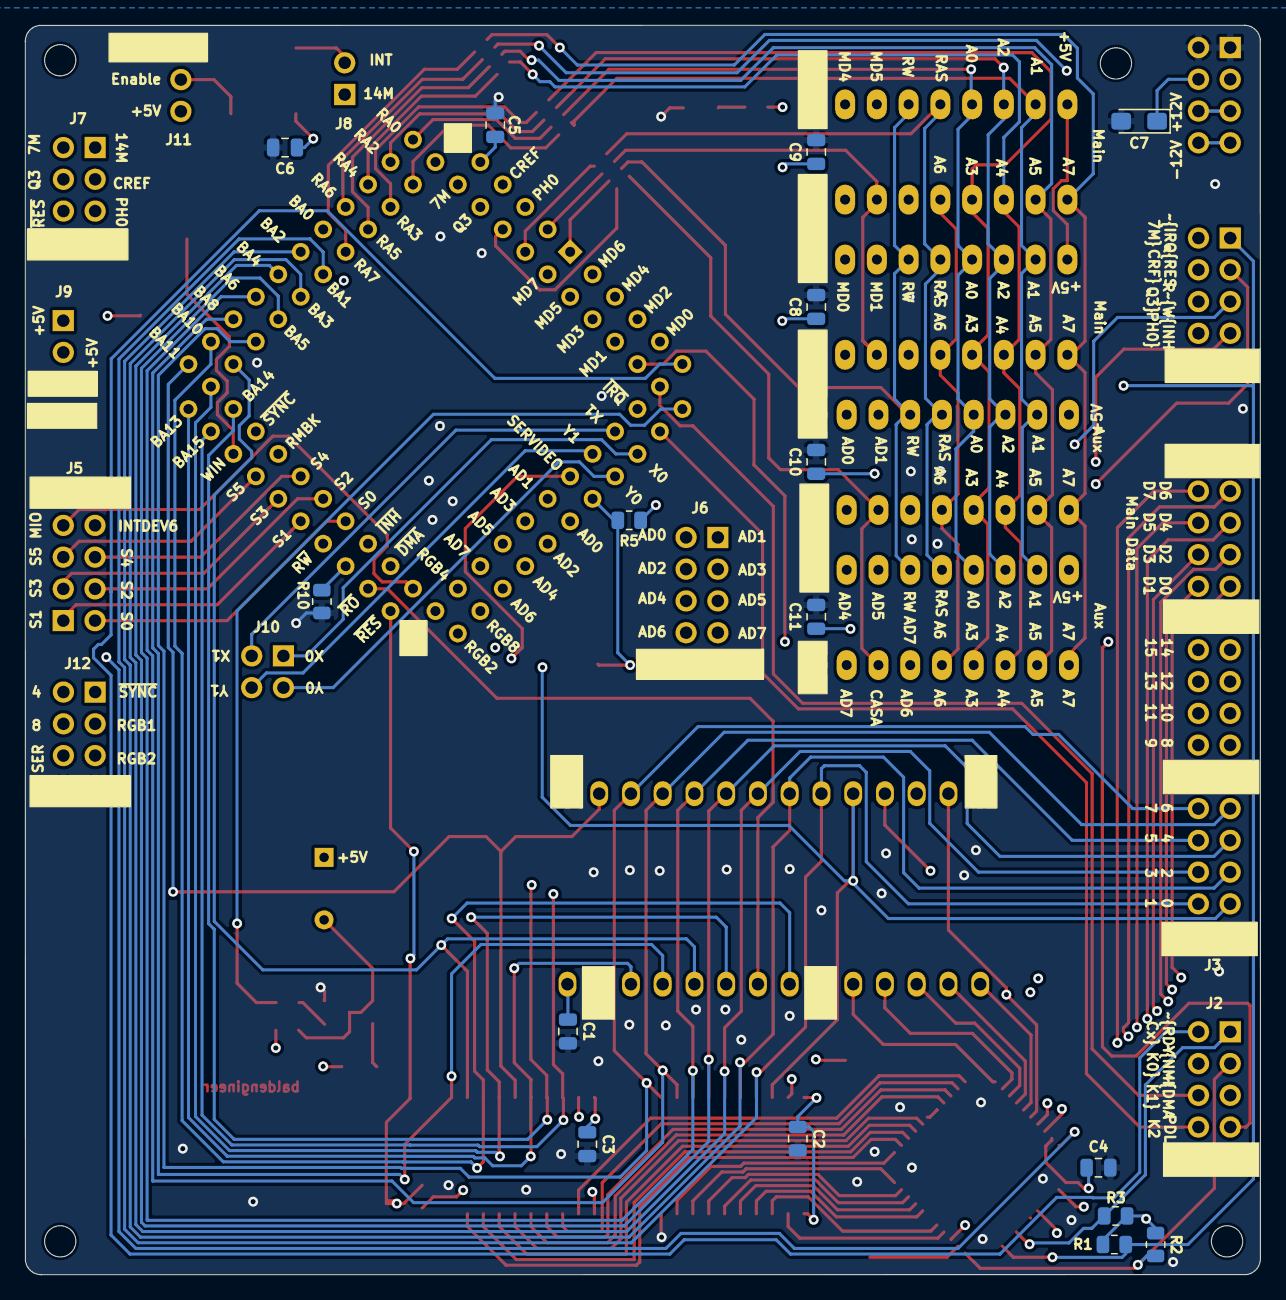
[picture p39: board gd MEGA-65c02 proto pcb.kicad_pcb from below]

Board: 4 copper layers, 98.8 x 99.9 mm, 60 parts (16 on the bottom side), 122 nets.

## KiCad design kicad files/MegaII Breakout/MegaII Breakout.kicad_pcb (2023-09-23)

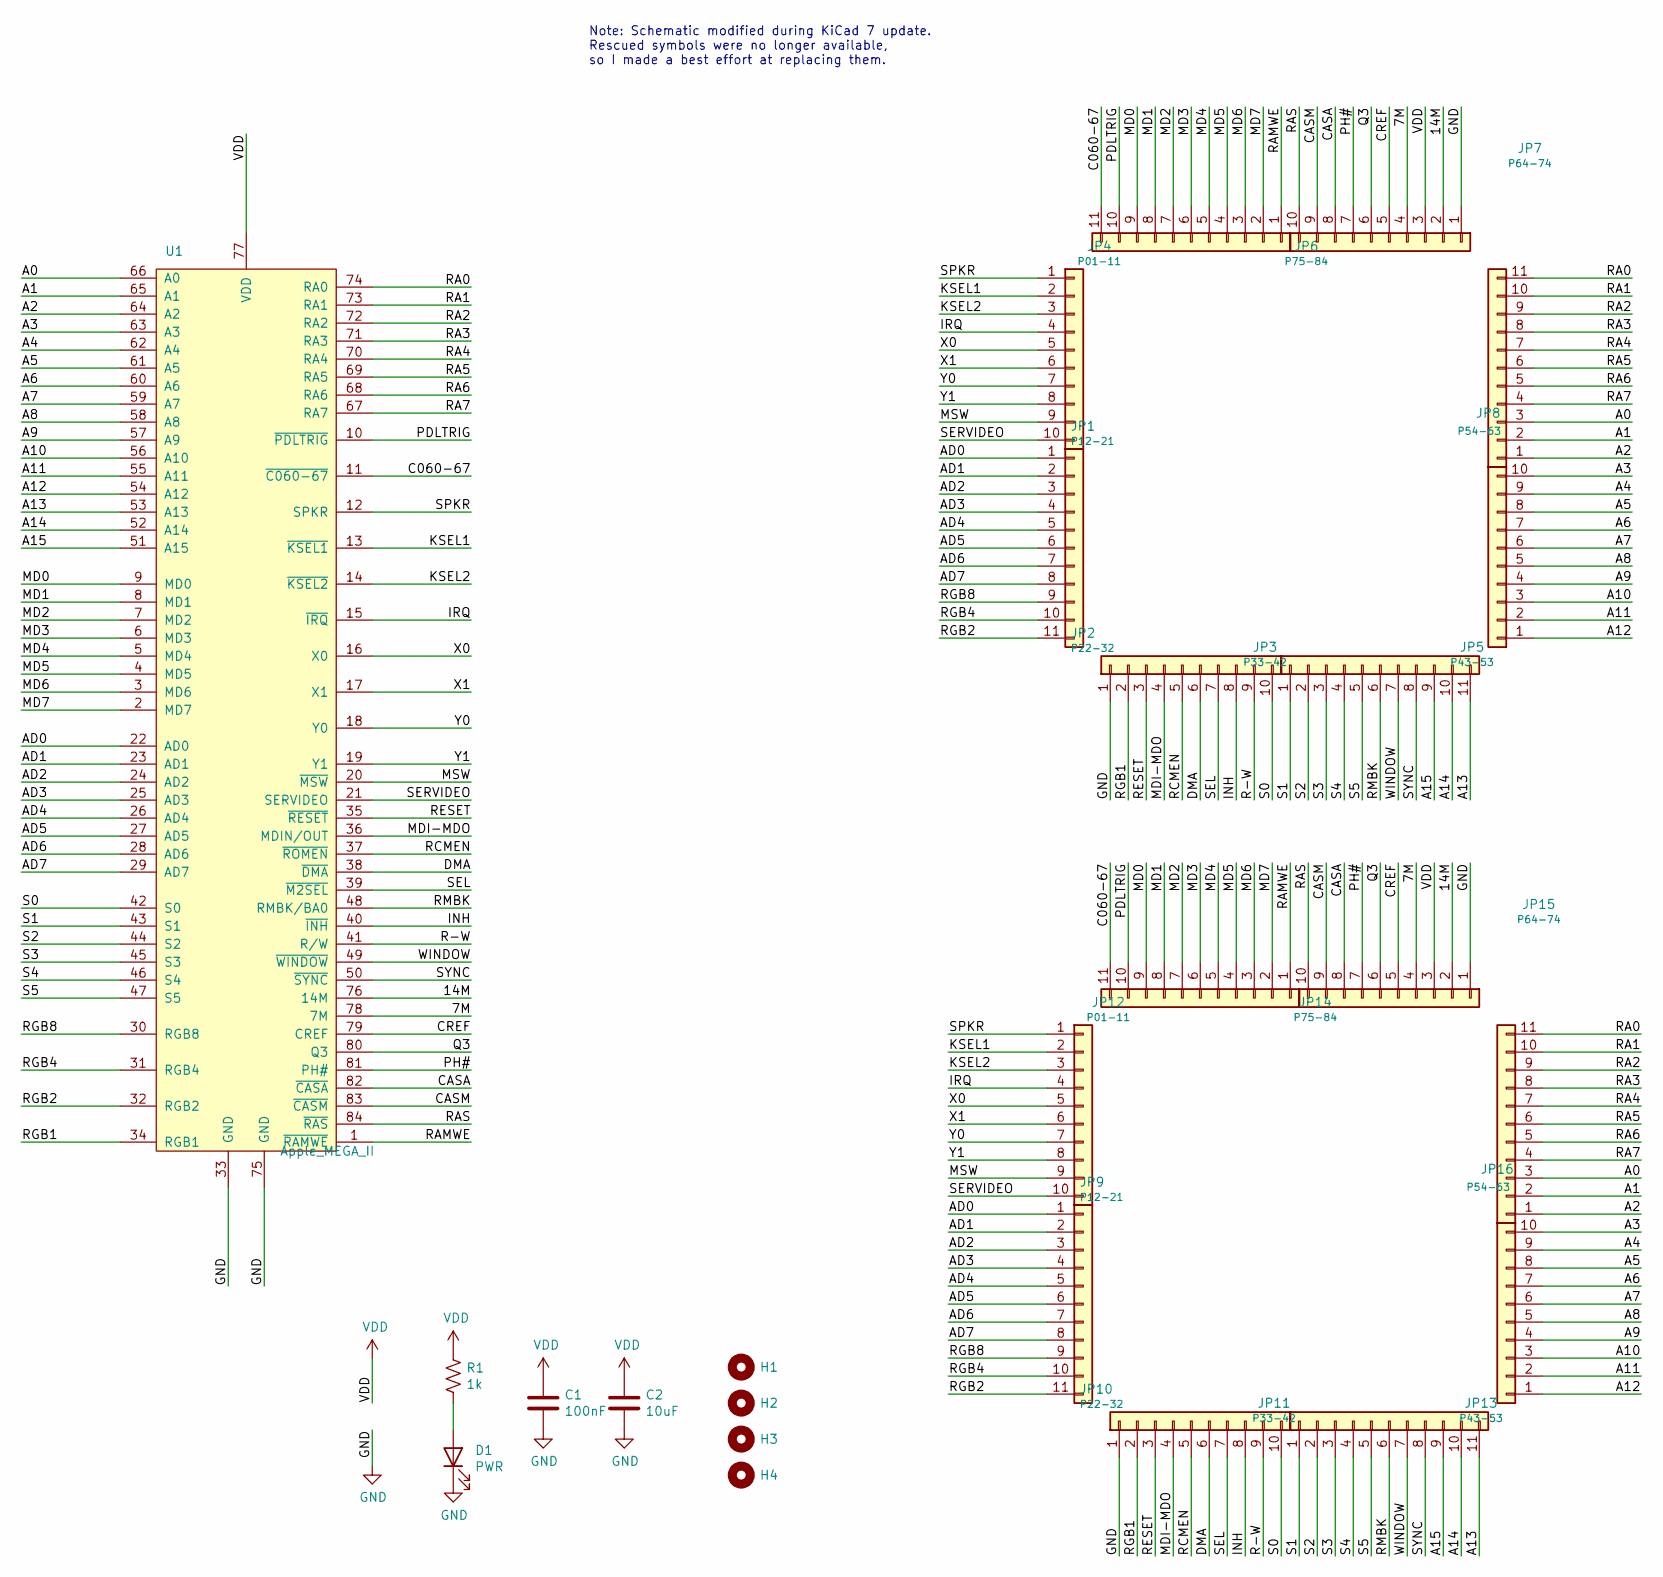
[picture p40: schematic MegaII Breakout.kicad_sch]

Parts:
C1: 100nF; C_0805_2012Metric
C2: 10uF; C_0805_2012Metric
D1: PWR; LED_1206_3216Metric
H1, H2, H3, H4: MountingHole; MountingHole_2.5mm
JP1, JP9: P12-21; PinHeader_1x10_P2.54mm_Vertical
JP2, JP10: P22-32; PinHeader_1x11_P2.54mm_Vertical
JP3, JP11: P33-42; PinHeader_1x10_P2.54mm_Vertical
JP4, JP12: P01-11; PinHeader_1x11_P2.54mm_Vertical
JP5, JP13: P43-53; PinHeader_1x11_P2.54mm_Vertical
JP6, JP14: P75-84; PinHeader_1x10_P2.54mm_Vertical
JP7, JP15: P64-74; PinHeader_1x11_P2.54mm_Vertical
JP8, JP16: P54-63; PinHeader_1x10_P2.54mm_Vertical
R1: 1k; R_0805_2012Metric
U1: Apple_MEGA_II; PLCC-84_THT-Socket

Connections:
/7M: JP6.4, JP14.4, U1.78 (7M)
/14M: JP6.2, JP14.2, U1.76 (14M)
/A0: JP7.3, JP15.3, U1.66 (A0)
/A1: JP7.2, JP15.2, U1.65 (A1)
/A2: JP7.1, JP15.1, U1.64 (A2)
/A3: JP8.10, JP16.10, U1.63 (A3)
/A4: JP8.9, JP16.9, U1.62 (A4)
/A5: JP8.8, JP16.8, U1.61 (A5)
/A6: JP8.7, JP16.7, U1.60 (A6)
/A7: JP8.6, JP16.6, U1.59 (A7)
/A8: JP8.5, JP16.5, U1.58 (A8)
/A9: JP8.4, JP16.4, U1.57 (A9)
/A10: JP8.3, JP16.3, U1.56 (A10)
/A11: JP8.2, JP16.2, U1.55 (A11)
/A12: JP8.1, JP16.1, U1.54 (A12)
/A13: JP5.11, JP13.11, U1.53 (A13)
/A14: JP5.10, JP13.10, U1.52 (A14)
/A15: JP5.9, JP13.9, U1.51 (A15)
/AD0: JP2.1, JP10.1, U1.22 (AD0)
/AD1: JP2.2, JP10.2, U1.23 (AD1)
/AD2: JP2.3, JP10.3, U1.24 (AD2)
/AD3: JP2.4, JP10.4, U1.25 (AD3)
/AD4: JP2.5, JP10.5, U1.26 (AD4)
/AD5: JP2.6, JP10.6, U1.27 (AD5)
/AD6: JP2.7, JP10.7, U1.28 (AD6)
/AD7: JP2.8, JP10.8, U1.29 (AD7)
/C060-67: JP4.11, JP12.11, U1.11 (~C060-67)
/CASA: JP6.8, JP14.8, U1.82 (~CASA)
/CASM: JP6.9, JP14.9, U1.83 (~CASM)
/CREF: JP6.5, JP14.5, U1.79 (CREF)
/DMA: JP3.6, JP11.6, U1.38 (~DMA)
/INH: JP3.8, JP11.8, U1.40 (~INH)
/IRQ: JP1.4, JP9.4, U1.15 (~IRQ)
/KSEL1: JP1.2, JP9.2, U1.13 (~KSEL1)
/KSEL2: JP1.3, JP9.3, U1.14 (~KSEL2)
/MD0: JP4.9, JP12.9, U1.9 (MD0)
/MD1: JP4.8, JP12.8, U1.8 (MD1)
/MD2: JP4.7, JP12.7, U1.7 (MD2)
/MD3: JP4.6, JP12.6, U1.6 (MD3)
/MD4: JP4.5, JP12.5, U1.5 (MD4)
/MD5: JP4.4, JP12.4, U1.4 (MD5)
/MD6: JP4.3, JP12.3, U1.3 (MD6)
/MD7: JP4.2, JP12.2, U1.2 (MD7)
/MDI-MDO: JP3.4, JP11.4, U1.36 (MDIN/OUT)
/MSW: JP1.9, JP9.9, U1.20 (~MSW)
/PDLTRIG: JP4.10, JP12.10, U1.10 (~PDLTRIG)
/PH#: JP6.7, JP14.7, U1.81 (PH#)
/Q3: JP6.6, JP14.6, U1.80 (Q3)
/R-W: JP3.9, JP11.9, U1.41 (R/W)
/RA0: JP7.11, JP15.11, U1.74 (RA0)
/RA1: JP7.10, JP15.10, U1.73 (RA1)
/RA2: JP7.9, JP15.9, U1.72 (RA2)
/RA3: JP7.8, JP15.8, U1.71 (RA3)
/RA4: JP7.7, JP15.7, U1.70 (RA4)
/RA5: JP7.6, JP15.6, U1.69 (RA5)
/RA6: JP7.5, JP15.5, U1.68 (RA6)
/RA7: JP7.4, JP15.4, U1.67 (RA7)
/RAMWE: JP4.1, JP12.1, U1.1 (~RAMWE)
/RAS: JP6.10, JP14.10, U1.84 (~RAS)
/RCMEN: JP3.5, JP11.5, U1.37 (~ROMEN)
/RESET: JP3.3, JP11.3, U1.35 (~RESET)
/RGB1: JP3.2, JP11.2, U1.34 (RGB1)
/RGB2: JP2.11, JP10.11, U1.32 (RGB2)
/RGB4: JP2.10, JP10.10, U1.31 (RGB4)
/RGB8: JP2.9, JP10.9, U1.30 (RGB8)
/RMBK: JP5.6, JP13.6, U1.48 (RMBK/BA0)
/S0: JP3.10, JP11.10, U1.42 (S0)
/S1: JP5.1, JP13.1, U1.43 (S1)
/S2: JP5.2, JP13.2, U1.44 (S2)
/S3: JP5.3, JP13.3, U1.45 (S3)
/S4: JP5.4, JP13.4, U1.46 (S4)
/S5: JP5.5, JP13.5, U1.47 (S5)
/SEL: JP3.7, JP11.7, U1.39 (~M2SEL)
/SERVIDEO: JP1.10, JP9.10, U1.21 (SERVIDEO)
/SPKR: JP1.1, JP9.1, U1.12 (SPKR)
/SYNC: JP5.8, JP13.8, U1.50 (~SYNC)
/WINDOW: JP5.7, JP13.7, U1.49 (~WINDOW)
/X0: JP1.5, JP9.5, U1.16 (X0)
/X1: JP1.6, JP9.6, U1.17 (X1)
/Y0: JP1.7, JP9.7, U1.18 (Y0)
/Y1: JP1.8, JP9.8, U1.19 (Y1)
GND: C1.2, C2.2, D1.1 (K), JP3.1, JP6.1, JP11.1, JP14.1, U1.33 (GND), U1.75 (GND)
unnamed: D1.2 (A), R1.2
VDD: C1.1, C2.1, JP6.3, JP14.3, R1.1, U1.77 (VDD)

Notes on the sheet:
Note: Schematic modified during KiCad 7 update. Rescued symbols were no longer available, so I made a best effort at replacing them.

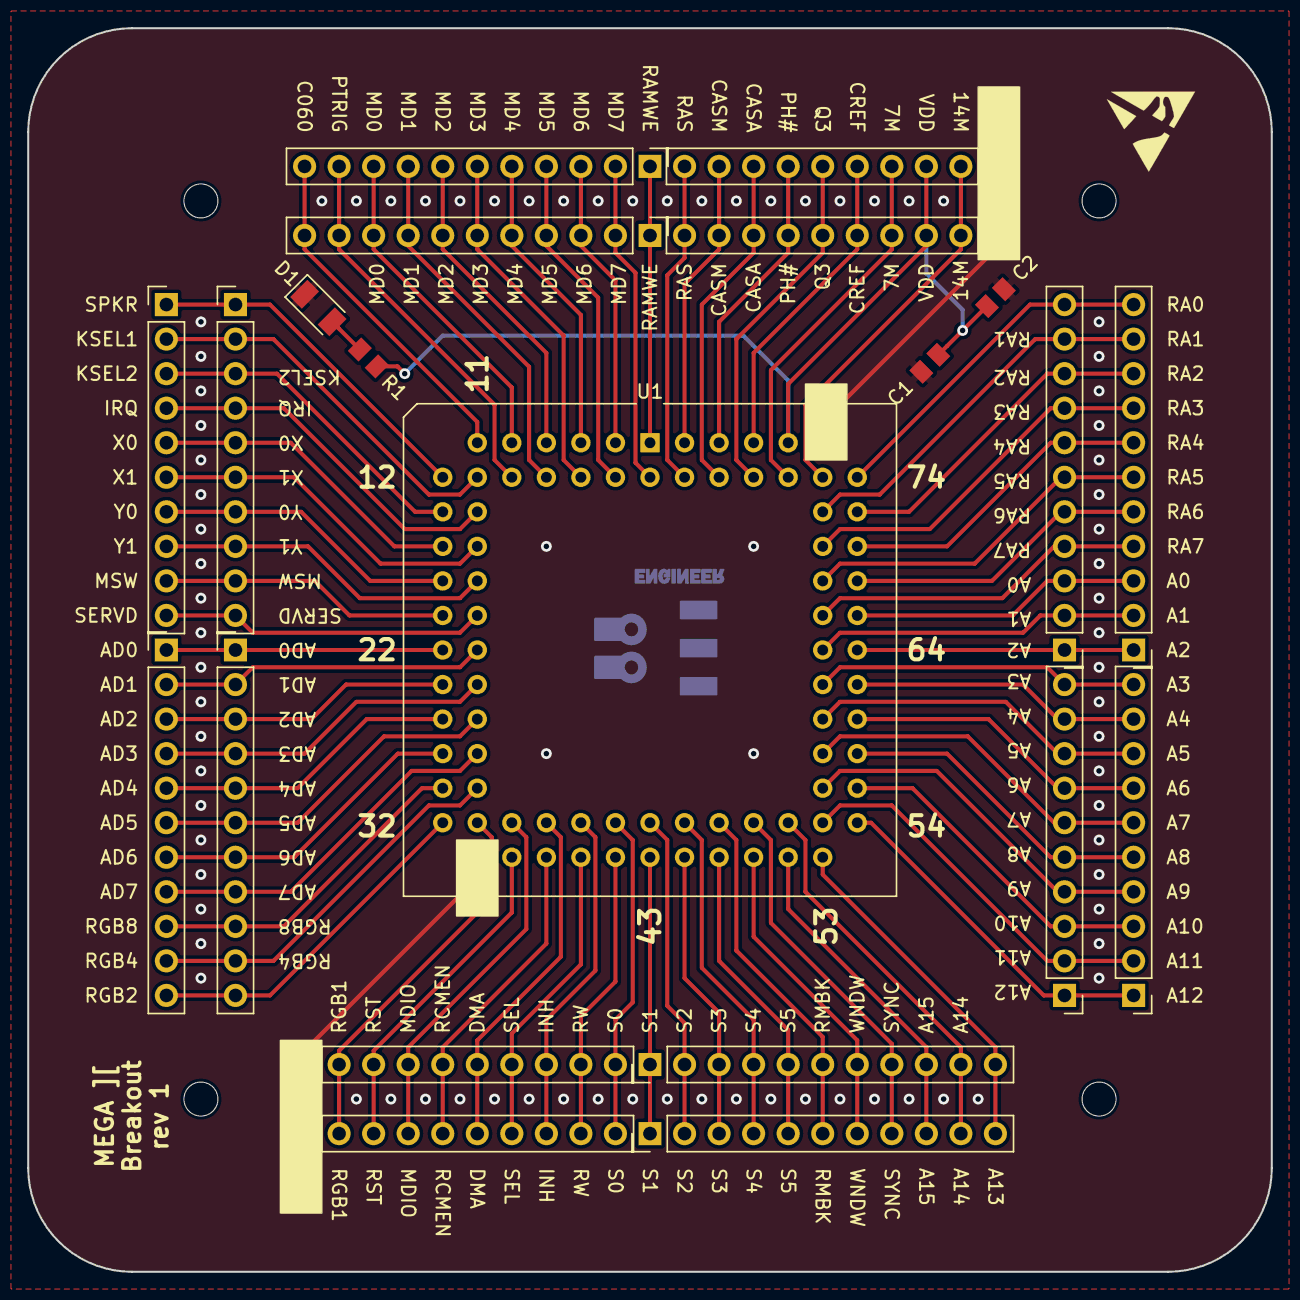
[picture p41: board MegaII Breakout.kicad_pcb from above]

Board: 2 copper layers, 91.4 x 91.4 mm, 26 parts (1 on the bottom side), 84 nets.

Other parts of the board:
svg2mod: G***; BE10v2

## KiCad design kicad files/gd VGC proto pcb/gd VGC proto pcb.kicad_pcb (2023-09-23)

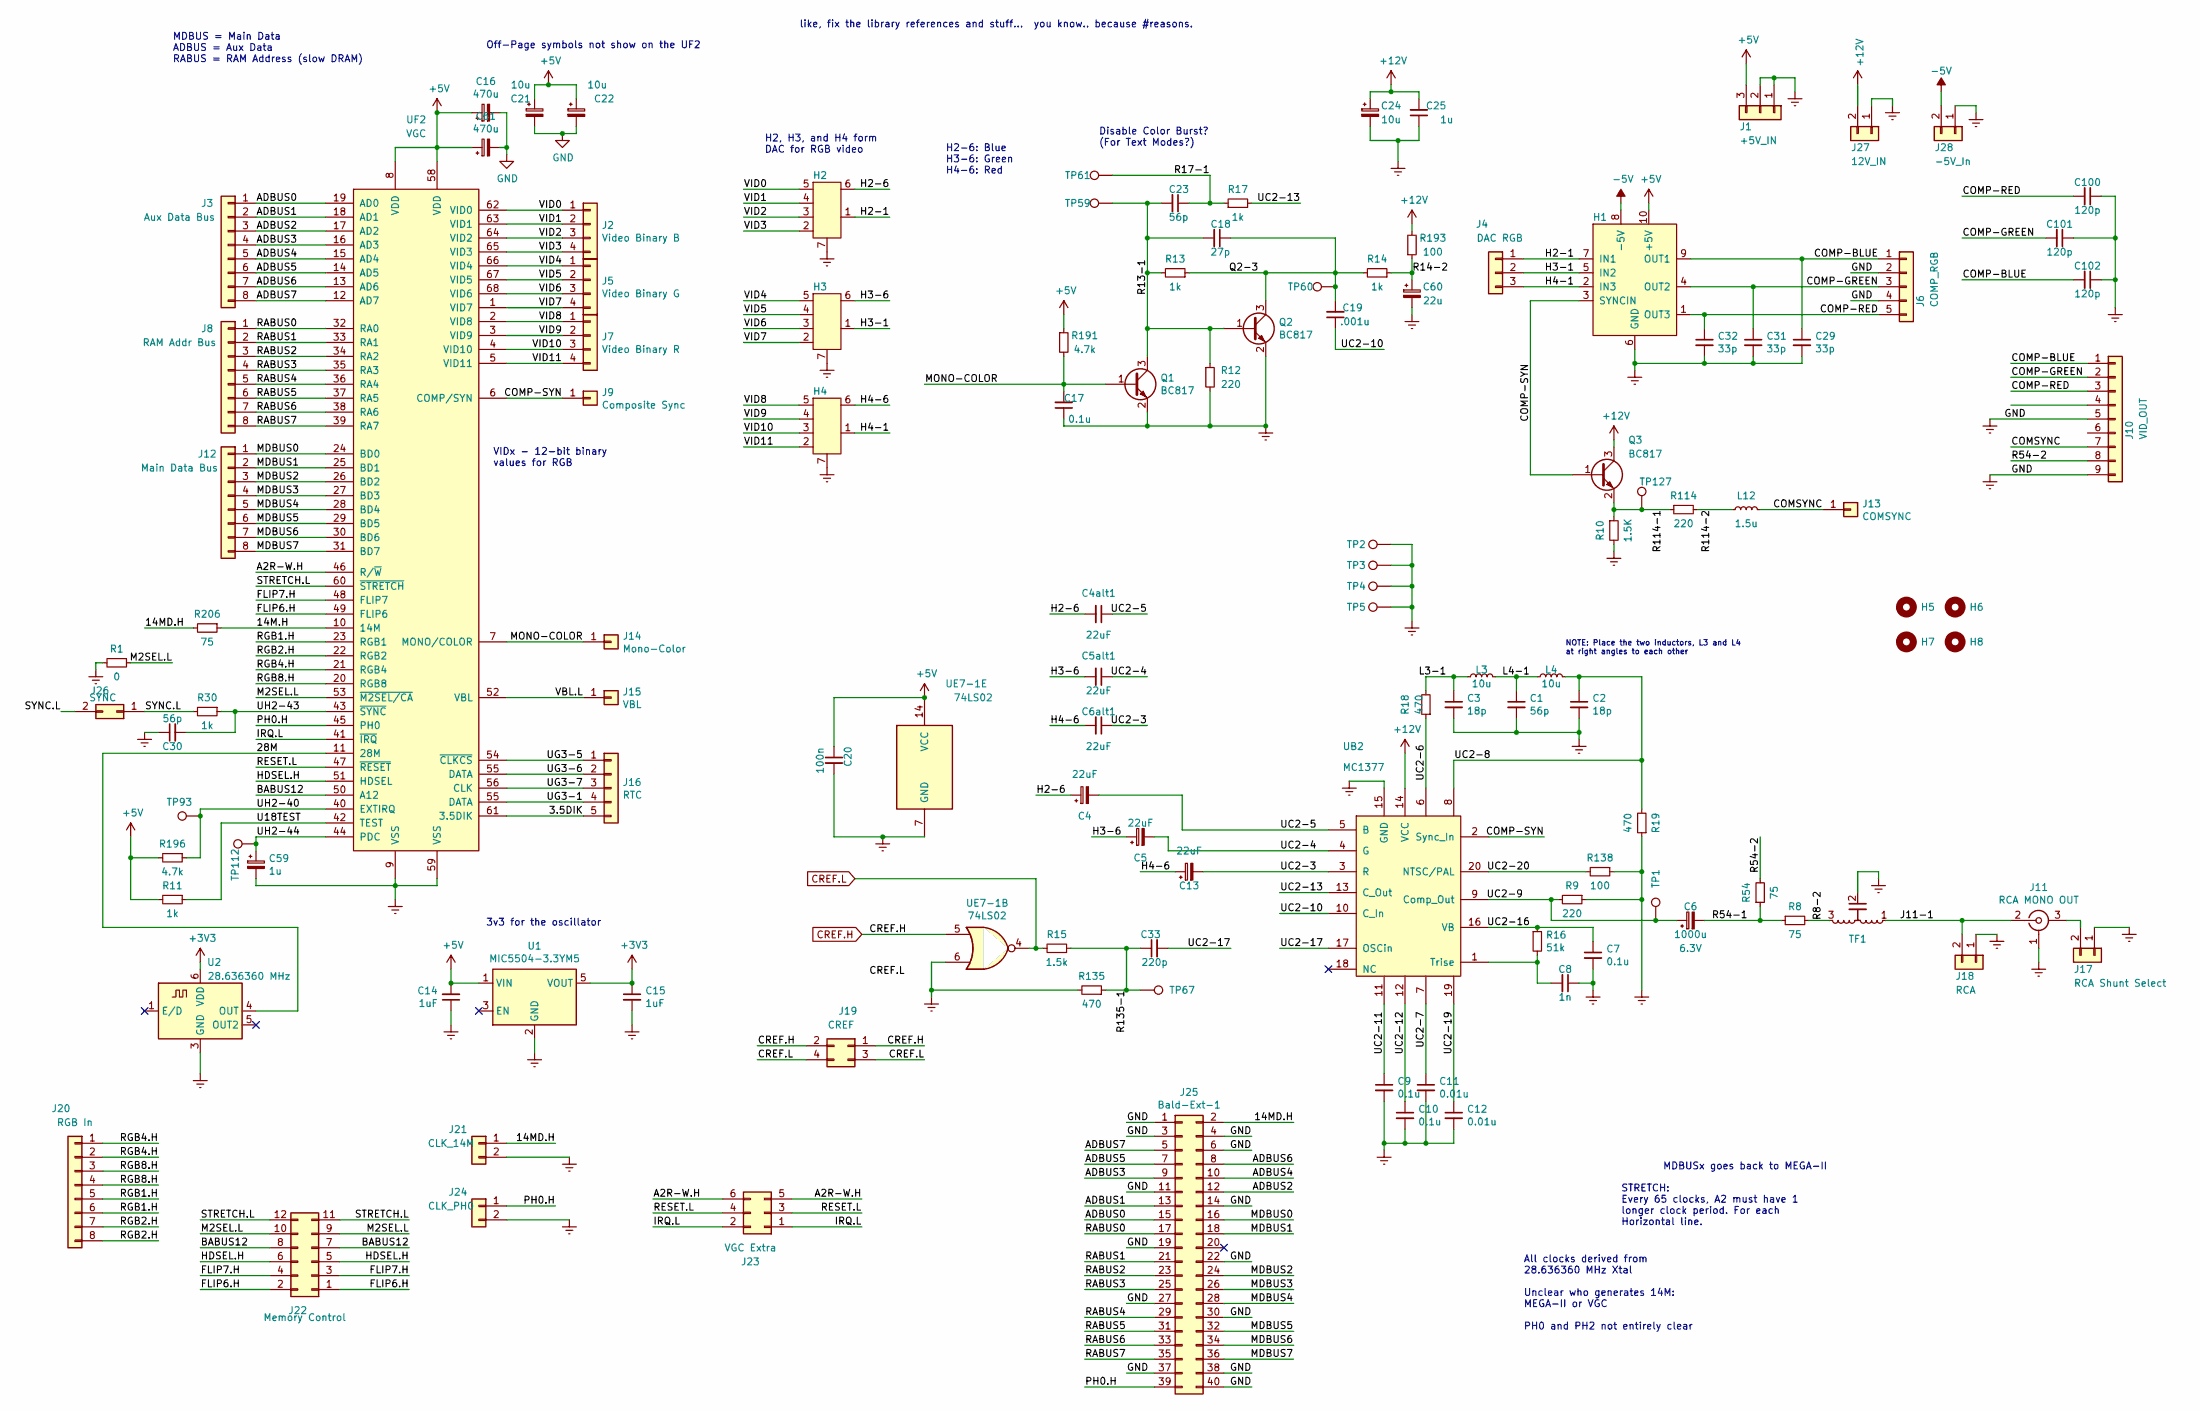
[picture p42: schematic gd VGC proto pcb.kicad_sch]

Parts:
C1, C23, C30: 56p; C_0805_2012Metric
C2, C3: 18p; C_0805_2012Metric
C4, C5, C13: 22uF; CP_Radial_D5.0mm_P2.00mm
C4alt1, C5alt1, C6alt1: 22uF; C_0805_2012Metric
C6: 1000u; CP_Radial_D10.0mm_P2.50mm; Voltage 6.3V
C7, C9, C10, C17: 0.1u; C_0805_2012Metric
C8: 1n; C_0805_2012Metric
C11, C12: 0.01u; C_0805_2012Metric
C14, C15: 1uF; C_0805_2012Metric
C16, C61: 470u; CP_Radial_D10.0mm_P2.50mm
C18: 27p; C_0805_2012Metric
C19: .001u; C_0805_2012Metric
C20: 100n; C_0805_2012Metric
C21, C22, C24: 10u; CP_Radial_D5.0mm_P2.50mm
C25, C59: 1u; C_0805_2012Metric
C29, C31, C32: 33p; C_0805_2012Metric
C33: 220p; C_0805_2012Metric
C60: 22u; CP_Radial_D5.0mm_P2.50mm
C100, C101, C102: 120p; C_0805_2012Metric
H1: Video_Sync; R_Array_SIP10
H2, H3, H4: VideoThingy; R_Array_SIP7
H5, H6, H7, H8: MountingHole; MountingHole_2.7mm_M2.5
J1: +5V_IN; PinHeader_1x03_P2.54mm_Vertical
J2: Video Binary B; PinHeader_1x04_P2.54mm_Vertical
J3: Aux Data Bus; PinHeader_1x08_P2.54mm_Vertical
J4: DAC RGB; PinHeader_1x03_P2.54mm_Vertical
J5: Video Binary G; PinHeader_1x04_P2.54mm_Vertical
J6: COMP_RGB; PinHeader_1x05_P2.54mm_Vertical
J7: Video Binary R; PinHeader_1x04_P2.54mm_Vertical
J8: RAM Addr Bus; PinHeader_1x08_P2.54mm_Vertical
J9: Composite Sync; PinHeader_1x01_P2.54mm_Vertical
J10: VID_OUT; PinHeader_1x09_P2.54mm_Vertical
J11: RCA MONO OUT; Jack_RCA_Switchcraft_PJRAN1X1UxxX; MPN PJRAN1X1U02AUX
J12: Main Data Bus; PinHeader_1x08_P2.54mm_Vertical
J13: COMSYNC; PinHeader_1x01_P2.54mm_Vertical
J14: Mono-Color; PinHeader_1x01_P2.54mm_Vertical
J15: VBL; PinHeader_1x01_P2.54mm_Vertical
J16: RTC; PinHeader_1x05_P2.54mm_Vertical
J17: RCA Shunt Select; PinHeader_1x02_P2.54mm_Vertical
J18: RCA; PinHeader_1x02_P2.54mm_Vertical
J19: CREF; PinHeader_2x02_P2.54mm_Vertical
J20: RGB In; PinHeader_1x08_P2.54mm_Vertical
J21: CLK_14M; PinHeader_1x02_P2.54mm_Vertical
J22: Memory Control; PinHeader_2x06_P2.54mm_Vertical
J23: VGC Extra; PinHeader_2x03_P2.54mm_Vertical
J24: CLK_PH0; PinHeader_1x02_P2.54mm_Vertical
J25: Bald-Ext-1; PinHeader_2x20_P2.54mm_Vertical
J26: SYNC; PinHeader_1x02_P2.54mm_Vertical
J27: 12V_IN; PinHeader_1x02_P2.54mm_Vertical
J28: -5V_In; PinHeader_1x02_P2.54mm_Vertical
L3, L4: 10u; L_Axial_L6.6mm_D2.7mm_P10.16mm_Horizontal_Vishay_IM-2
L12: 1.5u; L_Axial_L6.6mm_D2.7mm_P10.16mm_Horizontal_Vishay_IM-2
Q1, Q2, Q3: BC817; SOT-23
R1: 0; R_0805_2012Metric
R8, R54, R206: 75; R_0805_2012Metric
R9, R12, R114: 220; R_0805_2012Metric
R10: 1.5K; R_0805_2012Metric
R11, R13, R14, R17, R30: 1k; R_0805_2012Metric
R15: 1.5k; R_0805_2012Metric
R16: 51k; R_0805_2012Metric
R18, R19, R135: 470; R_0805_2012Metric
R138, R193: 100; R_0805_2012Metric
R191, R196: 4.7k; R_0805_2012Metric
TF1: CapacitiveTransformer; TO-92
TP1, TP2, TP3, TP4, TP5, TP59, TP60, TP61, TP67, TP93, TP112, TP127: TestPoint; Harwin-S1751-46-Test-Point
U1: MIC5504-3.3YM5; SOT-23-5
U2: 28.636360 MHz; Oscillator_SMD_IDT_JU6-6_7.0x5.0mm_P2.54mm
UB2: MC1377; DIP-20_W7.62mm_Socket
UE7-1: 74LS02; SOIC-14_3.9x8.7mm_P1.27mm
UF2: VGC; PLCC-68_THT-Socket

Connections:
+3V3: C15.1, U1.5 (VOUT), U2.6 (VDD)
+5V: C14.2, C16.1, C20.1, C21.1, C22.1, C61.1, H1.10 (+5V), J1.3, R11.2, R191.1, R196.2, U1.1 (VIN), UE7-1.14 (VCC), UF2.8 (VDD), UF2.58 (VDD)
+12V: C24.1, C25.2, J27.2, Q3.3 (C), R193.2, UB2.14 (VCC)
-5V: H1.8 (-5V), J28.2
/3.5DIK: J16.5, UF2.61 (3.5DIK)
/14M.H: R206.1, UF2.10 (14M)
/14MD.H: J21.1, J25.2, R206.2
/28M: U2.4 (OUT), UF2.11 (28M)
/A2R-W.H: J23.5, J23.6, UF2.46 (R/~W)
/ADBUS0: J3.1, J25.15, UF2.19 (AD0)
/ADBUS1: J3.2, J25.13, UF2.18 (AD1)
/ADBUS2: J3.3, J25.12, UF2.17 (AD2)
/ADBUS3: J3.4, J25.9, UF2.16 (AD3)
/ADBUS4: J3.5, J25.10, UF2.15 (AD4)
/ADBUS5: J3.6, J25.7, UF2.14 (AD5)
/ADBUS6: J3.7, J25.8, UF2.13 (AD6)
/ADBUS7: J3.8, J25.5, UF2.12 (AD7)
/BABUS12: J22.7, J22.8, UF2.50 (A12)
/COMP-BLUE: C29.1, C102.2, H1.9 (OUT1), J6.1, J10.1
/COMP-GREEN: C31.1, C101.2, H1.4 (OUT2), J6.3, J10.2
/COMP-RED: C32.1, C100.2, H1.1 (OUT3), J6.5, J10.3
/COMP-SYN: H1.3 (SYNCIN), J9.1, Q3.1 (B), UB2.2 (Sync_In), UF2.6 (COMP/SYN)
/COMSYNC: J10.7, J13.1, L12.2
/FLIP6.H: J22.1, J22.2, UF2.49 (FLIP6)
/FLIP7.H: J22.3, J22.4, UF2.48 (FLIP7)
/H2-1: H1.7 (IN1), H2.1, J4.1
/H2-6: C4.1, C4alt1.2, H2.6
/H3-1: H1.5 (IN2), H3.1, J4.2
/H3-6: C5.1, C5alt1.2, H3.6
/H4-1: H1.2 (IN3), H4.1, J4.3
/H4-6: C6alt1.2, C13.1, H4.6
/HDSEL.H: J22.5, J22.6, UF2.51 (HDSEL)
/IRQ.L: J23.1, J23.2, UF2.41 (~IRQ)
/J11-1: J11.2 (In), J18.2, TF1.1
/L3-1: C3.1, L3.1, R18.2
/L4-1: C1.1, L3.2, L4.1
/M2SEL.L: J22.9, J22.10, R1.1, UF2.53 (~M2SEL/CA)
/MDBUS0: J12.1, J25.16, UF2.24 (BD0)
/MDBUS1: J12.2, J25.18, UF2.25 (BD1)
/MDBUS2: J12.3, J25.24, UF2.26 (BD2)
/MDBUS3: J12.4, J25.26, UF2.27 (BD3)
/MDBUS4: J12.5, J25.28, UF2.28 (BD4)
/MDBUS5: J12.6, J25.32, UF2.29 (BD5)
/MDBUS6: J12.7, J25.34, UF2.30 (BD6)
/MDBUS7: J12.8, J25.36, UF2.31 (BD7)
/MONO-COLOR: C17.2, J14.1, Q1.1 (B), R191.2, UF2.7 (MONO/COLOR)
/PH0.H: J24.1, J25.39, UF2.45 (PH0)
/Q2-3: C18.1, C19.2, Q2.3 (C), R13.1, R14.2, TP60.1
/R8-2: R8.2, TF1.3
/R13-1: C18.2, C23.2, Q1.3 (C), Q2.1 (B), R12.1, R13.2, TP59.1
/R14-2: C60.1, R14.1, R193.1
/R17-1: C23.1, R17.1, TP61.1
/R54-1: C6.2, R8.1, R54.1
/R54-2: J10.8, R54.2
/R114-1: Q3.2 (E), R10.1, R114.1, TP127.1
/R114-2: L12.1, R114.2
/R135-1: C33.1, R15.1, R135.1, TP67.1
/RABUS0: J8.1, J25.17, UF2.32 (RA0)
/RABUS1: J8.2, J25.21, UF2.33 (RA1)
/RABUS2: J8.3, J25.23, UF2.34 (RA2)
/RABUS3: J8.4, J25.25, UF2.35 (RA3)
/RABUS4: J8.5, J25.29, UF2.36 (RA4)
/RABUS5: J8.6, J25.31, UF2.37 (RA5)
/RABUS6: J8.7, J25.33, UF2.38 (RA6)
/RABUS7: J8.8, J25.35, UF2.39 (RA7)
/RESET.L: J23.3, J23.4, UF2.47 (~RESET)
/RGB1.H: J20.5, J20.6, UF2.23 (RGB1)
/RGB2.H: J20.7, J20.8, UF2.22 (RGB2)
/RGB4.H: J20.1, J20.2, UF2.21 (RGB4)
/RGB8.H: J20.3, J20.4, UF2.20 (RGB8)
/STRETCH.L: J22.11, J22.12, UF2.60 (~STRETCH)
/SYNC.L: J26.1, J26.2, R30.2
/U18TEST: R11.1, UF2.42 (TEST)
/UC2-3: C6alt1.1, C13.2, UB2.3 (R)
/UC2-4: C5.2, C5alt1.1, UB2.4 (G)
/UC2-5: C4.2, C4alt1.1, UB2.5 (B)
/UC2-6: R18.1, UB2.6
/UC2-7: C11.1, UB2.7
/UC2-8: C2.1, L4.2, R19.2, UB2.8
/UC2-9: C6.1, R9.2, TP1.1, UB2.9 (Comp_Out)
/UC2-10: C19.1, UB2.10 (C_In)
/UC2-11: C9.1, UB2.11
/UC2-12: C10.1, UB2.12
/UC2-13: R17.2, UB2.13 (C_Out)
/UC2-16: C7.1, R16.1, UB2.16 (VB)
/UC2-17: C33.2, UB2.17 (OSCin)
/UC2-19: C12.1, UB2.19
/UC2-20: R138.2, UB2.20 (NTSC/PAL)
/UG3-5: J16.1, UF2.54 (~CLKCS)
/UG3-7: J16.3, UF2.56 (CLK)
/UH2-40: R196.1, TP93.1, UF2.40 (EXTIRQ)
/UH2-43: C30.2, R30.1, UF2.43 (~SYNC)
/UH2-44: C59.1, TP112.1, UF2.44 (PDC)
/VBL.L: J15.1, UF2.52 (VBL)
/VID0: H2.5, J2.1, UF2.62 (VID0)
/VID1: H2.4, J2.2, UF2.63 (VID1)
/VID2: H2.3, J2.3, UF2.64 (VID2)
/VID3: H2.2, J2.4, UF2.65 (VID3)
/VID4: H3.5, J5.1, UF2.66 (VID4)
/VID5: H3.4, J5.2, UF2.67 (VID5)
/VID6: H3.3, J5.3, UF2.68 (VID6)
/VID7: H3.2, J5.4, UF2.1 (VID7)
/VID8: H4.5, J7.1, UF2.2 (VID8)
/VID9: H4.4, J7.2, UF2.3 (VID9)
/VID10: H4.3, J7.3, UF2.4 (VID10)
/VID11: H4.2, J7.4, UF2.5 (VID11)
CREF.H: J19.1, J19.2, UE7-1.5
CREF.L: J19.3, J19.4, R15.2, UE7-1.4
GND: C1.2, C2.2, C3.2, C7.2, C8.1, C9.2, C10.2, C11.2, C12.2, C14.1, C15.2, C16.2, C17.1, C20.2, C21.2, C22.2, C24.2, C25.1, C29.2, C30.1, C31.2, C32.2, C59.2, C60.2, C61.2, C100.1, C101.1, C102.1, H1.6 (GND), H2.7, H3.7, H4.7, J1.1, J1.2, J6.2, J6.4, J10.5, J10.9, J11.1 (Ext), J17.1, J18.1, J21.2, J24.2, J25.1, J25.3, J25.4, J25.6, J25.11, J25.14, J25.19, J25.22, J25.27, J25.30, J25.37, J25.38, J25.40, J27.1, J28.1, Q1.2 (E), Q2.2 (E), R1.2, R9.1, R10.2, R12.2, R19.1, R135.2, R138.1, TF1.2, TP2.1, TP3.1, TP4.1, TP5.1, U1.2 (GND), U2.3 (GND), UB2.15 (GND), UE7-1.6, UE7-1.7 (GND), UF2.9 (VSS), UF2.59 (VSS)
unnamed: C8.2, R16.2, UB2.1 (Trise)
unnamed: J11.3, J17.2

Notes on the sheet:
MDBUSx goes back to MEGA-II
MDBUS = Main Data ADBUS = Aux Data RABUS = RAM Address (slow DRAM)
Off-Page symbols not show on the UF2
H2, H3, and H4 form DAC for RGB video
Disable Color Burst? (For Text Modes?)
3v3 for the oscillator
H2-6: Blue H3-6: Green H4-6: Red
VIDx - 12-bit binary values for RGB
All clocks derived from 28.636360 MHz Xtal Unclear who generates 14M: MEGA-II or VGC PH0 and PH2 not entirely clear
STRETCH: Every 65 clocks, A2 must have 1 longer clock period. For each Horizontal line.
like, fix the library references and stuff... you know.. because #reasons.
NOTE: Place the two inductors, L3 and L4 at right angles to each other

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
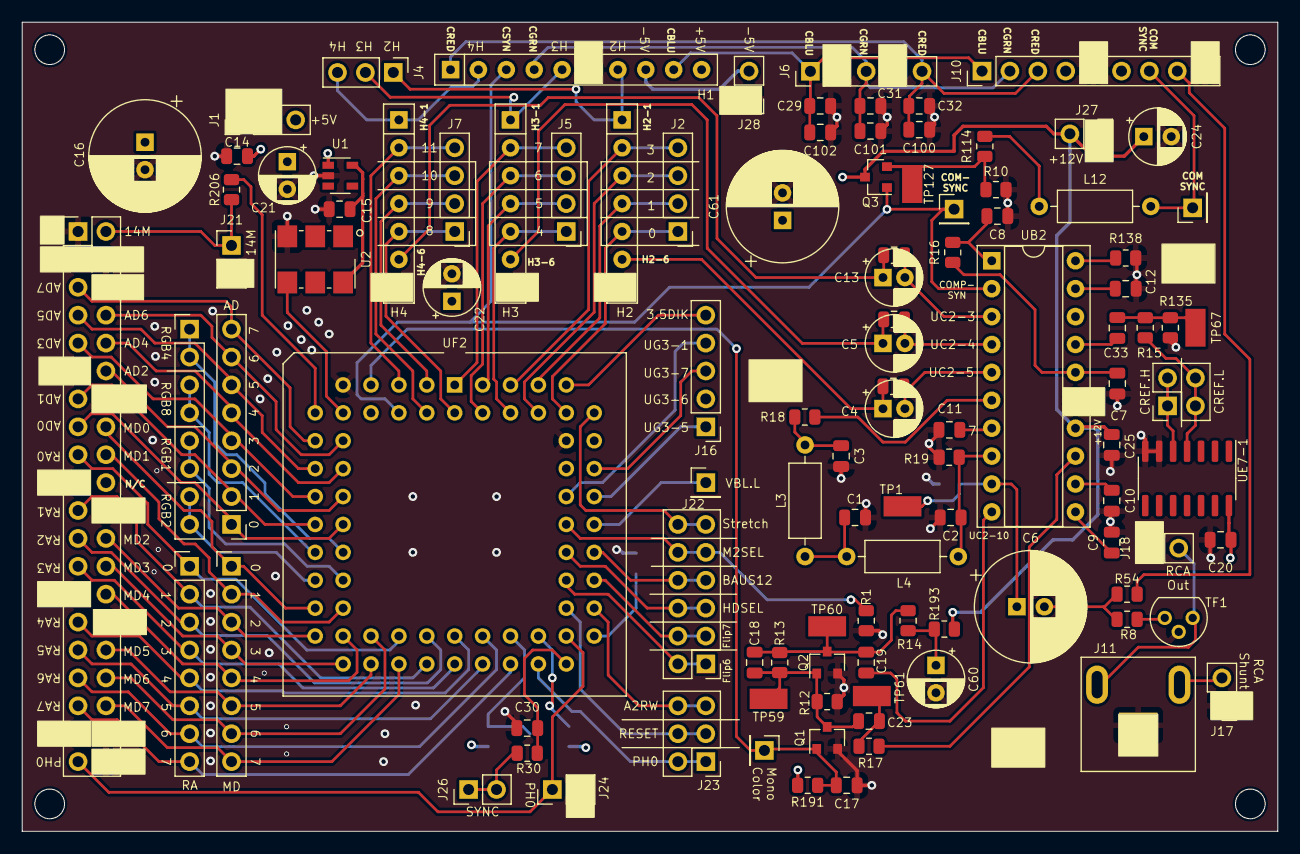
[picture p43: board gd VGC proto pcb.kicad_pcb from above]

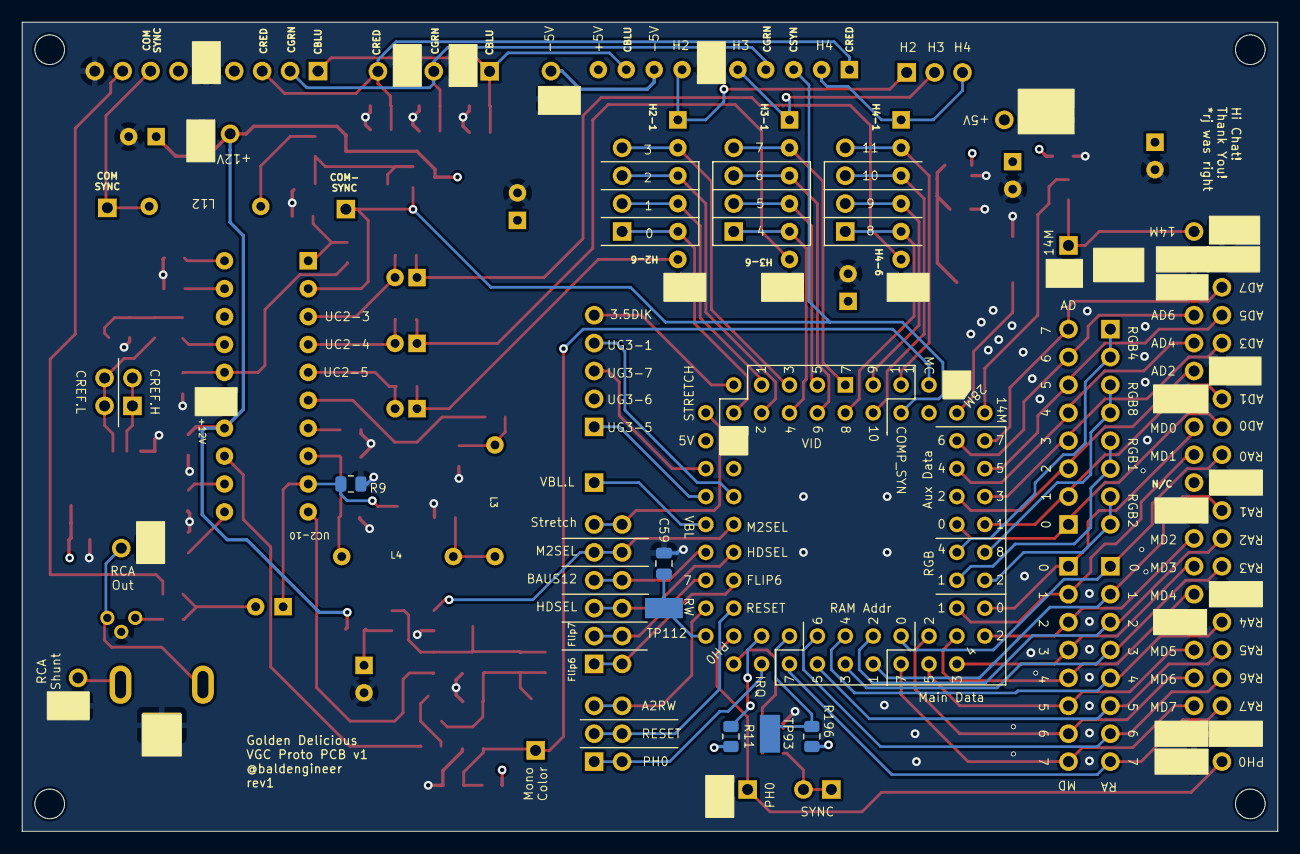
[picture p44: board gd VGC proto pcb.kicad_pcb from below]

Board: 4 copper layers, 114.3 x 73.7 mm, 121 parts (7 on the bottom side), 112 nets.

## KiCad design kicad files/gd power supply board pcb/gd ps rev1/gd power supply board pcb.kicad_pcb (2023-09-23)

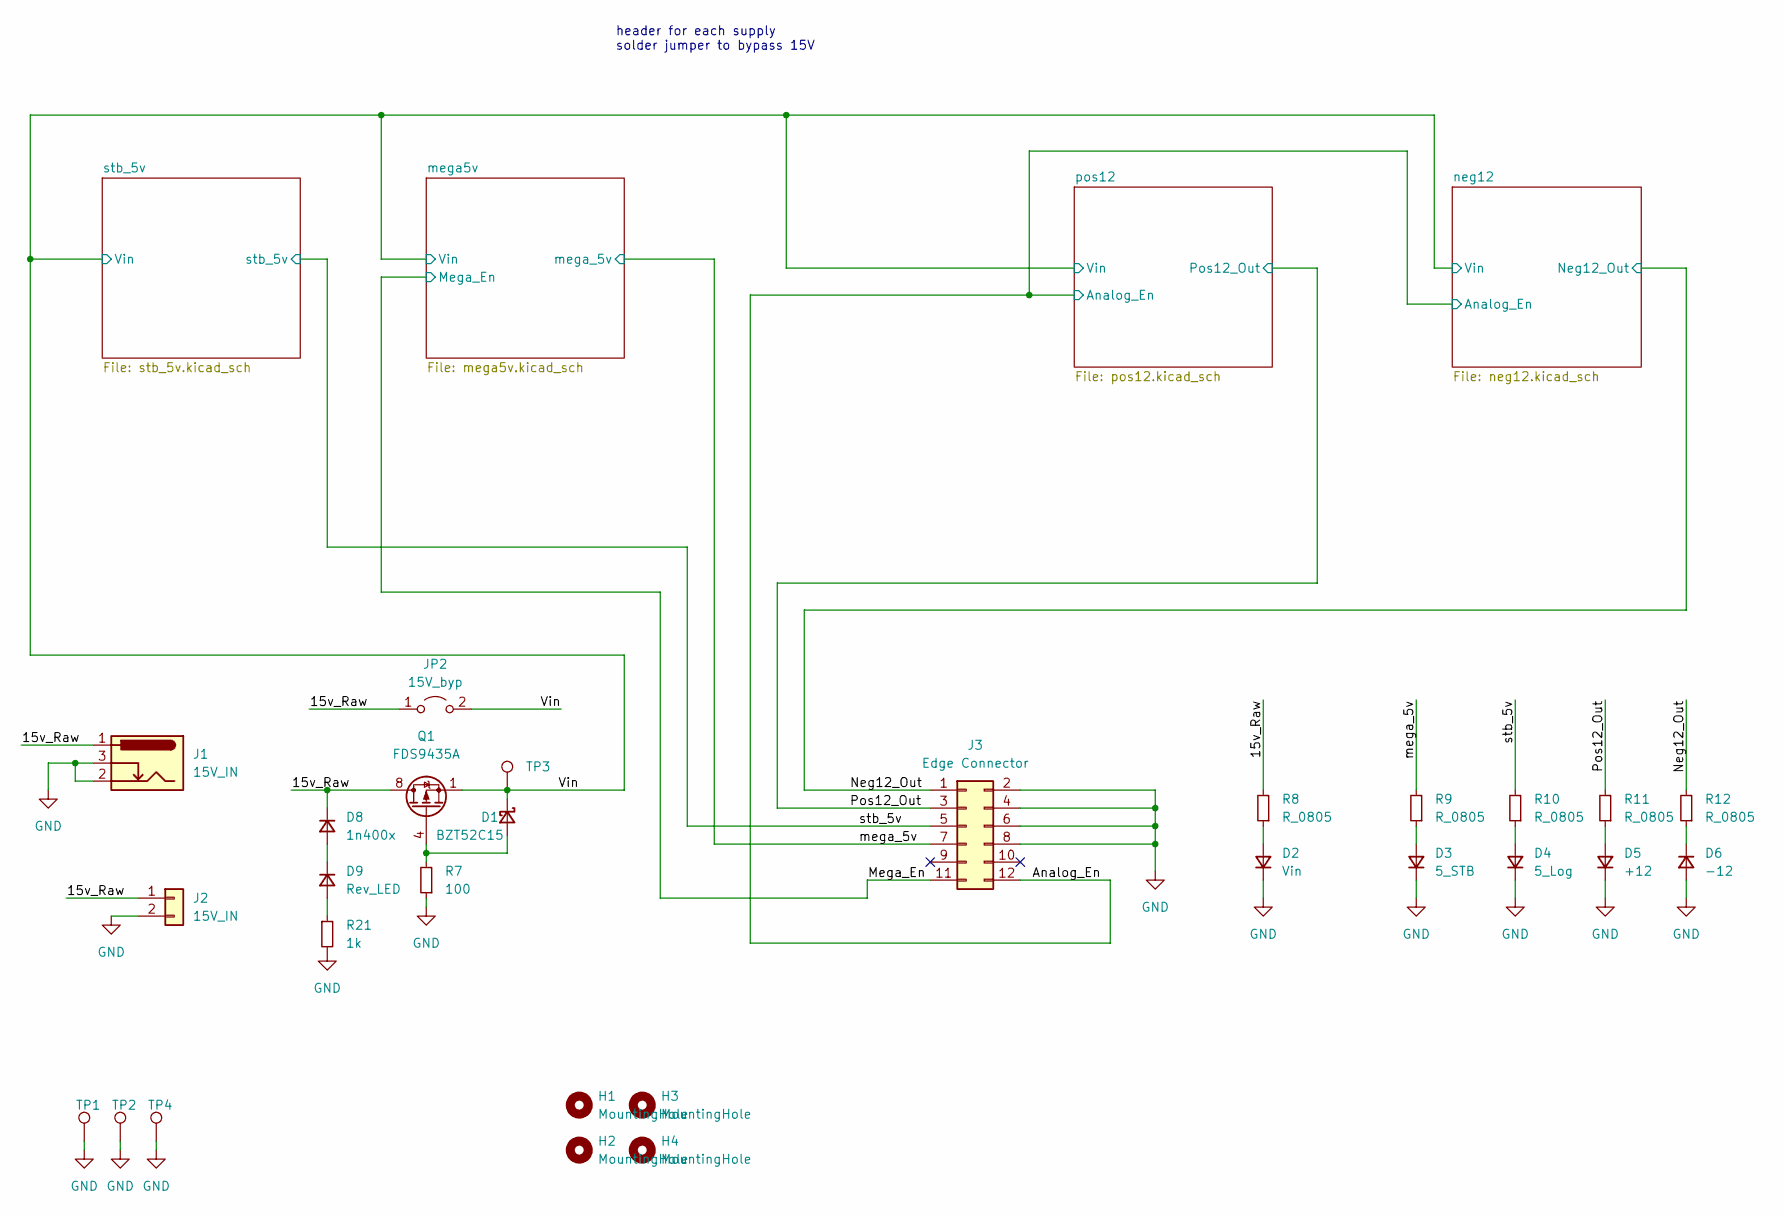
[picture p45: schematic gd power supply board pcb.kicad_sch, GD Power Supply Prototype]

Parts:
D1: BZT52C15; D_SOD-123
D2: Vin; LED_1206_3216Metric
D3: 5_STB; LED_1206_3216Metric
D4: 5_Log; LED_1206_3216Metric
D5: +12; LED_1206_3216Metric
D6: -12; LED_1206_3216Metric
D8: 1n400x; D_SMA
D9: Rev_LED; LED_1206_3216Metric
H1, H2, H3, H4: MountingHole; MountingHole_2.2mm_M2
J1: 15V_IN; BarrelJack_Horizontal
J2: 15V_IN; PinHeader_1x02_P2.54mm_Vertical
J3: Edge Connector; 12pos-edge-2.54mm
JP2: 15V_byp; SolderJumper-2_P1.3mm_Open_TrianglePad1.0x1.5mm
Q1: FDS9435A; SOIC-8_3.9x4.9mm_P1.27mm
R7: 100; R_0805_2012Metric
R8, R9, R10, R11, R12: R_0805; R_0805_2012Metric
R21: 1k; R_0805_2012Metric
TP1, TP2, TP3, TP4: TestPoint_Harwin; Harwin-S1751-46-Test-Point

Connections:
/15v_Raw: D8.1 (K), J1.1, J2.1, JP2.1 (A), Q1.5 (D), Q1.6 (D), Q1.7 (D), Q1.8 (D), R8.2
/Analog_En: J3.12; also elsewhere on the board
/Mega_En: J3.11; also elsewhere on the board
/Neg12_Out: J3.1, R12.2; also elsewhere on the board
/Pos12_Out: J3.3, R11.2; also elsewhere on the board
/Vin: D1.1 (K), JP2.2 (B), Q1.1 (S), Q1.2 (S), Q1.3 (S), TP3.1; also elsewhere on the board
/mega_5v: J3.7, R9.2; also elsewhere on the board
/stb_5v: J3.5, R10.2; also elsewhere on the board
GND: D2.1 (K), D3.1 (K), D4.1 (K), D5.1 (K), D6.2 (A), J1.2, J1.3, J2.2, J3.2, J3.4, J3.6, J3.8, R7.1, R21.2, TP1.1, TP2.1, TP4.1; also elsewhere on the board
unnamed: D1.2 (A), Q1.4 (G), R7.2
unnamed: D2.2 (A), R8.1
unnamed: D3.2 (A), R9.1
unnamed: D4.2 (A), R10.1
unnamed: D5.2 (A), R11.1
unnamed: D6.1 (K), R12.1
unnamed: D8.2 (A), D9.1 (K)
unnamed: D9.2 (A), R21.1

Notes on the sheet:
header for each supply solder jumper to bypass 15V

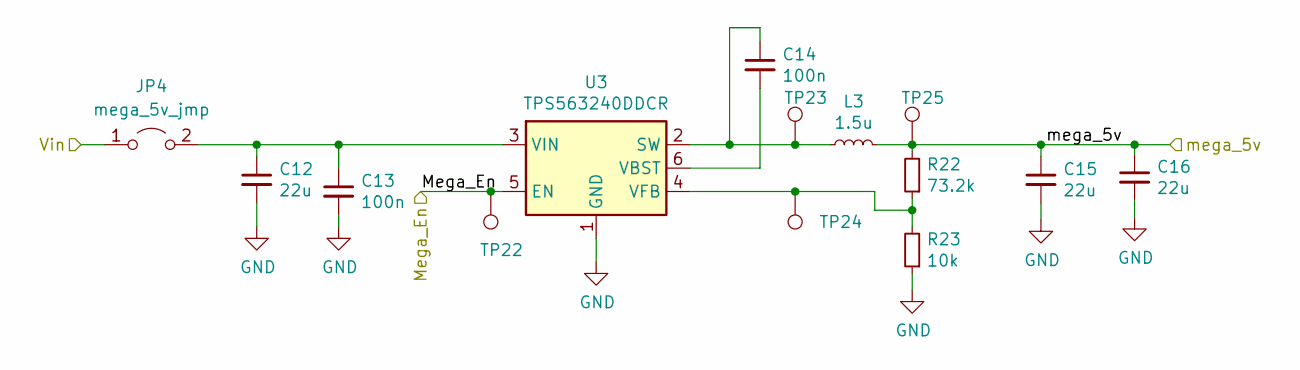
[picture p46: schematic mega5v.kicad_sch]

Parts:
C12, C15, C16: 22u; C_0805_2012Metric
C13, C14: 100n; C_0603_1608Metric
JP4: mega_5v_jmp; SolderJumper-2_P1.3mm_Open_TrianglePad1.0x1.5mm
L3: 1.5u; L_Bourns_SRP5030T
R22: 73.2k; R_0603_1608Metric
R23: 10k; R_0603_1608Metric
TP22, TP23, TP24, TP25: TestPoint_Harwin; Harwin-S1751-46-Test-Point
U3: TPS563240DDCR; SOT-23-6

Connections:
/Mega_En: TP22.1, U3.5 (EN); also elsewhere on the board
/Vin: JP4.1 (A); also elsewhere on the board
/mega_5v: C15.1, C16.1, L3.2, R22.2, TP25.1; also elsewhere on the board
GND: C12.2, C13.2, C15.2, C16.2, R23.1, U3.1 (GND); also elsewhere on the board
unnamed: C12.1, C13.1, JP4.2 (B), U3.3 (VIN)
unnamed: C14.1, L3.1, TP23.1, U3.2 (SW)
unnamed: C14.2, U3.6 (VBST)
unnamed: R22.1, R23.2, TP24.1, U3.4 (VFB)


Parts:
C1: 2.2u; C_0603_1608Metric
C2: 10u; C_0805_2012Metric
C3: 5.6n; C_0603_1608Metric
C4: 100n; C_0603_1608Metric
C5: 22u/16v; C_0805_2012Metric
C9: 1u; C_0805_2012Metric
JP3: neg_12_jmp; SolderJumper-2_P1.3mm_Open_TrianglePad1.0x1.5mm
L1: 68u; L_Taiyo-Yuden_NR-80xx
R1: R; R_0402_1005Metric
R2: 10k; R_0805_2012Metric
R3: 422k; R_0805_2012Metric
R5: 33k; R_0805_2012Metric
TP5, TP6, TP8: TestPoint_Harwin; TestPoint_Pad_1.0x1.0mm
TP7, TP9: TestPoint_Harwin; Harwin-S1751-46-Test-Point
U1: MAX17580; DFN-12-1EP_3x3mm_P0.5mm_EP2.05x2.86mm

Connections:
/Analog_En: R2.1, TP6.1, U1.2 (EN/UVLO); also elsewhere on the board
/Neg12_Out: C1.2, C3.2, C5.2, C9.1, R1.2, R5.2, TP9.1, U1.8 (SOUT), U1.12 (OUT), U1.13 (EP); also elsewhere on the board
/Vin: JP3.1 (A); also elsewhere on the board
/neg12/FB: R3.2, R5.1, TP8.1, U1.7 (FB)
/neg12/neg12_Vin: C2.1, JP3.2 (B), U1.1 (In)
/neg12/~RESET: TP5.1, U1.3 (~RESET)
GND: C2.2, C5.1, C9.2, L1.2, R2.2, R3.1, U1.9 (GND); also elsewhere on the board
unnamed: C1.1, U1.5 (VCC)
unnamed: C3.1, U1.4 (SS)
unnamed: C4.1, U1.10 (BST)
unnamed: C4.2, L1.1, TP7.1, U1.11 (LX)
unnamed: R1.1, U1.6 (RT/SYNC)

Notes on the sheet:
Feedback note Calculated: 421k and 34k (33 + 1) Standardized: 470k and 38k (33 + 4.7)


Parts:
C17, C20, C21: 22u; C_0805_2012Metric
C18, C19: 100n; C_0603_1608Metric
JP5: stb_5v_jmp; SolderJumper-2_P1.3mm_Open_TrianglePad1.0x1.5mm
L4: 1.5u; L_Bourns_SRP5030T
R24: 73.2k; R_0603_1608Metric
R25: 10k; R_0603_1608Metric
TP27, TP28, TP29: TestPoint_Harwin; Harwin-S1751-46-Test-Point
U4: TPS563240DDCR; SOT-23-6

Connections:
/Vin: JP5.1 (A); also elsewhere on the board
/stb_5v: C20.1, C21.1, L4.2, R24.2, TP29.1; also elsewhere on the board
/stb_5v/stb_Vin: C17.1, C18.1, JP5.2 (B), U4.3 (VIN), U4.5 (EN)
GND: C17.2, C18.2, C20.2, C21.2, R25.1, U4.1 (GND); also elsewhere on the board
unnamed: C19.1, L4.1, TP27.1, U4.2 (SW)
unnamed: C19.2, U4.6 (VBST)
unnamed: R24.1, R25.2, TP28.1, U4.4 (VFB)


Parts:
C6: 100u; C_0805_2012Metric
C7, C11: 120u; CP_Radial_D8.0mm_P3.80mm
C8: 470p; C_0603_1608Metric
C10: 10u; C_0805_2012Metric
D7: SS14; D_SMA
JP1: 15V_Jmp; SolderJumper-2_P1.3mm_Open_TrianglePad1.0x1.5mm
L2: 68u; L_Taiyo-Yuden_NR-80xx
Q2: BC817; SOT-23
Q3: MMBT3906; SOT-23
Q4: FDS9435A; SOIC-8_3.9x4.9mm_P1.27mm
R13: 50k; R_0805_2012Metric
R14: 30k; R_0805_2012Metric
R15, R16: .22; R_0805_2012Metric
R17, R20: 0; R_0805_2012Metric
R18: 5.1k; R_0805_2012Metric
R19: 560; R_0805_2012Metric
TP10, TP11, TP13, TP14, TP15, TP17, TP18, TP19, TP20: TestPoint_Harwin; Harwin-S1751-46-Test-Point
U2: mc34063; SOIC-8_3.9x4.9mm_P1.27mm

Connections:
/Analog_En: Q2.1 (B), TP10.1; also elsewhere on the board
/Pos12_Out: C10.2, C11.1, L2.2, R17.1, TP20.1; also elsewhere on the board
/Vin: JP1.1 (A), Q3.2 (E), R13.1, R15.1; also elsewhere on the board
/pos12/15V_SW: C6.1, C7.1, JP1.2 (B), Q4.5 (D), Q4.6 (D), Q4.7 (D), Q4.8 (D), R16.2, TP15.1, U2.6 (VCC)
/pos12/Isense: R16.1, TP17.1, U2.1 (SWC), U2.7 (Isns), U2.8 (DRC)
/pos12/SW: D7.1 (K), L2.1, TP18.1, U2.2 (SWE)
GND: C6.2, C7.2, C8.2, C10.1, C11.2, D7.2 (A), R14.2, R20.1, U2.4 (GND); also elsewhere on the board
unnamed: C8.1, U2.3 (Ct)
unnamed: Q2.2 (E), R14.1, TP11.1
unnamed: Q2.3 (C), Q3.3 (C), Q4.4 (G), R13.2, TP14.1
unnamed: Q3.1 (B), Q4.1 (S), Q4.2 (S), Q4.3 (S), R15.2, TP13.1
unnamed: R17.2, R18.2
unnamed: R18.1, R19.1, TP19.1, U2.5 (Cinv)
unnamed: R19.2, R20.2

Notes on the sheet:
DNP: C6 Whoops. 100u >16V 0805?! What was I thinking!
R13: Use 47K instead R14 use 33K instead



Board: 2 copper layers, 86.9 x 40.1 mm, 126 parts (9 on the bottom side), 43 nets.

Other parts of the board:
kibuzzard-62380C70: G***; kibuzzard-62380C70
kibuzzard-62380CC4: G***; kibuzzard-62380CC4
kibuzzard-62380CD9, kibuzzard-62380CD9#2: G***; kibuzzard-62380CD9
kibuzzard-62380D7E: G***; kibuzzard-62380D7E
kibuzzard-62380DAB: G***; kibuzzard-62380DAB
kibuzzard-62380E7D: G***; kibuzzard-62380E7D
kibuzzard-62380F2D: G***; kibuzzard-62380F2D
kibuzzard-62380F77: G***; kibuzzard-62380F77
kibuzzard-62380FA1: G***; kibuzzard-62380FA1
kibuzzard-62380FF5: G***; kibuzzard-62380FF5
kibuzzard-62388B6B: G***; kibuzzard-62388B6B
kibuzzard-6238101E: G***; kibuzzard-6238101E
kibuzzard-6238106E, kibuzzard-6238106E#2, kibuzzard-6238106E#3, kibuzzard-6238106E#4, kibuzzard-6238106E#5, kibuzzard-6238106E#6, kibuzzard-6238106E#7, kibuzzard-6238106E#8: G***; kibuzzard-6238106E
kibuzzard-62381000: G***; kibuzzard-62381000
kibuzzard-62381032: G***; kibuzzard-62381032
svg2mod: G***; BE10v2

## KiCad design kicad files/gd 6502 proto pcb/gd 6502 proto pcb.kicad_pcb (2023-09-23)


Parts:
C1, C4, C5, C6, C7: 1u; C_0805_2012Metric
C2: 10uF; C_Radial_D6.3mm_H5.0mm_P2.50mm
C3: 10uF; C_0805_2012Metric
D1: PWR; D_1206_3216Metric
H1, H2, H3, H4: MountingHole; MountingHole_2.7mm_M2.5
J1: POWER; PinHeader_2x02_P2.54mm_Vertical
J2, J11: ADDR_BUS; PinHeader_1x11_P2.54mm_Vertical
J3: Main Data; PinHeader_1x11_P2.54mm_Vertical
J4: Bus Signals; PinHeader_1x11_P2.54mm_Vertical
J5: Address; PinHeader_2x10_P2.54mm_Vertical
J6: Data; PinHeader_2x05_P2.54mm_Vertical
J7: ROMDIR_SEL; PinHeader_1x03_P2.54mm_Vertical
J8: ROMG_SEL; PinHeader_1x03_P2.54mm_Vertical
J9: CLK_ALT; PinHeader_1x02_P2.54mm_Vertical
J10: NOR-Extra; PinHeader_1x07_P2.54mm_Vertical
J12: ROMEN; PinHeader_1x02_P2.54mm_Vertical
JP1: BE_VDD; SolderJumper-2_P1.3mm_Bridged_Pad1.0x1.5mm
JP2: X5; SolderJumper-2_P1.3mm_Bridged_Pad1.0x1.5mm
JP3: X4; SolderJumper-2_P1.3mm_Open_RoundedPad1.0x1.5mm
R1, R2, R3: 3k3; R_0805_2012Metric
R4: 1K; R_0805_2012Metric
RN1, RN2, RN3, RN4: 0; R_Array_Convex_4x0612
RNP1: 3k3; R_0805_2012Metric
U1: 27C512; DIP-28_W15.24mm_Socket_LongPads
U2: w65c02s-QFP; PQFP-44_10x10mm_P0.8mm
U3: 74HCT02; SOIC-14_3.9x8.7mm_P1.27mm
U4, U5: 74HCT245; SOIC-20W_7.5x12.8mm_P1.27mm

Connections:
+5V: C1.1, C2.1, C3.1, C4.1, C5.1, C6.1, C7.1, J1.1, J1.3, J2.3, J7.3, J8.3, JP1.1 (A), R1.1, R2.1, R3.1, R4.1, RNP1.1, U1.1 (A15), U1.27 (A14), U1.28 (VCC), U2.3 (VDD), U2.31 (VDD), U3.14 (VCC), U4.20 (+V), U5.20 (+V)
/3A: J10.7, U3.8
/3B: J10.6, U3.9
/3Y: J10.5, U3.10
/4A: J10.4, U3.11
/4B: J10.3, U3.12
/4Y: J10.2, U3.13
/A0: J2.4, J5.1, RN1.8 (R1.2), U2.4 (A0), U4.9 (A8)
/A1: J2.5, J5.2, RN1.7 (R2.2), U2.5 (A1), U4.8 (A7)
/A2: J2.6, J5.3, RN1.6 (R3.2), U2.7 (A2), U4.7 (A6)
/A3: J2.7, J5.6, RN1.5 (R4.2), U2.8 (A3), U4.6 (A5)
/A4: J2.9, J5.5, RN2.8 (R1.2), U2.9 (A4), U4.5 (A4)
/A5: J2.10, J5.8, RN2.7 (R2.2), U2.10 (A5), U4.4 (A3)
/A6: J2.11, J5.9, RN2.6 (R3.2), U2.11 (A6), U4.3 (A2)
/A7: J5.10, J11.1, RN2.5 (R4.2), U2.12 (A7), U4.2 (A1)
/A8: J5.11, J11.2, RN3.8 (R1.2), U2.13 (A8), U5.9 (A8)
/A9: J5.14, J11.3, RN3.7 (R2.2), U2.14 (A9), U5.8 (A7)
/A10: J5.13, J11.5, RN3.6 (R3.2), U2.15 (A10), U5.7 (A6)
/A11: J5.16, J11.6, RN3.5 (R4.2), U2.16 (A11), U5.6 (A5)
/A12: J5.17, J11.7, RN4.8 (R1.2), U2.19 (A12), U5.5 (A4)
/A13: J5.18, J11.9, RN4.7 (R2.2), U2.20 (A13), U5.4 (A3)
/A14: J5.19, J11.10, U2.21 (A14)
/A15: J5.20, J11.11, U2.22 (A15)
/BA0: RN1.1 (R1.1), U1.10 (A0), U4.11 (B8)
/BA1: RN1.2 (R2.1), U1.9 (A1), U4.12 (B7)
/BA2: RN1.3 (R3.1), U1.8 (A2), U4.13 (B6)
/BA3: RN1.4 (R4.1), U1.7 (A3), U4.14 (B5)
/BA4: RN2.1 (R1.1), U1.6 (A4), U4.15 (B4)
/BA5: RN2.2 (R2.1), U1.5 (A5), U4.16 (B3)
/BA6: RN2.3 (R3.1), U1.4 (A6), U4.17 (B2)
/BA7: RN2.4 (R4.1), U1.3 (A7), U4.18 (B1)
/BA8: RN3.1 (R1.1), U1.25 (A8), U5.11 (B8)
/BA9: RN3.2 (R2.1), U1.24 (A9), U5.12 (B7)
/BA10: RN3.3 (R3.1), U1.21 (A10), U5.13 (B6)
/BA11: RN3.4 (R4.1), U1.23 (A11), U5.14 (B5)
/BA12: RN4.1 (R1.1), U1.2 (A12), U5.15 (B4)
/BA13: RN4.2 (R2.1), U1.26 (A13), U5.16 (B3)
/D0: J3.10, J6.1, U1.11 (D0), U2.30 (D0)
/D1: J3.9, J6.2, U1.12 (D1), U2.29 (D1)
/D2: J3.7, J6.3, U1.13 (D2), U2.28 (D2)
/D3: J3.6, J6.4, U1.15 (D3), U2.27 (D3)
/D4: J3.5, J6.7, U1.16 (D4), U2.26 (D4)
/D5: J3.3, J6.6, U1.17 (D5), U2.25 (D5)
/D6: J3.2, J6.9, U1.18 (D6), U2.24 (D6)
/D7: J3.1, J6.10, U1.19 (D7), U2.23 (D7)
/DMA: J9.1, JP2.2 (B), U3.1
/MLB: J4.1, U2.44 (MLB)
/PH0: J4.11, U2.35 (PHI2)
/PH0_ALT: J9.2, U3.4
/PH1: J10.1, U3.6
/PHI1O: J4.3, U2.42 (PHI1O)
/PHI2O: J4.9, U2.37 (PHI2O)
/RDY: J4.5, R1.2, U2.41 (RDY)
/ROMDIR: J7.2, U4.1 (DIR), U5.1 (DIR)
/ROMG: J8.2, U4.19 (G), U5.19 (G)
/RWB: J3.11, U2.32 (RWB)
/SOB: J4.10, U2.36 (SOB)
/VPB: J4.6, U2.40 (VPB)
/~DMA: RNP1.2, U3.2
/~IRQ: J4.2, R3.2, U2.43 (IRQB)
/~NMI: J2.1, R2.2, U2.1 (NMIB)
/~RCMEN: J12.1, U1.22 (~OE)
/~RES: J4.7, U2.38 (RESB)
/~SYNC: J2.2, U2.2 (SYNC)
GND: C1.2, C2.2, C3.2, C4.2, C5.2, C6.2, C7.2, D1.1 (K), J1.2, J1.4, J2.8, J3.4, J3.8, J4.4, J4.8, J5.4, J5.7, J5.12, J5.15, J6.5, J6.8, J7.1, J8.1, J11.4, J11.8, J12.2, JP3.2 (B), U1.14 (GND), U1.20 (~CE), U2.17 (VSS), U2.18 (VSS), U2.39 (VSS), U3.3, U3.7 (GND), U4.10 (GND), U5.10 (GND)
unnamed: D1.2 (A), R4.2
unnamed: JP1.2 (B), U2.34 (BE)
unnamed: JP2.1 (A), JP3.1 (A), U3.5

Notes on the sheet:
INPUTS BE - Bus Enable SOB - Set Overflow
OUTPUTS VPB - Vector Pull MLB - Memory Lock



Board: 4 copper layers, 90.4 x 52.2 mm, 42 parts (9 on the bottom side), 68 nets.

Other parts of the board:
He: MountingHole; MountingHole_2.7mm_M2.5
svg2mod: G***; BE5v2

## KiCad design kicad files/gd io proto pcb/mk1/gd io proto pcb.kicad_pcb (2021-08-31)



Board: 2 copper layers, 94.8 x 64.6 mm, 37 parts (3 on the bottom side), 96 nets.

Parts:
C1, C2, C5, C6, C7: 10u; C_0805_2012Metric
C3: 1uF; C_0805_2012Metric
C4: 10uF; C_0805_2012Metric
D2: 5v; LED_1206_3216Metric
D4: -5v; LED_1206_3216Metric
D5: +12v; LED_1206_3216Metric
D7: -12v; LED_1206_3216Metric
J1: Pwr; PinHeader_2x04_P2.54mm_Horizontal
J2: CTRL2; PinHeader_2x05_P2.54mm_Horizontal
J3: Add_Main_Data; PinHeader_2x16_P2.54mm_Horizontal
J4: CTRL1; PinHeader_2x05_P2.54mm_Horizontal
J5: SData LA; PinSocket_2x05_P2.54mm_Vertical
J6: INT6; PinHeader_1x02_P2.54mm_Vertical-LOCK
J7: IOSEL LA; PinSocket_2x05_P2.54mm_Vertical
J8, J9: Buffered LA; PinSocket_2x04_P2.54mm_Vertical
J10: DEV LA; PinSocket_2x05_P2.54mm_Vertical
J11: Annunciate; PinHeader_1x05_P2.54mm_Vertical-LOCK
J12: Apple_II_Slot; Amp_2358256-4_50pos_right_angle_card
J13: Slot Maker; PinSocket_2x05_P2.54mm_Vertical
J14: Slot Maker LA; PinSocket_2x05_P2.54mm_Vertical
J15: Slot-Only Sigs; PinSocket_2x07_P2.54mm_Vertical
J16: IO Selector; PinSocket_2x08_P2.54mm_Vertical
J17: -5V; PinHeader_1x02_P2.54mm_Vertical-LOCK
J18: IOSEL; PinHeader_1x01_P2.54mm_Vertical
R2, R4, R5, R7: 1K; R_0805_2012Metric
U1: Slotmaker; PLCC-44_THT-Socket
U2: 74HCT245-CHECK FOOTPRINT; SO-20_12.8x7.5mm_P1.27mm
U3: LM7905_TO220; TO-220-3_Vertical
svg2mod: G***; BE5v2

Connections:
+5V: C3.1, C4.1, C6.1, J1.3, J1.4, J12.25, R2.1, U1.18, U2.20
+12V: C1.1, J1.5, J1.6, J12.50, R5.1
-5V: C5.1, D4.1, J12.34, J17.1, U3.3
-12V: C2.1, C7.1, D7.1, J1.7, J1.8, J12.33, U3.2
/7M: J4.2, U1.4
/AN0: J11.2, U1.14
/AN1: J11.3, U1.15
/AN2: J11.4, U1.16
/AN3: J11.5, U1.17
/B7M: J8.1, J12.36, U1.19
/BA0: J3.4, J12.2
/BA1: J3.3, J12.3
/BA2: J3.6, J12.4
/BA3: J3.5, J12.5
/BA4: J3.8, J12.6
/BA5: J3.7, J12.7
/BA6: J3.10, J12.8
/BA7: J3.9, J12.9
/BA8: J3.14, J12.10
/BA9: J3.13, J12.11
/BA10: J3.16, J12.12
/BA11: J3.15, J12.13
/BA12: J3.18, J12.14
/BA13: J3.17, J12.15
/BA14: J3.20, J12.16
/BA15: J3.19, J12.17
/BPH0: J8.3, J12.40, U1.22
/BPH1: J8.4, J12.38, U1.23
/BQ3: J8.2, J12.37, U1.21
/DMA1a: J12.27, J15.1, J15.2
/DMA1b: J12.24, J15.9, J15.10
/INTa: J12.28, J15.3, J15.4
/INTb: J12.23, J15.5, J15.6
/KSEL0: J2.4, U1.5
/M2BADD_(NC): J12.35, J15.11, J15.12
/MD0: J3.24, U2.18
/MD1: J3.23, U2.17
/MD2: J3.26, U2.16
/MD3: J3.25, U2.15
/MD4: J3.28, U2.14
/MD5: J3.27, U2.13
/MD6: J3.30, U2.12
/MD7: J3.29, U2.11
/MDIN-OUT: J13.7, J14.7, U2.1
/PH0: J4.8, U1.1
/Q3: J4.6, U1.3
/RW: J4.5, J12.18, U1.44
/SBUS0: J13.2, J14.2, U1.6
/SBUS1: J13.1, J14.1, U1.7
/SBUS2: J13.4, J14.4, U1.8
/SBUS3: J13.3, J14.3, U1.9
/SBUS4: J13.6, J14.6, U1.10
/SBUS5: J13.5, J14.5, U1.11
/SDBUS0: J5.1, J12.49, U2.2
/SDBUS1: J5.2, J12.48, U2.3
/SDBUS2: J5.3, J12.47, U2.4
/SDBUS3: J5.4, J12.46, U2.5
/SDBUS4: J5.5, J12.45, U2.6
/SDBUS5: J5.6, J12.44, U2.7
/SDBUS6: J5.7, J12.43, U2.8
/SDBUS7: J5.8, J12.42, U2.9
/UPSYNC?: J12.39, J15.13, J15.14
/~C038: J11.1, U1.13
/~DEV1: J10.7, J12.41, U1.26
/~DEV2: J10.6, U1.27
/~DEV3: J10.5, U1.28
/~DEV4: J10.3, U1.29
/~DEV5: J10.4, U1.30
/~DEV6: J10.2, U1.31
/~DEV7: J10.1, U1.32
/~DMA: J2.5, J12.22
/~EN245: J8.5, U1.24
/~INH: J4.7, J12.32
/~INTDEV1: J9.1, U1.40
/~INTDEV2: J9.2, U1.41
/~INTDEV5: J9.3, U1.42
/~INTDEV6: J6.1, J6.2, J9.4, J13.8, J14.8, U1.12
/~INTDEV7: J9.5, U1.43
/~IOSEL: J12.1, J18.1
/~IOSEL1: J7.1, J16.15, J16.16, U1.33
/~IOSEL2: J7.2, J16.13, J16.14, U1.34
/~IOSEL3: J7.3, J16.11, J16.12, U1.35
/~IOSEL4: J7.4, J16.7, J16.8, U1.36
/~IOSEL5: J7.5, J16.5, J16.6, U1.37
/~IOSEL6: J7.6, J16.3, J16.4, U1.38
/~IOSEL7: J7.7, J16.1, J16.2, U1.39
/~IOSTRB: J8.6, J12.20, U1.25
/~IRQ: J4.1, J12.30
/~NMI: J2.3, J12.29
/~RDY: J2.1, J12.21
/~RESET: J4.3, J12.31, U1.2
GND: C1.2, C2.2, C3.2, C4.2, C5.2, C6.2, C7.2, D2.1, D5.1, J1.1, J1.2, J2.9, J2.10, J3.1, J3.2, J3.11, J3.12, J3.21, J3.22, J3.31, J3.32, J4.9, J4.10, J5.9, J5.10, J7.8, J7.9, J7.10, J8.7, J8.8, J9.6, J9.7, J9.8, J10.8, J10.9, J10.10, J12.26, J13.9, J13.10, J14.9, J14.10, J15.7, J15.8, J16.9, J16.10, J17.2, R4.2, R7.2, U1.20, U2.10, U3.1
unnamed: D2.2, R2.2
unnamed: D4.2, R4.1
unnamed: D5.2, R5.2
unnamed: D7.2, R7.1

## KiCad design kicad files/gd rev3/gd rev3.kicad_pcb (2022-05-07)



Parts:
C1, C2, C3, C7, C8, C9, C10, C11, C54, C63, C75: 1uF; C_0805_2012Metric
C4: 10uF; C_0805_2012Metric
C5: 100u; CP_EIA-3216-18_Kemet-A; MPN T520A107M006ATE035
D1: ~{ROMEN_L}; LED_1206_3216Metric
H1, H2, H3, H4: MountingHole; MountingHole_2.5mm
J1: XY; PinHeader_2x02_P2.54mm_Vertical
Q1: BC817; SOT-23
R1: 4k7; R_0603_1608Metric
R2, R3: 3k3; R_0603_1608Metric
R4, R5, R6, R7: 4k7; R_0805_2012Metric
R47: 470; R_0805_2012Metric
RN1, RN2, RN3: 100; R_Array_Convex_4x0612
SW1: MEGA RESET; SW_SPST_PTS810
TP2: TestPoint_Harwin; TestPoint_Pad_D1.0mm
TP3, TP10, TP11, TP12, TP13, TP14, TP15, TP18, TP19, TP20, TP21, TP25, TP26, TP27: TestPoint; TestPoint_Pad_D1.0mm
U1: Apple_MEGA_II; PLCC-84_THT-Socket
U2: w65c02s; TQFP-44_10x10mm_P0.8mm
U3: 74LVC1G02; SOT-23-5
U4, U5: 74HCT245; SOIC-20W_7.5x12.8mm_P1.27mm
U6: 28C256; PLCC-32_11.4x14.0mm_P1.27mm
U7, U8, U9, U10: DRAM64KX4; DIP-18_W7.62mm_Socket_LongPads
U35: 74LVC2G04; SOT-23-6
X1: 14.31818MHz; Oscillator_SMD_EuroQuartz_XO91-4Pin_7.0x5.0mm; MPN MCSJK-6NC1-14.31818-25-B

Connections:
/Audio/SPKR: U1.12 (SPKR); also elsewhere on the board
/IWM/7M: U1.78 (7M); also elsewhere on the board
/IWM/BA0: U1.66 (A0), U4.11 (B8), U6.10 (A0); also elsewhere on the board
/IWM/BA1: U1.65 (A1), U4.12 (B7), U6.9 (A1); also elsewhere on the board
/IWM/BA2: U1.64 (A2), U4.13 (B6), U6.8 (A2); also elsewhere on the board
/IWM/BA3: U1.63 (A3), U4.14 (B5), U6.7 (A3); also elsewhere on the board
/IWM/BA4: U1.62 (A4), U4.15 (B4), U6.6 (A4); also elsewhere on the board
/IWM/BA5: U1.61 (A5), U4.16 (B3), U6.5 (A5); also elsewhere on the board
/IWM/BA6: U1.60 (A6), U4.17 (B2), U6.4 (A6); also elsewhere on the board
/IWM/BA7: U1.59 (A7), U4.18 (B1), U6.3 (A7); also elsewhere on the board
/IWM/BA8: U1.58 (A8), U5.11 (B8), U6.25 (A8); also elsewhere on the board
/IWM/BA9: U1.57 (A9), U5.12 (B7), U6.24 (A9); also elsewhere on the board
/IWM/BA10: U1.56 (A10), U5.13 (B6), U6.21 (A10); also elsewhere on the board
/IWM/BA11: U1.55 (A11), U5.14 (B5), U6.23 (A11); also elsewhere on the board
/IWM/BA12: U1.54 (A12), U5.15 (B4), U6.2 (A12); also elsewhere on the board
/IWM/BA13: U1.53 (A13), U5.16 (B3), U6.26 (A13); also elsewhere on the board
/IWM/BA14: U1.52 (A14), U5.17 (B2); also elsewhere on the board
/IWM/BA15: U1.51 (A15), U5.18 (B1); also elsewhere on the board
/IWM/MD0: U1.9 (MD0), U2.30 (D0), U6.11 (D0), U8.2 (IQ0); also elsewhere on the board
/IWM/MD1: U1.8 (MD1), U2.29 (D1), U6.12 (D1), U8.3 (IQ1); also elsewhere on the board
/IWM/MD2: U1.7 (MD2), U2.28 (D2), U6.13 (D2), U8.15 (IQ2); also elsewhere on the board
/IWM/MD3: U1.6 (MD3), U2.27 (D3), U6.15 (D3), U8.17 (IQ3); also elsewhere on the board
/IWM/MD4: U1.5 (MD4), U2.26 (D4), U6.16 (D4), U7.2 (IQ0); also elsewhere on the board
/IWM/MD5: U1.4 (MD5), U2.25 (D5), U6.17 (D5), U7.3 (IQ1); also elsewhere on the board
/IWM/MD6: U1.3 (MD6), U2.24 (D6), U6.18 (D6), U7.15 (IQ2); also elsewhere on the board
/IWM/MD7: U1.2 (MD7), U2.23 (D7), U6.19 (D7), U7.17 (IQ3); also elsewhere on the board
/IWM/Q3: U1.80 (Q3); also elsewhere on the board
/IWM/~RESET: R4.2, SW1.2, TP25.1, U1.35 (~RESET), U2.38 (RESB); also elsewhere on the board
/Slot/MDI-MDO: U1.36 (MDIN/OUT); also elsewhere on the board
/Slot/PH0: TP20.1, U1.81 (PH#), U2.35 (PHI2); also elsewhere on the board
/Slot/Q3: U1.79 (CREF); also elsewhere on the board
/Slot/RW: U1.41 (R/W), U2.32 (RWB); also elsewhere on the board
/Slot/S0: U1.42 (S0); also elsewhere on the board
/Slot/S1: U1.43 (S1); also elsewhere on the board
/Slot/S2: U1.44 (S2); also elsewhere on the board
/Slot/S3: U1.45 (S3); also elsewhere on the board
/Slot/S4: U1.46 (S4); also elsewhere on the board
/Slot/S5: U1.47 (S5); also elsewhere on the board
/Slot/~DMA: TP26.1, U1.38 (~DMA), U3.1; also elsewhere on the board
/Slot/~INH: U1.40 (~INH); also elsewhere on the board
/Slot/~IRQ: R1.2, U1.15 (~IRQ), U2.43 (IRQB); also elsewhere on the board
/Slot/~NMI: R2.2, U2.1 (NMIB); also elsewhere on the board
/Slot/~RDY: R3.2, U2.41 (RDY); also elsewhere on the board
/game_port/~C060-67: U1.11 (~C060-67); also elsewhere on the board
/game_port/~PDLTRIG: U1.10 (~PDLTRIG); also elsewhere on the board
/mega-6502/14M: TP21.1, U1.76 (14M), U35.4; also elsewhere on the board
/mega-6502/14M_Prime: U35.1, X1.3 (OUT)
/mega-6502/A0: U2.4 (A0), U4.9 (A8)
/mega-6502/A1: U2.5 (A1), U4.8 (A7)
/mega-6502/A2: U2.7 (A2), U4.7 (A6)
/mega-6502/A3: U2.8 (A3), U4.6 (A5)
/mega-6502/A4: U2.9 (A4), U4.5 (A4)
/mega-6502/A5: U2.10 (A5), U4.4 (A3)
/mega-6502/A6: U2.11 (A6), U4.3 (A2)
/mega-6502/A7: U2.12 (A7), U4.2 (A1)
/mega-6502/A8: U2.13 (A8), U5.9 (A8)
/mega-6502/A9: U2.14 (A9), U5.8 (A7)
/mega-6502/A10: U2.15 (A10), U5.7 (A6)
/mega-6502/A11: U2.16 (A11), U5.6 (A5)
/mega-6502/A12: U2.19 (A12), U5.5 (A4)
/mega-6502/A13: U2.20 (A13), U5.4 (A3)
/mega-6502/A14: U2.21 (A14), U5.3 (A2)
/mega-6502/A15: U2.22 (A15), U5.2 (A1)
/mega-6502/AD0: U1.22 (AD0), U10.2 (IQ0)
/mega-6502/AD1: U1.23 (AD1), U10.3 (IQ1)
/mega-6502/AD2: U1.24 (AD2), U10.15 (IQ2)
/mega-6502/AD3: U1.25 (AD3), U10.17 (IQ3)
/mega-6502/AD4: U1.26 (AD4), U9.2 (IQ0)
/mega-6502/AD5: U1.27 (AD5), U9.3 (IQ1)
/mega-6502/AD6: U1.28 (AD6), U9.15 (IQ2)
/mega-6502/AD7: U1.29 (AD7), U9.17 (IQ3)
/mega-6502/DMA: TP27.1, U3.4, U4.19 (G), U5.19 (G)
/mega-6502/RA0: RN2.2 (R2.1), U1.74 (RA0)
/mega-6502/RA1: RN2.1 (R1.1), U1.73 (RA1)
/mega-6502/RA2: RN2.3 (R3.1), U1.72 (RA2)
/mega-6502/RA3: RN2.4 (R4.1), U1.71 (RA3)
/mega-6502/RA4: RN3.1 (R1.1), U1.70 (RA4)
/mega-6502/RA5: RN3.2 (R2.1), U1.69 (RA5)
/mega-6502/RA6: RN3.3 (R3.1), U1.68 (RA6)
/mega-6502/RA7: RN3.4 (R4.1), U1.67 (RA7)
/mega-6502/RAF0: RN2.7 (R2.2), U7.6 (A0), U8.6 (A0), U9.6 (A0), U10.6 (A0)
/mega-6502/RAF1: RN2.8 (R1.2), U7.8 (A1), U8.8 (A1), U9.8 (A1), U10.8 (A1)
/mega-6502/RAF2: RN2.6 (R3.2), U7.7 (A2), U8.7 (A2), U9.7 (A2), U10.7 (A2)
/mega-6502/RAF3: RN2.5 (R4.2), U7.13 (A3), U8.13 (A3), U9.13 (A3), U10.13 (A3)
/mega-6502/RAF4: RN3.8 (R1.2), U7.12 (A4), U8.12 (A4), U9.12 (A4), U10.12 (A4)
/mega-6502/RAF5: RN3.7 (R2.2), U7.11 (A5), U8.11 (A5), U9.11 (A5), U10.11 (A5)
/mega-6502/RAF6: RN3.6 (R3.2), U7.14 (A6), U8.14 (A6), U9.14 (A6), U10.14 (A6)
/mega-6502/RAF7: RN3.5 (R4.2), U7.10 (A7), U8.10 (A7), U9.10 (A7), U10.10 (A7)
/mega-6502/RGB1: U1.34 (RGB1); also elsewhere on the board
/mega-6502/RGB2: U1.32 (RGB2); also elsewhere on the board
/mega-6502/RGB4: U1.31 (RGB4); also elsewhere on the board
/mega-6502/RGB8: U1.30 (RGB8); also elsewhere on the board
/mega-6502/RMBK: TP3.1, U1.48 (RMBK/BA0)
/mega-6502/SERVID: TP18.1, U1.21 (SERVIDEO); also elsewhere on the board
/mega-6502/SYNC_6502: U2.2 (SYNC)
/mega-6502/X0: J1.1, TP12.1, U1.16 (X0)
/mega-6502/X1: J1.2, TP13.1, U1.17 (X1)
/mega-6502/Y0: J1.3, TP14.1, U1.18 (Y0)
/mega-6502/Y1: J1.4, TP15.1, U1.19 (Y1)
/mega-6502/~CASA.B: RN1.8 (R1.2), U9.16 (~CAS), U10.16 (~CAS)
/mega-6502/~CASA: RN1.1 (R1.1), U1.82 (~CASA)
/mega-6502/~CASM.B: RN1.6 (R3.2), U7.16 (~CAS), U8.16 (~CAS)
/mega-6502/~CASM: RN1.3 (R3.1), U1.83 (~CASM)
/mega-6502/~KSEL1: TP11.1, U1.13 (~KSEL1); also elsewhere on the board
/mega-6502/~KSEL2: TP10.1, U1.14 (~KSEL2); also elsewhere on the board
/mega-6502/~M2SEL: R6.1, U1.39 (~M2SEL)
/mega-6502/~MSW: R5.2, U1.20 (~MSW)
/mega-6502/~RAMWE: RN1.2 (R2.1), U1.1 (~RAMWE)
/mega-6502/~RAS.B: RN1.5 (R4.2), U7.5 (~RAS), U8.5 (~RAS), U9.5 (~RAS), U10.5 (~RAS)
/mega-6502/~RAS: RN1.4 (R4.1), U1.84 (~RAS)
/mega-6502/~ROMEN: R7.2, TP2.1, U1.37 (~ROMEN), U6.22 (~OE)
/mega-6502/~RWE.B: RN1.7 (R2.2), U7.4 (R/~W), U8.4 (R/~W), U9.4 (R/~W), U10.4 (R/~W)
/mega-6502/~SYNC: TP19.1, U1.50 (~SYNC); also elsewhere on the board
/mega-6502/~WINDOW: U1.49 (~WINDOW); also elsewhere on the board
GND: C1.2, C2.2, C3.2, C4.2, C5.2, C7.2, C8.2, C9.2, C10.2, C11.2, C54.2, C63.2, C75.2, Q1.2 (E), R6.2, SW1.1, U1.33 (GND), U1.75 (GND), U2.17 (VSS), U2.18 (VSS), U2.39 (VSS), U3.2, U3.3 (GND), U4.10 (GND), U5.10 (GND), U6.1 (A14), U6.14 (GND), U6.27 (~WE), U7.1 (~OE), U7.18 (VSS), U8.1 (~OE), U8.18 (VSS), U9.1 (~OE), U9.18 (VSS), U10.1 (~OE), U10.18 (VSS), U35.2 (GND), X1.2 (GND); also elsewhere on the board
unnamed: D1.1 (K), R47.1
unnamed: Q1.1 (B), R7.1
unnamed: Q1.3 (C), R47.2
unnamed: U35.3, U35.6

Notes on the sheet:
Apple IIe uses HCT244s for these buffers. (Using 245s because we have them already)
This might not be the right ROM symbol. PCB is complaining
Notes: * Test if MEGA inhibits PH0 when /DMA is asserted.

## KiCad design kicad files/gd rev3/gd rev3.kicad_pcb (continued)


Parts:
C16, C55: 1uF; C_0805_2012Metric
C17, C18, C19, C56: 10u; C_0805_2012Metric
C78, C79: 1u; C_0603_1608Metric
J9: IO-Xtra; PinHeader_1x03_P2.54mm_Vertical
J10: Apple_II_Slot; Amp_2358256-4_50pos_right_angle_card
SW2: DEV; SW_DIP_SPSTx08_Slide_Omron_A6H-8101_W6.15mm_P1.27mm
SW3: IOSEL; SW_DIP_SPSTx08_Slide_Omron_A6H-8101_W6.15mm_P1.27mm
TP4, TP5, TP6, TP7, TP8, TP9, TP16, TP17: TestPoint; TestPoint_Pad_D1.0mm
U12: Slotmaker; PLCC-44_THT-Socket
U13: 74HCT245; SOIC-20W_7.5x12.8mm_P1.27mm
U32: LM7905_TO220; TO-220-3_Vertical

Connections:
+12V: C17.1, J10.50; also elsewhere on the board
-5V: C56.1, C79.1, J10.34, U32.3 (VO)
-12V: C19.1, C78.1, J10.33, U32.2 (VI); also elsewhere on the board
/IWM/7M: U12.4 (7M); also elsewhere on the board
/IWM/BA0: J10.2; also elsewhere on the board
/IWM/BA1: J10.3; also elsewhere on the board
/IWM/BA2: J10.4; also elsewhere on the board
/IWM/BA3: J10.5; also elsewhere on the board
/IWM/BA4: J10.6; also elsewhere on the board
/IWM/BA5: J10.7; also elsewhere on the board
/IWM/BA6: J10.8; also elsewhere on the board
/IWM/BA7: J10.9; also elsewhere on the board
/IWM/BA8: J10.10; also elsewhere on the board
/IWM/BA9: J10.11; also elsewhere on the board
/IWM/BA10: J10.12; also elsewhere on the board
/IWM/BA11: J10.13; also elsewhere on the board
/IWM/BA12: J10.14; also elsewhere on the board
/IWM/BA13: J10.15; also elsewhere on the board
/IWM/BA14: J10.16; also elsewhere on the board
/IWM/BA15: J10.17; also elsewhere on the board
/IWM/MD0: U13.18 (B1); also elsewhere on the board
/IWM/MD1: U13.17 (B2); also elsewhere on the board
/IWM/MD2: U13.16 (B3); also elsewhere on the board
/IWM/MD3: U13.15 (B4); also elsewhere on the board
/IWM/MD4: U13.14 (B5); also elsewhere on the board
/IWM/MD5: U13.13 (B6); also elsewhere on the board
/IWM/MD6: U13.12 (B7); also elsewhere on the board
/IWM/MD7: U13.11 (B8); also elsewhere on the board
/IWM/~INTDEV6: U12.12 (~INTDEV6); also elsewhere on the board
/IWM/~RESET: J10.31, U12.2 (~RESET); also elsewhere on the board
/Slot/AN0: U12.14 (AN0); also elsewhere on the board
/Slot/AN1: U12.15 (AN1); also elsewhere on the board
/Slot/AN2: U12.16 (AN2); also elsewhere on the board
/Slot/AN3: U12.17 (AN3); also elsewhere on the board
/Slot/B7M: J10.36, U12.19 (B7M)
/Slot/BPH0: J10.40, U12.22 (BPH0)
/Slot/BPH1: J10.38, U12.23 (BPH1)
/Slot/BQ3: J10.37, U12.21 (BQ3)
/Slot/DMA1a: J10.27, TP4.1
/Slot/DMA1b: J10.24, TP7.1
/Slot/INTa: J10.28, TP5.1
/Slot/INTb: J10.23, TP6.1
/Slot/M2BADD_(NC): J10.35, TP8.1
/Slot/MDI-MDO: U13.1 (DIR); also elsewhere on the board
/Slot/PH0: U12.1 (PH0); also elsewhere on the board
/Slot/Q3: U12.3 (Q3); also elsewhere on the board
/Slot/RW: J10.18, U12.44 (R/W); also elsewhere on the board
/Slot/S0: U12.11 (S0); also elsewhere on the board
/Slot/S1: U12.10 (S1); also elsewhere on the board
/Slot/S2: U12.9 (S2); also elsewhere on the board
/Slot/S3: U12.8 (S3); also elsewhere on the board
/Slot/S4: U12.7 (S4); also elsewhere on the board
/Slot/S5: U12.6 (S5); also elsewhere on the board
/Slot/SDBUS0: J10.49, U13.2 (A1)
/Slot/SDBUS1: J10.48, U13.3 (A2)
/Slot/SDBUS2: J10.47, U13.4 (A3)
/Slot/SDBUS3: J10.46, U13.5 (A4)
/Slot/SDBUS4: J10.45, U13.6 (A5)
/Slot/SDBUS5: J10.44, U13.7 (A6)
/Slot/SDBUS6: J10.43, U13.8 (A7)
/Slot/SDBUS7: J10.42, U13.9 (A8)
/Slot/SYNC_6502: J10.39, TP9.1
/Slot/~C038: TP16.1, U12.13 (~C038-3F)
/Slot/~DEV1: SW2.7, U12.26 (~DEV1)
/Slot/~DEV2: SW2.6, U12.27 (~DEV2)
/Slot/~DEV3: SW2.5, U12.28 (~DEV3)
/Slot/~DEV4: SW2.4, U12.29 (~DEV4)
/Slot/~DEV5: SW2.3, U12.30 (~DEV5)
/Slot/~DEV6: SW2.2, U12.31 (~DEV6)
/Slot/~DEV7: SW2.1, U12.32 (~DEV7)
/Slot/~DEVx: J9.1, SW2.8
/Slot/~DEV: J10.41, SW2.9, SW2.10, SW2.11, SW2.12, SW2.13, SW2.14, SW2.15, SW2.16
/Slot/~DMA: J10.22; also elsewhere on the board
/Slot/~EN245: U12.24 (~EN245), U13.19 (G)
/Slot/~INH: J10.32; also elsewhere on the board
/Slot/~INTDEV1: U12.40 (~INTDEV1)
/Slot/~INTDEV2: U12.41 (~INTDEV2)
/Slot/~INTDEV5: U12.42 (~INTDEV5)
/Slot/~INTDEV7: U12.43 (~INTDEV7)
/Slot/~IOSELx: J9.3, SW3.8
/Slot/~IOSEL: J10.1, SW3.9, SW3.10, SW3.11, SW3.12, SW3.13, SW3.14, SW3.15, SW3.16
/Slot/~IOSTRB: J10.20, U12.25 (~IOSTRB)
/Slot/~IRQ: J10.30; also elsewhere on the board
/Slot/~NMI: J10.29; also elsewhere on the board
/Slot/~RDY: J10.21; also elsewhere on the board
/mega-6502/~KSEL0: TP17.1, U12.5 (~KSEL0); also elsewhere on the board
GND: C16.2, C17.2, C18.2, C19.2, C55.2, C56.2, C78.2, C79.2, J9.2, J10.26, U12.20 (GND), U13.10 (GND), U32.1 (GND); also elsewhere on the board

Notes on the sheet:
C038-C03F is for IIgs SCC (Sound)
~{}


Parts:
C35: 100u; CP_EIA-3216-18_Kemet-A; MPN T520A107M006ATE035
C36, C37, C44, C51, C65, C69: 1u; C_0805_2012Metric
C38, C39: 27p; C_0603_1608Metric
C40: 100n; C_0805_2012Metric
C41, C42, C45, C48, C49, C50, C66, C67, C68: 100n; C_0603_1608Metric
C43, C46: 1u; C_0603_1608Metric
D11: D_1206; LED_1206_3216Metric
J17: VGA_Micro; USB_Micro-B_GCT_USB3076-30-A
J18: vga_SWD; SAMTEC_FTSH-105-XX-X-DV; PARTREV H
J22: L77HDE15SD1CH4F; DSUB-15-HD_Female_Horizontal_P2.29x1.98mm_EdgePinOffset8.35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
R31: 1K; R_0603_1608Metric
R33: 0; R_0603_1608Metric
R34, R35: 27; R_0603_1608Metric
R36: R_0805; R_0805_2012Metric
R37, R54, R55: 100; R_0805_2012Metric
R38, R41, R44: 1k; R_0402_1005Metric
R39: 390; R_0402_1005Metric
R40, R43: 2k2; R_0402_1005Metric
R42, R45: 470; R_0402_1005Metric
RNP1, RNP2: 4k7; R_0805_2012Metric
SW6: Boot Sel; SW_SPST_PTS810
SW7: VGA RESET; SW_SPST_PTS810
TP22, TP23, TP24: TestPoint_Harwin; TestPoint_Pad_D1.0mm
U19: W25Q128JVS; SOIC-8_5.23x5.23mm_P1.27mm
U22: 74HCT245; SO-20_5.3x12.6mm_P1.27mm
U23: RP2040; RP2040-QFN-56
U24, U25: 74LVC2G04; SOT-23-6
U31: 74LVC2G04-DNP; SOT-23-6
Y2: ECS-120-18-33-JEM-TR; Crystal_SMD_3225-4Pin_3.2x2.5mm

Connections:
+1V1: C41.1, C42.1, C43.1, U23.23 (DVDD), U23.45 (VREG_VOUT), U23.50 (DVDD); also elsewhere on the board
/mega-6502/14M: U24.1; also elsewhere on the board
/mega-6502/RGB1: U22.5 (A3); also elsewhere on the board
/mega-6502/RGB2: U22.3 (A1); also elsewhere on the board
/mega-6502/RGB4: U22.6 (A4); also elsewhere on the board
/mega-6502/RGB8: U22.4 (A2); also elsewhere on the board
/mega-6502/SERVID: U22.2 (A0); also elsewhere on the board
/mega-6502/~SYNC: U22.7 (A5); also elsewhere on the board
/mega-6502/~WINDOW: U22.8 (A6); also elsewhere on the board
/rp2040-keyboard/RX_2040: U23.6 (GPIO4); also elsewhere on the board
/rp2040-keyboard/TX_2040: U23.7 (GPIO5); also elsewhere on the board
/rp2040-keyboard/VID_EN: J18.10, SW7.2, U23.26 (RUN)
/video/7M: U31.1
/video/7M_RP: U23.15 (GPIO12), U31.4
/video/14M_RP: U23.16 (GPIO13), U24.4
/video/BLU0: R38.2, U23.41 (GPIO29_ADC3)
/video/BLU1: R39.2, U23.40 (GPIO28_ADC2)
/video/D_N: R35.2, U23.46 (USB_DM)
/video/D_P: R34.2, U23.47 (USB_DP)
/video/GRN0: R40.2, U23.39 (GPIO27_ADC1)
/video/GRN1: R41.2, U23.38 (GPIO26_ADC0)
/video/GRN2: R42.2, U23.37 (GPIO25)
/video/HSYNC: R54.2, TP24.1, U23.32 (GPIO21)
/video/RED0: R43.2, U23.36 (GPIO24)
/video/RED1: R44.2, U23.35 (GPIO23)
/video/RED2: R45.2, U23.34 (GPIO22)
/video/RGB1_RP: U22.16 (B2), U23.18 (GPIO15)
/video/RGB2_RP: U22.17 (B1), U23.17 (GPIO14)
/video/RGB4_RP: U22.14 (B4), U23.28 (GPIO17)
/video/RGB8_RP: U22.15 (B3), U23.27 (GPIO16)
/video/SERVID_RP: U22.18 (B0), U23.14 (GPIO11)
/video/USB_D+: J17.3 (D+), R34.1
/video/USB_D-: J17.2 (D-), R35.1
/video/VGA_B: J22.3, R38.1, R39.1
/video/VGA_G: J22.2, R40.1, R41.1, R42.1
/video/VGA_R: J22.1, R43.1, R44.1, R45.1
/video/VGA_SCL: J22.15, RNP2.1
/video/VGA_SDA: J22.12, RNP1.1
/video/VSYNC: R55.2, TP23.1, U23.31 (GPIO20)
/video/vid_LED_L: R36.1, U23.5 (GPIO3)
/video/vid_QSPI_SCLK: U19.6 (CLK), U23.52 (QSPI_SCLK)
/video/vid_QSPI_SD0: U19.5 (DI(IO0)), U23.53 (QSPI_SD0)
/video/vid_QSPI_SD1: U19.2 (DO(IO1)), U23.55 (QSPI_SD1)
/video/vid_QSPI_SD2: U19.3 (IO2), U23.54 (QSPI_SD2)
/video/vid_QSPI_SD3: U19.7 (IO3), U23.51 (QSPI_SD3)
/video/vid_QSPI_SS: R31.1, SW6.2, U19.1 (~CS), U23.56 (QSPI_SS)
/video/vid_SWCLK: J18.04, U23.24 (SWCLK)
/video/vid_SWD: J18.02, U23.25 (SWD)
/video/vid_XIN: C38.1, U23.20 (XIN), Y2.1
/video/vid_XOUT: R33.1, U23.21 (XOUT)
/video/~RESET_RP: U23.13 (GPIO10), U25.4
/video/~RESET: U25.1
/video/~SYNC_RP: U22.13 (B5), U23.29 (GPIO18)
/video/~WINDOW_RP: TP22.1, U22.12 (B6), U23.30 (GPIO19)
GND: C35.2, C36.2, C37.2, C38.2, C39.2, C40.2, C41.2, C42.2, C43.2, C44.2, C45.2, C46.2, C48.2, C49.2, C50.2, C51.2, C65.2, C66.2, C67.2, C68.2, C69.2, D11.1 (K), J17.5 (GND), J18.03, J18.05, J18.09, J22.0, J22.5, J22.6, J22.7, J22.8, J22.10, R31.2, SW6.1, SW7.1, U19.4 (GND), U22.9 (A7), U22.10 (GND), U22.19 (CE), U23.19 (TESTEN), U23.57 (GND), U24.2 (GND), U25.2 (GND), U31.2 (GND), Y2.2, Y2.4; also elsewhere on the board
unnamed: C39.1, R33.2, Y2.3
unnamed: D11.2 (A), R36.2
unnamed: J22.9, R37.2
unnamed: J22.13, R54.1
unnamed: J22.14, R55.1
unnamed: U24.3, U24.6
unnamed: U25.3, U25.6
unnamed: U31.3, U31.6

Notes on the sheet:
Crystal
VGA
Flash
VGA concept from this project: http://www.breatharian.eu/hw/picovga/index_en.html
TODO: Remove SERVID from VGA2040
pg13 of RP2040 datasheet has GPIO table
VGA 'DAC'
USB Micro Out


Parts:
C47, C52, C71, C72: .1u; C_0805_2012Metric
C53, C70, C73, C74: 22n; C_0805_2012Metric
C80, C81: 1u; C_0805_2012Metric
D12: AN0; LED_1206_3216Metric
D13: AN1; LED_1206_3216Metric
D14: AN2; LED_1206_3216Metric
D15: AN3; LED_1206_3216Metric
J11: Game Port; DIP-16_W7.62mm_Socket
J23: Game-DB VERIFY FOOTPRINT; DSUB-9_Female_Horizontal_P2.77x2.84mm_EdgePinOffset4.94mm_H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
Q4, Q5, Q6, Q7: BC817; SOT-23
R20, R57, R61, R65, R67: 4k7; R_0805_2012Metric
R46: 10u; R_0805_2012Metric
R56: 1u; R_0805_2012Metric
R58, R64, R66, R72: 470; R_0805_2012Metric
R59, R60, R68, R69: 1K; R_0805_2012Metric
R62, R63, R70, R71: 100; R_0805_2012Metric
TP1, TP28, TP29, TP30, TP31: TestPoint; TestPoint_Pad_D1.0mm
U18: HCT251; SOIC-16_3.9x9.9mm_P1.27mm; MPN 74HCT251D,652
U20, U21: NE556; SO-14_3.9x8.65mm_P1.27mm

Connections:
/IWM/MD7: U18.5 (Y); also elsewhere on the board
/Slot/AN0: J11.15, R57.2; also elsewhere on the board
/Slot/AN1: J11.14, R61.2; also elsewhere on the board
/Slot/AN2: J11.13, R65.2; also elsewhere on the board
/Slot/AN3: J11.12, R67.2; also elsewhere on the board
/game_port/BA0: U18.11 (A)
/game_port/BA1: U18.10 (B)
/game_port/BA2: U18.9 (C)
/game_port/CP0: R60.2, U18.15 (D4), U21.5 (Q)
/game_port/CP1: R68.2, U18.14 (D5), U20.9 (Q)
/game_port/CP2: R69.2, U18.13 (D6), U21.9 (Q)
/game_port/CP3: R59.2, U18.12 (D7), U20.5 (Q)
/game_port/DIS0: TP28.1, U21.1 (DIS)
/game_port/DIS1: TP29.1, U20.13 (DIS)
/game_port/DIS2: TP30.1, U21.13 (DIS)
/game_port/DIS3: TP1.1, U20.1 (DIS)
/game_port/PDL0: J11.6, J23.5, R62.1
/game_port/PDL1: J11.10, J23.8, R70.1
/game_port/PDL2: J11.7, J23.4, R71.1
/game_port/PDL3: J11.11, J23.9, R63.1
/game_port/STB: J11.5, R20.2
/game_port/SW0_OAPL: J11.2, J23.7, U18.3 (D1)
/game_port/SW1_CAPL: J11.3, J23.1, U18.2 (D2)
/game_port/SW2: J11.4, J23.6, U18.1 (D3)
/game_port/SW3: J11.9, U18.4 (D0)
/game_port/~C060-67: U18.7 (G); also elsewhere on the board
/game_port/~PDLTRIG: TP31.1, U20.6 (TR), U20.8 (TR), U21.6 (TR), U21.8 (TR); also elsewhere on the board
GND: C47.2, C52.2, C53.2, C70.2, C71.2, C72.2, C73.2, C74.2, C80.2, C81.2, J11.8, J23.3, Q4.2 (E), Q5.2 (E), Q6.2 (E), Q7.2 (E), R46.2, R56.2, U18.8 (GND), U20.7 (GND), U21.7 (GND); also elsewhere on the board
unnamed: C47.1, U20.3 (CV)
unnamed: C52.1, U21.3 (CV)
unnamed: C53.1, R62.2, U21.2 (THR)
unnamed: C70.1, R63.2, U20.2 (THR)
unnamed: C71.1, U20.11 (CV)
unnamed: C72.1, U21.11 (CV)
unnamed: C73.1, R70.2, U20.12 (THR)
unnamed: C74.1, R71.2, U21.12 (THR)
unnamed: D12.1 (K), R58.1
unnamed: D13.1 (K), R64.1
unnamed: D14.1 (K), R66.1
unnamed: D15.1 (K), R72.1
unnamed: Q4.1 (B), R57.1
unnamed: Q4.3 (C), R58.2
unnamed: Q5.1 (B), R61.1
unnamed: Q5.3 (C), R64.2
unnamed: Q6.1 (B), R65.1
unnamed: Q6.3 (C), R66.2
unnamed: Q7.1 (B), R67.1
unnamed: Q7.3 (C), R72.2

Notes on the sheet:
IIe STB is accessed by $C040, but IIgs just ties high


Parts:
C58, C60, C61: 1u; R_0805_2012Metric
C59: 220n; R_1206_3216Metric
C62: 100u; CP_EIA-3216-18_Kemet-A; MPN T520A107M006ATE035
D2: SNDZ; LED_1206_3216Metric
J19: SPKR; PinHeader_1x02_P2.54mm_Vertical
J20: Ears; Jack_3.5mm_tensility_54-00177; MPN 54-00178
Q2: BC817; SOT-23
R8: 1; R_0805_2012Metric
R9: 2; R_0805_2012Metric
R10, R49: 10k; R_0805_2012Metric
R48: 220; R_0805_2012Metric
R50: 150; R_0805_2012Metric
RNP3: 1k; R_0805_2012Metric
U26: MCP4541T; MSOP-8_3x3mm_P0.65mm
U27: LM4875; SOIC-8_3.9x4.9mm_P1.27mm

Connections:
/Audio/AUD_SCL: U26.2 (SCL)
/Audio/AUD_SDA: U26.3 (SDA)
/Audio/DC_Vol: U26.6 (P0W), U27.4 (DC_Vol)
/Audio/EAR: C62.2, J20.3 (R), J20.4 (T), R50.1
/Audio/HP_Sense: J20.6 (TN), R49.2, U27.3 (HP_Sense)
/Audio/SCALE_AUD: C59.1, R8.2, R9.1
/Audio/SPKR: R8.1, R10.2; also elsewhere on the board
/Audio/Vo1: C62.1, J19.1, RNP3.1, U27.5 (Vo1)
/Audio/Vo2: J19.2, U27.8 (Vo2)
GND: C58.2, C60.2, C61.2, J20.2 (S), Q2.2 (E), R9.2, R49.1, R50.2, RNP3.2, U26.1 (HVC/H0), U26.4 (Vss), U26.5 (P0A), U27.6 (GND); also elsewhere on the board
unnamed: C59.2, U27.2 (-Vin)
unnamed: C60.1, U27.7 (Bypass)
unnamed: D2.1 (K), R48.2
unnamed: Q2.1 (B), R10.1
unnamed: Q2.3 (C), R48.1

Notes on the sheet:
Are we scaling the audio on demo board?
RNP is for external drain resistor for 100uF cap.
54-00177 and 54-00178 seem to have similar functionality. Originally I ordered the `8 but seemingly designed to `7's pinout. Is the `7 the same as the "default" symbol in Kicad?


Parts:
C12, C13, C14, C15: 10u; C_0805_2012Metric
D3: DSK1; LED_1206_3216Metric
D16: DSK2; LED_1206_3216Metric
J2: DB19_4; PinHeader_1x02_P2.54mm_Vertical-LOCK
J3: DB19_16; PinHeader_1x02_P2.54mm_Vertical-LOCK
J4, J7, J8: EN; PinHeader_1x03_P2.54mm_Vertical-LOCK
J5: DSUB19; DSUB-19_Apple_II_Floppy
J6: FDC Hdr; PinHeader_2x10_P2.54mm_Vertical
Q8, Q9: BC817; SOT-23
R11, R12, R13, R14, R15, R16, R17, R18: 22; R_0805_2012Metric
R19, R75: 470; R_0805_2012Metric
R76, R77: 4k7; R_0805_2012Metric
U11: IWM; PLCC-28_THT-Socket
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

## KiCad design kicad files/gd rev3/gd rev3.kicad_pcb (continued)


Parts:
C6, C30, C34: 1u; C_0805_2012Metric
C20, C21, C25, C27, C28, C29, C31, C32, C33: 100n; C_0603_1608Metric
C22, C26, C76, C77, C82: 1u; C_0603_1608Metric
C23, C24: 27p; C_0603_1608Metric
C57: 10u; C_0805_2012Metric
C64: 100n; C_0805_2012Metric
D7: 5V_PWR; LED_1206_3216Metric
D8, D9: 3V3_PWR; LED_1206_3216Metric
J13: SWD; SAMTEC_FTSH-105-XX-X-DV; PARTREV H
J14: USB_A; USB_A_GCT_USB1125; MPN USB1125-GF-B
J21: KBD Serial; PinSocket_1x03_P2.54mm_Vertical
Q3: BC817; SOT-23
R21: 0; R_0603_1608Metric
R22, R23: 27; R_0603_1608Metric
R24, R25, R52, R53: 4k7; R_0805_2012Metric
R26, R32, R51: 1K; R_0805_2012Metric
SW4: KBD RESET; SW_SPST_PTS810
U14: RP2040; RP2040-QFN-56
U15: MIC5504-3.3YM5; SOT-23-5
U16: 74HC245; SOIC-20W_7.5x12.8mm_P1.27mm
U17: W25Q128JVS; SOIC-8_5.23x5.23mm_P1.27mm
U28: SN74LVC573ANS; SO-20_5.3x12.6mm_P1.27mm
U29, U30: 74LVC2G04; SOT-23-6
Y1: ECS-120-18-33-JEM-TR; Crystal_SMD_3225-4Pin_3.2x2.5mm
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

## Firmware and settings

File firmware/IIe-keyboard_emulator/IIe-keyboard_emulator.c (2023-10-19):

/* 
 * The MIT License (MIT)
 *
 * Copyright (c) 2020-2022 James Lewis
 *
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
 */


#include "IIe-keyboard_emulator.h"

queue_t keycode_queue;

// old habits die hard
static inline uint32_t millis() {
    return ((time_us_32() / 1000));
}

// trying to reduce bus contention
bool repeating_timer_callback(struct repeating_timer *t) {
    dousb = true;
    return true;
}

//TODO Need to remove all references now that VGA works
void set_color_mode(bool state) {
    #if Mega_IIe_Rev2
        gpio_put(COLOR_MODE_PIN, state);
    #elif Mega_IIe_Rev3
        return;
    #endif
}

void queue_key(uint8_t key) {
    // if the PIO is ready, let's send in the character now
  //  if (pio_interrupt_get(pio,1) && queue_is_empty(&keycode_queue)) {
    if (key == '\0') // happens when function keys get pressed...
        return;
    D(printf("Im[%c]", key);)
    if (queue_is_empty(&keycode_queue)) {
        write_key(key);  
    }  else if (!queue_try_add(&keycode_queue, &key))
        printf("Failed to add [%c]\n", key);
}

static inline void empty_keyboard_queue() { 
    while (!queue_is_empty(&keycode_queue)) {
        uint8_t throwaway = '\0';
        queue_try_remove(&keycode_queue, &throwaway);
        printf("%c",throwaway);
    }
}
// TODO  pass references to pio stuff so I can move to another file
void reset_mega(uint8_t reset_type) {
    //reset_type = cold or warm

    printf("\nDisabling Mega-II...");
    gpio_put(RESET_CTL, 0x1);
    printf("\nReseting PIO...");
    pio_sm_set_enabled(pio, pio_sm, false);
    pio_sm_set_enabled(pio, pio_sm_1, false);
    pio_sm_restart(pio, pio_sm);
    pio_sm_restart(pio, pio_sm_1);
   // hid_app_task();
    tuh_task();
    printf("\nPausing");
    busy_wait_ms(250);
   // hid_app_task();
    tuh_task();
    printf("...[DONE]");
    printf("\nClearing Keyboard Queue..."); // queue_free() keeps causing hardfault
    empty_keyboard_queue();
    printf(" [Done].");
    printf("\nRenabling PIO...");
    pio_sm_set_enabled(pio, pio_sm, true);
    pio_sm_set_enabled(pio, pio_sm_1, true);
    printf("\nEnabling Mega-II...\n");
    gpio_put(RESET_CTL, 0x0);
}

void write_key(uint8_t key) {
    pio_sm_put(pio, pio_sm_1, key & 0x7F); 
    pio_sm_put(pio, pio_sm, 0x3);
    pio_interrupt_clear(pio, 1);
}

void raise_key() { // I don't remember why this is an if-statement, oh well, lolz.
    if (!pio_interrupt_get(pio,1)) {  //If irq 1 is clear we have a new key still
        pio_sm_put(pio, pio_sm,0x1);
    } else {
        pio_sm_put(pio, pio_sm,0x0);
    }
}

inline static uint8_t handle_serial_keyboard() {
    uint8_t incoming_char = getchar_timeout_us(0);
    // MEGA-II only seems to like these values
    if ((incoming_char > 0) && (incoming_char < 128)) {
        return incoming_char;
    }
    return 0;
}

// shortcut for setting up output pins (there isn't a SDK call for this?)
void out_init(uint8_t pin, bool state) {
    gpio_init(pin);
    gpio_set_dir(pin, GPIO_OUT);
    gpio_put(pin, state);
}

// For the blinky led
bool case_led_blink(struct repeating_timer *t) {
    if (kbd_led_state[1])
        kbd_led_state[1] = 0x0;
    else
        kbd_led_state[1] = 0x1;
    out_init(KBD_LED_PIN, kbd_led_state[1]);
    return true;
}

#define BLINK_OFF  0
#define BLINK_SLOW 1
#define BLINK_MED  2
#define BLINK_FAST 3
#define BLINK_ON   9

void blink_case_led(int speed) {
    switch (speed) {
        case BLINK_OFF:
        break;

        case BLINK_SLOW:
        break;

        case BLINK_MED:
        break;

        case BLINK_FAST:
        break;

        case BLINK_ON:
        break;

        default:
            printf("Got speed (%d) and no understand...\n", speed);
    }

}

bool audio_variable_debug;

static inline void handle_volume_control() {
    static uint16_t previous_audio_volume = 0;
    static uint32_t previous_audio_write = 0;
    static uint32_t previous_wiper_check = 0;
    static bool previous_audio_mute = true;
    static bool eeprom_write_flag = false;

    if (previous_audio_mute != audio_mute) {
        if (audio_mute) {
            // enter mute state
            write_mcp4541_wiper(MCP4541_MAX_STEPS, false);
        } else {
            // exit mute state
            previous_audio_volume = MCP4541_MAX_STEPS;
            audio_volume = read_mcp4541_eeprom();
        }
        previous_audio_mute = audio_mute;
    }
    if (audio_mute)
        return;
    
    if (audio_volume != previous_audio_volume) {
        write_mcp4541_wiper(audio_volume, false);
        previous_audio_write = time_us_32();
        eeprom_write_flag = true;
    }

    if (time_us_32() - previous_wiper_check >= WIPER_CHECK_INTERVAL) {
        int current_wiper_value = read_mcp4541_wiper();
        if (current_wiper_value < 0) {
            printf("Wiper Check Error: [%d]\n", current_wiper_value);
        }
        
        // for some reason, we're out of sync, force them different for next iteration
        if (audio_volume != current_wiper_value) {
            printf("ERROR: Audio level wrong. wiper:[%d], eeprom:[%d], variable[%d]\n", read_mcp4541_wiper(), read_mcp4541_eeprom(), audio_volume);
            previous_audio_volume = audio_mute-1;
        }

        previous_wiper_check = time_us_32();
    }

    // only update the EEPROM after user stops mashing the button.
    if (eeprom_write_flag && time_us_32() - previous_audio_write >= MCP4541_EEPROM_WAIT){
        write_mcp4541_eeprom(audio_volume);
        eeprom_write_flag = false;
    }

    if (audio_variable_debug) {
        audio_variable_debug = false;
        printf("[DEBUG] Audio levels. wiper:[%d], eeprom:[%d], variable[%d]\n", read_mcp4541_wiper(), read_mcp4541_eeprom(), audio_volume);

    }
    previous_audio_volume = audio_volume;
}

// put your setup code here, to run once:
void setup() {

    #if Mega_IIe_Rev2
        printf("\nConfiguring DEBUG Pin (%d)", DEBUG_PIN);     // debug pin to trigger the external logic analyzer
        out_init(DEBUG_PIN, 0x0);
    #elif Mega_IIe_Rev3
        kbd_led_state[1] = 0x1;
        printf("\nConfiguring Case LED Pin(%d)", KBD_LED_PIN);
        out_init(KBD_LED_PIN, kbd_led_state[1]);
    #endif

    struct repeating_timer case_led_timer;
    add_repeating_timer_ms(150, case_led_blink, NULL, &case_led_timer);
   
    stdio_init_all();  // UART accepts input and displays debug infos
   // busy_wait_ms(10);

    // yay usb!
    printf("\nEnabling tinyUSB Host");
    tusb_init();

    printf("\nInit Suppy Pins");
    setup_power_sequence();

    printf("\nConfiguring RESET_CTRL Pin (%d)", RESET_CTL);
    out_init(RESET_CTL, 0x0);

    mega_power_state = PWR_OFF;
    handle_power_sequence(mega_power_state);

    //audio_volume = (MCP4541_MAX_STEPS/2);
    printf("\nSetting up Audio I2C Interface...");
    setup_i2c_audio();

    // Get VGA2040 Ready To Go
    #if Mega_IIe_Rev3
        printf("\nConfiguring VID_ENABLE Pin (%d)", VID_ENABLE);
        out_init(VID_ENABLE, 0x1);
    #endif
    
    // BEEP BEEP BEEP
    #if Mega_IIe_Rev3
        headphone_status = gpio_get(HP_SENSE);
        // i2c setup stuff for AUD_SDA and AUD_SCL here
    #endif

    // Preload Reset state (is this needed?)
    #if Mega_IIe_Rev3
        reset_state = gpio_get(RESET_STATUS);
    #endif

    // helps with throtting usb (may get fixed in future TinyUSB, I hope)
 /*   printf("\nEnabling tuh_task");
    add_repeating_timer_ms(-2, repeating_timer_callback, NULL, &timer2);
    printf("\n(---------");*/

    // configure I/O control lines
    printf("\nConfiguring OAPL and CAPL");
    out_init(OAPL_pin, 0x0);
    out_init(CAPL_pin, 0x0);

    printf("\nConfiguring KBD PIO State Machine");
    KBD_pio_setup();

    printf("\nConfiguring key code queue");
    queue_init(&keycode_queue, sizeof(uint8_t), 10); // really only need 6, but wutwevers
 
// line 164 assertion error:
// https://github.com/raspberrypi/pico-sdk/issues/649
    while(!kbd_connected) {
        tuh_task();
        static uint32_t prev_micros;
        if (time_us_32() - prev_micros >= 2500000) {
            prev_micros = time_us_32();
            //printf("Keyboard not detected...(resetting)\n");
            printf("Keyboard not detected...\n");
            //hcd_port_reset(0);
        }
    }
    printf("Keyboard Detected, yay");

    tuh_task();
    int boot_wait_time = 2;
    printf("\nPausing for %d seconds ...", boot_wait_time);
    for (int x=boot_wait_time; x>=0; x--) {
        printf("%d...",x);
        for (int y=0; y<100; y++) {
            busy_wait_ms(10);
            tuh_task();
        }
    }

    mega_power_state = PWR_ON;
    handle_power_sequence(mega_power_state);
    bool cancelled = cancel_repeating_timer(&case_led_timer);
    printf("\nCancelled LED timer: %d\n", cancelled);

    printf("\n\n---------\nMega IIe Keyboard Emulatron 2000\n\nREADY.\n] ");
}

inline static void handle_apple_keys() {
    gpio_put(OAPL_pin, OAPL_state);
    gpio_put(CAPL_pin, CAPL_state);
}

inline static void handle_serial_buffer() {
    static uint32_t prev_serial_clear = 0;
    static bool serial_clear = false;

    uint8_t key_value = handle_serial_keyboard(); 
    if (key_value > 0) {
        if (key_value == 0x12) { // should be CTRL-R
            reset_mega(1); // 0 = cold, 1 = warm
        } else {
            //prepare_key_value(key_value);
            printf("%c",key_value);
            queue_key(key_value);
            serial_clear = true;
            prev_serial_clear = millis();
        }
    }

    // deassert ANYKEY when receiving characters over serial
    if (serial_clear && (millis() - prev_serial_clear >= serial_anykey_clear_interval)) {
        serial_clear = false; 
        //pio_sm_put(pio, pio_sm, (0x0));
        raise_key();
    }
}

inline static void handle_three_finger_reset() {
    if (do_a_reset) {
        struct repeating_timer case_led_timer;
        add_repeating_timer_ms(150, case_led_blink, NULL, &case_led_timer);
        do_a_reset = false;
        busy_wait_ms(THREE_FINGER_WAIT);
        reset_mega(0);
        bool cancelled = cancel_repeating_timer(&case_led_timer);
        printf("\nCancelled LED timer: %d\n", cancelled);
        kbd_led_state[1] = 0x1; // turn LED back on!
        out_init(KBD_LED_PIN, kbd_led_state[1]);

    }
}   

inline static void handle_runstop_button() {
    if (power_cycle_key_counter >= 3) {
        // do a power cycle
        mega_power_state = !mega_power_state;
        handle_power_sequence(mega_power_state);
        power_cycle_key_counter = 0;
        D(printf("Power State Now: (%d)", mega_power_state);)
    }

    if (time_us_32() - power_cycle_timer >= POWER_CYCLE_INTERVAL)
        power_cycle_key_counter = 0;
}

inline static void handle_pio_keycode_queue() {
     // keep the PIO queue full
    if (pio_interrupt_get(pio,1) && !queue_is_empty(&keycode_queue)) {
        uint8_t next_key;
        if (queue_try_remove(&keycode_queue, &next_key))
            write_key(next_key);
    }
}

#define MACRO_WAIT 10

void queue_macro_string(char *msg, bool before_cr, bool after_cr, bool after_sp) {
    int x = 0;
    struct repeating_timer case_led_timer;
    add_repeating_timer_ms(25, case_led_blink, NULL, &case_led_timer);

    if (before_cr) {
        queue_key(13);
        busy_wait_ms(MACRO_WAIT*5);
    }

    while (msg[x] != '\0') {
        queue_key(msg[x]);
        busy_wait_ms(MACRO_WAIT);
        x++;
        if (x >= 10)
            tuh_task();
    }
    busy_wait_ms(MACRO_WAIT*5);
    if (after_cr)
        queue_key(13);
    if (after_sp)
        queue_key(' ');
    printf("Queued %d chars\n", x);

    bool cancelled = cancel_repeating_timer(&case_led_timer);
    printf("\nCancelled LED timer: %d\n", cancelled);
    kbd_led_state[1] = 0x1; // turn LED back on!
    out_init(KBD_LED_PIN, kbd_led_state[1]);
}

inline static void handle_macros() {
    char macro_string[32];
    if (function_key_macros.Print) {
        function_key_macros.Print = false;
        //printf("Print Macro\n");
        sprintf(macro_string, "PRINT");
        queue_macro_string(macro_string, false, false, true);
    }

    if (function_key_macros.Input) {
        function_key_macros.Input = false;
        //printf("Input Macro\n");
        sprintf(macro_string, "INPUT");
        queue_macro_string(macro_string, false, false, true);
    }

    if (function_key_macros.Poke) {
        function_key_macros.Poke = false;
        //printf("Poke Macro\n");
        sprintf(macro_string, "POKE");
        queue_macro_string(macro_string, false, false, true);
    }

    if (function_key_macros.Peek) {
        function_key_macros.Peek = false;
        //printf("Peek Macro\n");
        sprintf(macro_string, "PEEK");
        queue_macro_string(macro_string, false, false, true);
    }

    if (function_key_macros.Call) {
        function_key_macros.Call = false;
        //printf("Call Macro\n");
        sprintf(macro_string, "CALL");
        queue_macro_string(macro_string, false, false, true);
    }

    if (function_key_macros.PR) {
        function_key_macros.PR = false;
        //printf("PR Macro\n");
        if (function_key_macros.shift)
            sprintf(macro_string, "PR #3");
        else
            sprintf(macro_string, "PR #6");
        queue_macro_string(macro_string, false, true, false);
    }

    if (function_key_macros.Text) {
        function_key_macros.Text = false;
        //printf("Text Macro\n");
        if (function_key_macros.shift)
            sprintf(macro_string, "GR");
        else
            sprintf(macro_string, "TEXT");
        queue_macro_string(macro_string, false, true, false);
    }

    if (function_key_macros.Home) {
        function_key_macros.Home = false;
        //printf("Home Macro\n");
        sprintf(macro_string, "HOME");
        queue_macro_string(macro_string, true, true, false);
    }

    if (function_key_macros.n151) {
        function_key_macros.n151 = false;
        //printf("-151 Macro\n");
        sprintf(macro_string,"CALL");
        queue_macro_string(macro_string, true, false, true);
        tuh_task();
        sprintf(macro_string, "-151");
        queue_macro_string(macro_string, false, true, false);
    }

    if (function_key_macros.x3F4) {
        function_key_macros.x3F4 = false;
        //printf("3F4 Macro\n");
        sprintf(macro_string, "3F4");
        queue_macro_string(macro_string, true, true, false);
        tuh_task();
        busy_wait_ms(100);
        sprintf(macro_string, ":00");
        tuh_task();
        queue_macro_string(macro_string, false, true, false);
        if (function_key_macros.shift)
            do_a_reset = true;
    }

    if (function_key_macros.p1012) {
        function_key_macros.p1012 = false;
        //printf("1012 Macro\n");
        sprintf(macro_string, "POKE");
        queue_macro_string(macro_string, true, false, true);
        tuh_task();
        sprintf(macro_string, "1012,1");
        queue_macro_string(macro_string, false, true, false);
        if (function_key_macros.shift)
            do_a_reset = true;
    }


    
}

inline static void handle_nkey_repeats() {
    switch (nkey) {               
        case NKEY_NEW:
            nkey_last_press = time_us_32();
            nkey = NKEY_ARMED;
        break;

        case NKEY_ARMED:
            if ((time_us_32() - nkey_last_press) >= nkey_wait_us) {
                nkey = NKEY_REPEATING;
            }
        break;

        case NKEY_REPEATING:
            if ((time_us_32() - nkey_last_press) >= nkey_repeat_us) {
                queue_key(last_key_pressed);
                nkey_last_press = time_us_32();
            }
        break;

        case NKEY_IDLE:
        default:

        break;
    }
}

int main() {
    setup();

    while (BALD_ENGINEER_IS_BALD) {
        // hid_app_task();
        tuh_task();

        handle_runstop_button();
        handle_apple_keys();
        handle_three_finger_reset();
        //handle_mega_power_button();
        handle_serial_buffer();
        handle_pio_keycode_queue();
        handle_nkey_repeats();
        handle_volume_control();
        handle_macros();
    } // while (true)
    return 0;  // but you never will hah!
} // it's da main thing

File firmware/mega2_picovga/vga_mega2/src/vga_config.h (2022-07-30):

// ****************************************************************************
//                                 
//                            VGA configuration
//
// ****************************************************************************

// === Configuration
#define LAYERS		4	// total layers 1..4 (1 base layer + 3 overlapped layers)
#define SEGMAX		8	// max. number of video segment per video strip (size of 1 sSegm = 28 bytes)
#define STRIPMAX	8	// max. number of video strips (size of 1 sStrip = sSegm size*SEGMAX+4 = 228 bytes)
				// size of sScreen = sStrip size*STRIPMAX+4 = 1828 bytes

#define MAXX		800	// max. resolution in X direction (must be power of 4)
#define MAXY		600	// max. resolution in Y direction

#define MAXLINE		700	// max. number of scanlines (including sync and dark lines)

// === Scanline render buffers (800 pixels: default size of buffers = 2*4*(800+8+800+24)+800 = 13856 bytes
//    Requirements by format, base layer 0, 1 wrap X segment:
//	GF_GRAPH8 ... control buffer 16 bytes
//	GF_TILE8 ... control buffer "width"+8 bytes
//	GF_TILE16 ... control buffer "width/2"+8 bytes
//	GF_TILE32 ... control buffer "width/4"+8 bytes
//	GF_TILE64 ... control buffer "width/8"+8 bytes
//	GF_PROGRESS ... control buffer 24 bytes
//	other formats: data buffer "width" bytes, control buffer 16 bytes
#define DBUF0_MAX	(MAXX+8)	// max. size of data buffer of layer 0
#define CBUF0_MAX	((MAXX+24)/4)	// max. size of control buffer of layer 0

//    Requirements by format, overlapped layer 1..3:
//	LAYERMODE_SPRITE* ... data buffer "width"+4 bytes, control buffer 24 bytes
//	LAYERMODE_FASTSPRITE* ... data buffer "width"+4 bytes, control buffer up to "width*2"+16 bytes
//	other formats ... data buffer 4 bytes, control buffer 24 bytes
#define DBUF1_MAX	(MAXX+8)	// max. size of data buffer of layer 1
#define CBUF1_MAX	((MAXX+24)/4)	// max. size of control buffer of layer 1

#define DBUF2_MAX	(MAXX+8)	// max. size of data buffer of layer 2
#define CBUF2_MAX	((MAXX+24)/4)	// max. size of control buffer of layer 2

#define DBUF3_MAX	(MAXX+8)	// max. size of data buffer of layer 3
#define CBUF3_MAX	((MAXX+24)/4)	// max. size of control buffer of layer 3

#if LAYERS==1
#define	DBUF_MAX	DBUF0_MAX	// max. size of data buffer
#define	CBUF_MAX	CBUF0_MAX	// max. size of control buffer
#elif LAYERS==2
#define	DBUF_MAX	(DBUF0_MAX+DBUF1_MAX)	// max. size of data buffer
#define	CBUF_MAX	(CBUF0_MAX+CBUF1_MAX)	// max. size of control buffer
#elif LAYERS==3
#define	DBUF_MAX	(DBUF0_MAX+DBUF1_MAX+DBUF2_MAX)	// max. size of data buffer
#define	CBUF_MAX	(CBUF0_MAX+CBUF1_MAX+CBUF2_MAX)	// max. size of control buffer
#elif LAYERS==4
#define	DBUF_MAX	(DBUF0_MAX+DBUF1_MAX+DBUF2_MAX+DBUF3_MAX) // max. size of data buffer
#define	CBUF_MAX	(CBUF0_MAX+CBUF1_MAX+CBUF2_MAX+CBUF3_MAX) // max. size of control buffer
#else
#error Unsupported number of layers!
#endif

// === VGA port pins
//	GP0 ... VGA B0 blue
//	GP1 ... VGA B1
//	GP2 ... VGA G0 green
//	GP3 ... VGA G1
//	GP4 ... VGA G2
//	GP5 ... VGA R0 red
//	GP6 ... VGA R1
//	GP7 ... VGA R2
//	GP8 ... VGA SYNC synchronization (inverted: negative SYNC=LOW=0x80, BLACK=HIGH=0x00)
// #define VGA_GPIO_FIRST	0	// first VGA GPIO
// #define VGA_GPIO_NUM		9	// number of VGA GPIOs, including HSYNC and VSYNC
// #define VGA_GPIO_OUTNUM	8	// number of VGA color GPIOs, without HSYNC and VSYNC
// #define VGA_GPIO_LAST	(VGA_GPIO_FIRST+VGA_GPIO_NUM-1)	// last VGA GPIO
// #define VGA_GPIO_SYNC	8	// VGA SYNC GPIO

// Rev 2 Pins
// #define VGA_GPIO_FIRST	22	// first VGA GPIO
// #define VGA_GPIO_NUM	8	// number of VGA GPIOs, including HSYNC and VSYNC
// #define VGA_GPIO_OUTNUM	8	// number of VGA color GPIOs, without HSYNC and VSYNC
// #define VGA_GPIO_LAST	(VGA_GPIO_FIRST+VGA_GPIO_NUM-1)	// last VGA GPIO
// #define VGA_GPIO_SYNC	21	// VGA SYNC GPIO

// Rev 3 Pins
#define VGA_GPIO_FIRST	22	// first VGA GPIO
#define VGA_GPIO_NUM	8	// number of VGA GPIOs, including HSYNC and VSYNC
#define VGA_GPIO_OUTNUM	8	// number of VGA color GPIOs, without HSYNC and VSYNC
#define VGA_GPIO_LAST	(VGA_GPIO_FIRST+VGA_GPIO_NUM-1)	// last VGA GPIO
#define VGA_GPIO_SYNC	21	// VGA SYNC GPIO

// VGA PIO and state machines
#define VGA_PIO		pio0	// VGA PIO
#define VGA_SM0		0	// VGA state machine of base layer 0
#define VGA_SM1		1	// VGA state machine of overlapped layer 1
#define VGA_SM2		2	// VGA state machine of overlapped layer 2
#define VGA_SM3		3	// VGA state machine of overlapped layer 3
#define VGA_SM(layer)	(VGA_SM0+(layer)) // VGA state machine of the layer

#if LAYERS==1
#define VGA_SMALL	B0	// mask of all state machines
#elif LAYERS==2
#define VGA_SMALL	(B0+B1) // mask of all state machines
#elif LAYERS==3
#define VGA_SMALL	(B0+B1+B2) // mask of all state machines
#elif LAYERS==4
#define VGA_SMALL	(B0+B1+B2+B3) // mask of all state machines
#else
#error Unsupported number of layers!
#endif
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

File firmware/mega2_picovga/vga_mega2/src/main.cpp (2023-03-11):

// ****************************************************************************
//
//                                 Main code
//
// ****************************************************************************

#include <stdio.h>

#include "include.h"
#include "hardware/gpio.h"
#include "hardware/uart.h"
#include "pico/stdlib.h"
#include "main.h"       // main code

void VideoInit()
{
	GenPal16Trans(trans,palwedongongoofedthebits);

	// setup videomode
	VgaCfgDef(&Cfg); // get default configuration
	Cfg.video = &DRV; // video timings
	Cfg.width = WIDTH; // screen width
	Cfg.height = HEIGHT; // screen height
	Cfg.dbly = DBLY;    //Double Line hight. 
	VgaCfg(&Cfg, &Vmode); // calculate videomode setup

    // initialize base layer 0
	//Docs say todo this
	ScreenClear(pScreen);
	//Add a strip which is a "video buffer element" its ewird
	sStrip* t = ScreenAddStrip(pScreen, HEIGHT);
	//This makes our actual 4bpp screen segment
	sSegm* g = ScreenAddSegm(t, WIDTH);
	ScreenSegmGraph4(g, Box,trans, WIDTHBYTE); 

    // initialize system clock
	set_sys_clock_pll(Vmode.vco*1000, Vmode.pd1, Vmode.pd2);

	// initialize videomode
	VgaInitReq(&Vmode);
}

void TEST_CAP_pio_init() {
    // do the setup things
    pio = pio1;
    pio_offset = pio_add_program(pio, &TEST_CAP_program);

    pio_sm = pio_claim_unused_sm(pio, true);
    pio_sm_config c = TEST_CAP_program_get_default_config(pio_offset);
    pio_sm_set_enabled(pio, pio_sm, false);

    sm_config_set_in_pins(&c, FIRST_RGBx); 
    pio_sm_set_consecutive_pindirs(pio, pio_sm, FIRST_INPUT, INPUT_COUNT, GPIO_IN);

    sm_config_set_clkdiv(&c, 1); 

    // From C SDK PDF:
    // sm_config_set_in_shift sets the shift direction to rightward, enables autopush, and sets the autopush threshold to 32.
    // The state machine keeps an eye on the total amount of data shifted into the ISR, and on the in which reaches or
    // breaches a total shift count of 32 (or whatever number you have configured), the ISR contents, along with the new data
    // from the in. goes straight to the RX FIFO. The ISR is cleared to zero in the same operation.
    sm_config_set_in_shift(&c, false, true, 32); // i've setup 8 bits to make this boundry clean, i think
    sm_config_set_fifo_join(&c, PIO_FIFO_JOIN_RX); // PIO_FIFO_JOIN_NONE, _RX, _TX
    pio_sm_init(pio, pio_sm, pio_offset, &c);

    magic_pio_offset = pio_add_program(pio, &TIM_MAGIC_program);
    magic_pio_sm = pio_claim_unused_sm(pio, true);
    pio_sm_config c2 = TIM_MAGIC_program_get_default_config(magic_pio_offset);
    pio_sm_set_enabled(pio, magic_pio_sm, false);

    sm_config_set_clkdiv(&c2,1);
    pio_sm_init(pio, magic_pio_sm, magic_pio_offset, &c2);
    pio_sm_set_enabled(pio, magic_pio_sm, true);
}

void TEST_CAP_pio_arm(uint32_t *capture_buf, size_t capture_size_words) {
    pio_sm_set_enabled(pio, pio_sm, false);
    pio_sm_clear_fifos(pio, pio_sm);  
    pio_sm_restart(pio, pio_sm);

	rgb_dma_chan = 10;// dma_claim_unused_channel(false);
    dma_channel_config c = dma_channel_get_default_config(rgb_dma_chan);
    channel_config_set_read_increment(&c, false);
    channel_config_set_write_increment(&c, true);
	channel_config_set_bswap(&c,true);
    channel_config_set_dreq(&c, pio_get_dreq(pio, pio_sm, false));

    dma_channel_configure(rgb_dma_chan, &c,
        capture_buf,            // Destination pointer
        &pio->rxf[pio_sm],      // Source pointer
        capture_size_words,     // Number of transfers
        true                    // Start immediately
    );

    //puts("[PIO Arm] Starting CAP Pio.");
    //pio_sm_restart(pio, pio_sm);
    pio_sm_exec(pio, pio_sm, pio_encode_jmp(TEST_CAP_offset_start));
    pio_sm_set_enabled(pio, pio_sm, true);
}

void print_hex_buf(const uint32_t *buf, uint word_count, uint line_count) {
    printf("---[START]---\n");
    for (int x=0; x < (word_count * line_count); x++) {   // 
        if (x % 10 == 0)
            printf("\n");
        uint32_t current_word = buf[x];
        printf("%08x", current_word);
    }
    printf("\n---[END]---\n");

}

void print_capture_buf(const uint32_t *buf, uint word_count, uint offset) {
   // printf("Captured: Hex, Binary, RGBx[4 Words, right to left]\n");
    for (int x=0; x < word_count; x++) {
       // printf("%d:%08x, b%b\n", x, buf[x], buf[x]); // lol, %b works
       uint32_t current_buf = buf[x+(word_count*offset)];
        printf("%d:%08x, ", x+(word_count*offset), current_buf); // lol, %b works

        // RGB4 RGB8 RGB1 RGB2
        // 1010 1000 0011 0001 0010 0000 1111 1101
        for (int j=0; j<8; j++) {
            uint offset = 4 * j;
            printf((current_buf & (0x1<<2+(offset))) ? "1" : "0");
            printf((current_buf & (0x1<<3+(offset))) ? "1" : "0");
            printf((current_buf & (0x1<<0+(offset))) ? "1" : "0");
            printf((current_buf & (0x1<<1+(offset))) ? "1" : "0");
            printf((j!=7) ? ", " : "");
        } 
        printf("\n");
    }
    printf("\n");
}

inline uint ctrl_status_led(uint state) {
    switch (state) {
        case LED_OFF:
            led_pin_state = LED_OFF;
            break;
        case LED_ON:
            led_pin_state = LED_ON;
            break;
        case LED_TOG:
            led_pin_state = !led_pin_state;
            break;
    }
    gpio_put(BLINKY_PIN, led_pin_state);
    return led_pin_state;
}


void init_blinky_pin() {
    gpio_init(BLINKY_PIN);
    gpio_set_dir(BLINKY_PIN, GPIO_OUT);
    ctrl_status_led(LED_ON);
    ctrl_status_led(LED_OFF);
}

void check_uart() {
    if (stdio_usb_connected()) {
        while(uart_is_readable(KBD_UART)) {
            char incoming_char = uart_getc(KBD_UART);
                putchar(incoming_char);
        }
    }
}

void fillBox(int color) {
    if (stdio_usb_connected())
       printf("\nDrawing Solid Color");

    for(int i = 0;i<((WIDTHBYTE)*HEIGHT);i++){
        //Box[i]= RandU8();
        Box[i] = color;
    }
}
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

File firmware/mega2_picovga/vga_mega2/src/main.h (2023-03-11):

// ****************************************************************************
//
//                                 Main code
//
// ****************************************************************************

#ifndef _MAIN_H
#define _MAIN_H
// canvas format
#define FORMAT CANVAS_8		// 8-bit pixels

// screen resolution
#define DRV VideoVGA		// timings driver
#define WIDTH	584		// screen width
#define HEIGHT	192		// screen height
#define DBLY	true		// double lines
#define WIDTHBYTE WIDTH/2		// bytes per line
#define WIDTHWORDS WIDTHBYTE/4
#define LINE_COUNT 192

// KBD2040 Interface
#define KBD_UART uart1
#define KBD_BAUD 115200
#define KBD_TX 4
#define KBD_RX 5

// Rev 2
//#define FIRST_RGBx 14
//#define FIRST_INPUT 12
//#define INPUT_COUNT 8
// Rev 3
#define FIRST_RGBx 8
#define FIRST_INPUT 6
#define INPUT_COUNT 8

// Rev 2
//#define WINDOW 19
// Rev 3
#define WINDOW 13

// Rev 2
//const uint BLINKY_PIN=3  ; // 3 on VGA2040
// Rev 3

// Other Pins
#define VSYNC 20
#define BLINKY_PIN 0

// Other Globals
#define LED_OFF 0
#define LED_ON  1
#define LED_TOG 2

bool led_pin_state = LED_ON;

// Palette (Rev3)
u8 palwedongongoofedthebits[16] = {
    0,
    54,
    136,
    188,
    86,
    73,
    220,
    126,
    163,
    183,
    73,
    91,
    215,
    79,
    235,
    255
};

// buffer
extern unsigned char rawData[56064];
ALIGNED u8 Box[(WIDTHBYTE)*HEIGHT];
u16 trans[256];

PIO pio;
uint pio_offset;
uint magic_pio_offset;
uint pio_sm;
uint magic_pio_sm;
uint rgb_dma_chan;


#endif // _MAIN_H



//Old bit patterns
// u8 palwedongongoofedthebits[16] = {
// 0,  //black   0000
// 193, //red    0001
// 4,  // blue   0010
// 206, // pink  0011
// 25, //green   0100
// 82, //grey    0101
// 15, //blue    0110
// 111,//lblue   0111
// 144, //brown  1000
// 216, //organe 1001
// 173, //lgray  1010
// 228, //lpink   1011
// 48, //lgreen  1100
// 248, //yellow 1101
// 124, //teal   1110
// 255 //white   1111
// };
// u8 palwedongongoofedthebits[16] = {
// 0,  //black   0000
// 144, //brown  1000
// 25, //green   0100
// 48, //lgreen  1100
// 4,  // blue   0010
// 173, //lgray  1010
// 15, //blue    0110
// 124, //teal   1110
// 193, //red    0001
// 216, //organe 1001
// 82, //grey    0101
// 228, //lpink  1011
// 206, // pink  0011
// 248, //yellow 1101
// 111,//lblue   0111
// 255 //white   1111
// };

// u8 palwedongongoofedthebits[16] = {
// 0,    // black
// 1,   // red
// 80,  // dark blue
// 109, // purple 
// 196,  // dark green
// 227,  // grey
// 240, // mid blue
// 201, // light blue
// 52,  // dark brown
// 39, // light brown
// 24, // bright grey
// 185, // salmon
// 146,  // lime green
// 175, // yellow
// 248, // light green
// 255 // white
// };

//rev 3
// u8 palwedongongoofedthebits[16] = {
// 0,
// 163, // brown
// 86, // dark green 
// 215, // green
// 136, // drk purple (drk blue)
// 73, // light purple
// 220, // cyan
// 235, // light blue
// 54, // red
// 183, // orange
// 73,
// 79,
// 188,
// 91,
// 126,
// 255
// };

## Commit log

2021-05-15 rev1 of MEGA breakout PCB, before submitting to board house.
    [MegaII Breakout.kicad_pcb, MegaII Breakout.sch]
2021-05-17 initial commit for the debug pcb. empty kicad files.
    [gd debug proto pcb.kicad_pcb, gd debug proto pcb.sch]
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2021-05-22 More grouping components by function. Fixed an error with filtering caps on RGB near video output connector.
    [gd VGC proto pcb.kicad_pcb, gd VGC proto pcb.sch]
2021-05-22 changed some caps to electrolytics and fixed existing diameters to be realistic. better placements around the 1377
    [gd VGC proto pcb.kicad_pcb, gd VGC proto pcb.sch]
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2021-05-24 added some small vias for GND pours that missed
    [gd VGC proto pcb.kicad_pcb]
2021-06-02 Added mounting to VGC board. PDF Of VGC schematic rev1. and created 6502 proto blank project.
    [gd 6502 proto pcb.kicad_pcb, gd 6502 proto pcb.sch, gd VGC proto pcb.kicad_pcb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]
2021-06-02 created w65c02 symbol. realized we need to build a 65c618 (16-bit) board as well. doing that first.
    [gd 6502 proto pcb.sch]
2021-06-02 just kidding on the 65c816.... that won't work unless we re-create the other ASICs too :(
    [w65c816 proto pcb.kicad_pcb, w65c816 proto pcb.sch]
2021-06-04 Made it to adding EPROM before realizing, the Mega-II only has 1 ROM Enable signal. Yet the IIe has two! So... where is the IIe ROM in the IIgs?
    [gd 6502 proto pcb.sch]
2021-06-04 created files for Mega-II proto based on the (now obsolete) Mega-II breakout
    [gd MegaII proto pcb.kicad_pcb, gd MegaII proto pcb.sch]
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2021-06-05 nearly finished mega-ii.... still a few open questions. how does VGC talk to RAM without RAS and CAS? why are there bi-directional buffers on Address to Mega Ii
    [gd MegaII proto pcb.sch]
2021-06-05 created pcb file to get an idea of minimum board size. also removed 0-ohm resistors to a resistor pack
    [gd MegaII proto pcb.kicad_pcb, gd MegaII proto pcb.sch]
2021-06-13 MegaII 0 unrouted but 40+ DRC errors. KiCad doesn't like any of my via placements.
    [gd MegaII proto pcb.kicad_pcb, gd MegaII proto pcb.sch]
2021-06-14 initial 6502 layout with the CPU and headers aligned
    [gd 6502 proto pcb.kicad_pcb, gd 6502 proto pcb.sch]
2021-06-14 can't put buffers under the eeprom. not enough room for all those address lines
    [gd 6502 proto pcb.kicad_pcb, gd 6502 proto pcb.sch]
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2021-06-15 Huge clean-up. Removed some old KiCad stuff, moved the libraries around, added READMEs, added pdfs of rev1 schematic.
    [Video-3.sch, gd 6502 proto pcb.sch, gd debug proto pcb.kicad_pcb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]
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2021-06-16 Interposer to make emulating the IIe ROM easier. (Hopefully)
    [ROM Interposer board.kicad_pcb, ROM Interposer board.sch]
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2021-07-06 adapter for the Slotmaker ASIC. Using generic PLCC44 to DIP44 pinout.
    [PLCC44 to DIP44 Adapter.kicad_pcb, PLCC44 to DIP44 Adapter.sch]
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2021-08-06 corrected symbol placement
    [gd MegaII proto pcb.sch]
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2021-08-17 added address bus to mega-2, routed clocks (minus vgc header), re-routed main data between ROM and backplane connectors, added several missing signals
    [gd MEGA-65c02 proto pcb.kicad_pcb, gd MEGA-65c02 proto pcb.sch]
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2021-08-17 111 to go: routed video clocks, changed video pin headers.
    [gd MEGA-65c02 proto pcb.kicad_pcb, gd MEGA-65c02 proto pcb.sch]
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2021-08-19 finished layout, cleaned up silk, rounded corners, added logos, move power LED
    [gd MEGA-65c02 proto pcb.kicad_pcb, gd MEGA-65c02 proto pcb.sch]
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2021-08-26 created DSUB19 footprint and initial layout of IWM board (with some initial trace ideas)
    [gd IWM proto pcb.kicad_pcb, gd IWM proto pcb.sch]
2021-08-26 removed mounting holes. changed LA headers to 2x connectors. planning to reduce overall space.
    [gd IWM proto pcb.kicad_pcb, gd IWM proto pcb.sch]
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2021-08-26 routed most of critical signals. now trying to get LA headers
    [gd IWM proto pcb.kicad_pcb, gd IWM proto pcb.sch]
2021-08-26 changed Drive LA to use signal after resistor (closer to connector)
    [gd IWM proto pcb.sch]
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2021-08-27 Changed power connector pinout to make backplane more sensible.
    [gd IWM proto pcb.kicad_pcb, gd IWM proto pcb.sch, gd MEGA-65c02 proto pcb.kicad_pcb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]
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2021-08-27 fixed negative signal names, changed LA connectors, added (and labeled) backplane connectors
    [gd io proto pcb.sch]
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2021-08-31 flipped first connector on protoboard to match reversed pinout on the main board.
    [gd blackplane proto pcb.kicad_pcb, gd blackplane proto pcb.sch]
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2021-09-03 schooched the left edge over to make mini-usb slightly hang over. added some GND vias through the board. re-routed some 3v3 signals for cleaner routes.
    [gd rp2040 keyboard proto pcb.kicad_pcb]
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2021-09-06 adjusted ground pour around 5V USB in connector. considering moving buffer to make more prototyping room
    [gd rp2040 keyboard proto pcb.kicad_pcb]
2021-09-06 added image and readme. added more prototyping holes after moving buffer
    [gd rp2040 keyboard proto pcb.kicad_pcb, gd rp2040 keyboard proto pcb.sch]
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2021-10-11 stripping strobe bit is still not working
    [IIe-keyboard_emulator.c]
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2021-11-22 Moved some parts around. consolidating placements and starting to optimize some routes.
    [servid-rp2040-hdmi proto rev1.kicad_pcb]
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2021-12-31 Reversed prepare_key_value()'s handling of data bus to align with rev2 layout
    [IIe-keyboard_emulator.c]
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2021-12-31 re-enabled write/raise key and fixed scoping for sm_pio variables
    [IIe-keyboard_emulator.c]
2022-01-01 cleaned up comments in PIO. re-ordered #defines in emulator.c. Also fixed a pin setup issue in the sm setup function.
    [IIe-keyboard_emulator.c]
2022-01-01 tested with AD2, but PIO doesn't seem to be running. the '245 doesn't appear to get enabled.
    [IIe-keyboard_emulator.c]
2022-01-14 basic write/raise working with multi-press bug
    [IIe-keyboard_emulator.c]
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2022-01-31 quick fix to stop crashing during boot. (not sure why the PIO state machine was getting touched twice for raise key, commented it out once.)
    [IIe-keyboard_emulator.c]
2022-01-31 fixed Headphone sense before generating gerbers
    [gd audio proto pcb.kicad_pcb, gd audio proto pcb.kicad_sch]
2022-01-31 small board to fix crystal layout on MEGA-II
    [gd rev2 crystalposer.kicad_pcb, gd rev2 crystalposer.kicad_sch]
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2022-02-09 Created PDF of Backplane rev1 and archived it to work on rev2
    [gd blackplane proto pcb.kicad_pcb, gd blackplane proto pcb.sch]
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2022-02-11 fixed the keyboard bug, the one where it wouldn't keyboard anymore
    [IIe-keyboard_emulator.c, kbd_pio_handler.c]
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2022-02-11 constant for 3-finger reset
    [IIe-keyboard_emulator.c]
2022-02-12 clear keyboard queue on MEGA reset
    [IIe-keyboard_emulator.c]
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2022-02-18 ibom for audio and adding some hierarchical labels (wrong branch)
    [gd audio proto pcb-rev1 bad footprint.kicad_pcb, gd audio proto pcb.kicad_sch, gd rev3.kicad_sch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]
2022-02-18 temp keyboard Cxxx crash fix
    [IIe-keyboard_emulator.c]
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2022-02-21 swapped from pico to RP2040--yay
    [gd vga pico proto pcb.kicad_pcb, gd vga pico proto pcb.kicad_sch]
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2022-02-24 added test point for GPIO2 (former KSEL0) -- Tim said I could!
    [gd rp2040 keyboard proto pcb.kicad_pcb, gd rp2040 keyboard proto pcb.kicad_sch]
2022-03-11 fixing USB host init
    [IIe-keyboard_emulator.c]
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2022-03-19 minor fixes and compacting the floorplan. stacked 5V supplies for maximum minimage.
    [gd power supply board pcb.kicad_pcb, gd power supply board pcb.kicad_sch, mega5v.kicad_sch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]
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2022-03-21 cleaned up silks. minor fixes
    [gd power supply board pcb.kicad_pcb, gd power supply board pcb.kicad_sch]
2022-03-21 added a key/finger on the unused pads. also added polygon to ensure no mask on the edge connector
    [gd power supply board pcb.kicad_pcb]
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2022-04-25 corrected pio restart code (thx balika)
    [dma-vga-test.c]
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2022-04-25 now this one is the corrected memory dump. thanks edo.
    [dma-vga-test.c]
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2022-04-25 qol fixes to py converter
    [txt_dump_to_png.py]
2022-04-27 fixed serial and stand-alone mode for python decoder
    [megaII_to_png.py]
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2022-04-28 after crash commit. arranging high-level sheet signals (and added audio circuit)
    [Audio.kicad_sch, gd rev3.kicad_pcb, gd rev3.kicad_sch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]
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2022-04-28 added missing Flash to 2040 circuits and sync'd title blocks
    [Audio.kicad_sch, gd rev3.kicad_sch, iwm.kicad_sch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]
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2022-05-10 Routed Input section (still need swtich) and started first supply. Cleaned up stuff near SW nodes.
    [gd power supply board pcb.kicad_pcb, gd power supply board pcb.kicad_sch]
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2022-05-13 fixed earphone jack -- it tried to get away
    [gd rev3.kicad_pcb]
2022-05-13 fixed edge cut and removed BE logo
    [gd power supply board pcb.kicad_pcb]
2022-05-14 fixed minor drc issues and updated exlcusions for edge connector
    [gd power supply board pcb.kicad_pcb]
2022-05-14 more clean ups. output caps on both 5v supplies and zones around -12v chip
    [gd power supply board pcb.kicad_pcb]
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2022-05-18 started vga and gameport rough route - may remove vga-usb and move earphone to front
    [game_port.kicad_sch, gd rev3.kicad_pcb, gd rev3.kicad_sch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]
2022-05-19 need to move vga to prevent long 14M route
    [gd rev3.kicad_pcb]
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2022-05-23 moved some pasives to back side, looking for more board dimension optimizations
    [gd rev3.kicad_pcb]
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2022-05-24 replaced slot connector
    [gd rev3.kicad_pcb, gd rev3.kicad_sch, slot.kicad_sch]
2022-05-24 aux mem, changed slot, fixed iwm, and RAM addr buses
    [gd rev3.kicad_pcb, video.kicad_sch]
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2022-05-27 started work on kbd2040 section, need to define a lot of IO
    [decoder.kicad_sch, gd rev3.kicad_pcb, gd rev3.kicad_sch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]
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2022-06-06 237: audio placement swapped, now drc check
    [gd rev3.kicad_sch, rp2040-keyboard.kicad_sch]
2022-06-06 230: solder pads to swap RX/TX between KBD and VID
    [gd rev3.kicad_sch, rp2040-keyboard.kicad_sch, video.kicad_sch]
2022-06-06 231: Fixed 5V_2040 reference value
    [gd rev3.kicad_sch, rp2040-keyboard.kicad_sch, video.kicad_sch]
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2022-06-07 Fixed Gameport 556/558 circuit. Near final silk.
    [game_port.kicad_sch, gd rev3.kicad_sch, mega-6502.kicad_sch]
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2022-06-09 Added bulk poly-ta for rails. realized rear connectors may be too close together.
    [power.kicad_sch]
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2022-06-09 Spaced out rear connectors, fixed some labels.
    [gd rev3.kicad_sch, rp2040-keyboard.kicad_sch]
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2022-07-17 fixed 2nd pio prg defines
    [main.cpp]
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2022-08-07 fixed bound issue with audio volume
    [IIe-keyboard_emulator.c, mcp4541.c, power_sequence.c]
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2023-03-11 resolved ERC errors, like fixing en245...wth?
    [gd io proto pcb.kicad_sch]
2023-03-11 resolves #57. now there is a 2-pin header for dev select (and a pin to probe with logic analyzer.) also fixed an issue with the 245 enable signal (whoops.)
    [gd io proto pcb.kicad_pcb, gd io proto pcb.kicad_sch]
2023-03-11 fixed sbus signals (#18)
    [gd io proto pcb.kicad_pcb, gd io proto pcb.kicad_sch]
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2023-09-23 Convert MegaII Breakout to KiCad 7 (with issues)
    [MegaII Breakout.kicad_pcb, MegaII Breakout.kicad_sch]
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2023-10-19 ERC Cleaned and resolved previously unnoticed issues.
    [Audio.kicad_sch, decoder.kicad_sch, game_port.kicad_sch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]
2023-10-19 changed erc corrected to rev3b
    [Audio.kicad_sch, decoder.kicad_sch, game_port.kicad_sch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]
2023-10-19 replaced rev3 (I copied the files, I know, it's bad, but there it is.)
    [Audio.kicad_sch, decoder.kicad_sch, game_port.kicad_sch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]
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2023-12-01 added no-load pads for SW2 and SW3 fixes #60
    [game_port.kicad_sch]
2023-12-01 placed IWM EN Qs, but need to fix 5V for them
    [iwm.kicad_sch]
2023-12-01 added Linear for Decoder to fix #69
    [decoder.kicad_sch]
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
